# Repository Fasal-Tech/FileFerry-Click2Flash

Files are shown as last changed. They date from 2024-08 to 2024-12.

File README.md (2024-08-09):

# 🚀 FileFerry-Click2Flash

A compact and portable tool designed for easy factory programming of your IoT product. 🌐 Transfer files, binary images, security credentials, or certificates from an SD card or from a Serial terminal over USB to a target SPI flash IC with just a click of a button. 🎯

This repository contains all the necessary files to manufacture your own samples from JLCPCB (or a vendor of your choice) and start using it right away

The included firmware source code and compiled binaries can be used right out of the box! 🛠️ You can also modify the design and code and build your own custom product. ✨

## Product Image

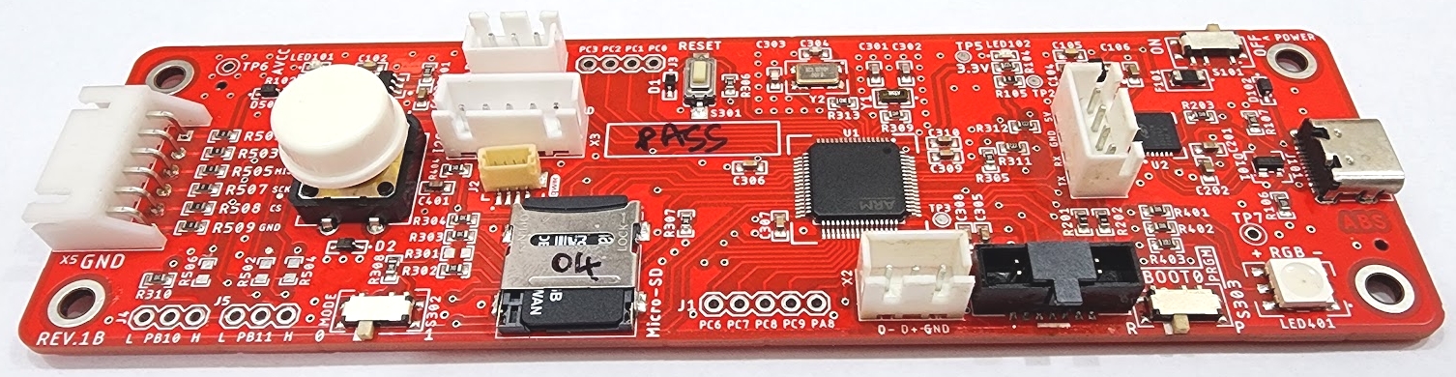
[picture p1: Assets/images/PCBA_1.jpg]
FileFerry-Click2Flash PCB

The "FileFerry-Click2Flash" PCB.

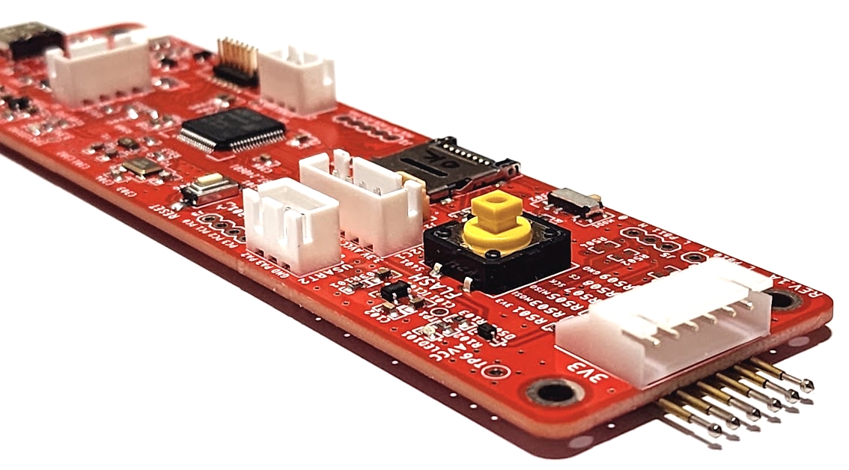
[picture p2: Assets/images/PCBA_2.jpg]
FileFerry-Click2Flash PCB with pogo pins

The "FileFerry-Click2Flash" PCB with the pogo pins.

## 📁 Repository Contents

* **/Hardware 🛠️**
  * All Eagle design files (.brd, .sch)
* **/Firmware 💻**
  * Pre-compiled binaries to flash the board
  * Firmware source code (STM32Cube IDE, HAL) that you can use to modify the functionality
* **/Manufacturing 🏭**
  * All manufacturing files, including Gerber, BOM, PnP_XY, and prototype manufacturing files (Order BOM and PnP) that can be used to order directly from JLCPCB for a complete PCBA job.
* **/Assets 📸**
  * GitHub assets like images and other resources
* **/Demo 📸**
  * Demonstration resources to compile the firmware, flash it to the "FileFerry-Click2Flash" board and use it.

## 🔍 What is FileFerry-Click2Flash?

In its simplest form, FileFerry-Click2Flash is a low-cost, portable hardware jig that allows you to flash any external SPI flash IC (like the W25Q64JVSSIQ). 🛠️

You can transfer data in one of two ways:

1. Store your file/data in the onboard micro SD card. 💾
    1. Example: Production firmware images, common security tokens, certificates, etc.
2. Transfer the files from an external computer over UART using the X-modem protocol. 🔄
    1. Example: Device-specific unique keys, device-specific CA certificates, UUID tokens, etc.

You can do all of this with just a click of the onboard button! 🎯

## 🚀 Why is "FileFerry-Click2Flash" Needed? 🛠️

In today's fast-paced manufacturing environment, the need for efficient, reliable, and cost-effective tools is paramount. Traditional methods of programming SPI flash ICs, such as using J-link SPI programmers or bed-of-nails jigs, often involve expensive, bulky, and complex setups that are not easily adaptable to different production scenarios. 😓

This is where FileFerry-Click2Flash comes in! 🎉 It addresses the gap between high-cost, inflexible tools and the need for a versatile, portable, and user-friendly solution. Whether you are flashing firmware or transferring security credentials, or unique device identifiers, FileFerry-Click2Flash offers an ultra-low-cost alternative that is not only easy to use but also highly customizable. The ability to transfer files via an onboard SD card or over UART using the X-modem protocol provides flexibility in various production environments, making it a robust and indispensable tool for manufacturers, developers, and technicians alike. ⚙️💻

With its customizable connector interface and portable design, this tool simplifies the flashing process, reducing both the time and costs associated with traditional methods. FileFerry-Click2Flash is the modern solution to the challenges faced in programming SPI flash ICs, ensuring that the process is as seamless and efficient as possible. 🖊️💡

## 💰 Manufacturing Cost Breakdown

We got 5 quantity PCBA samples from JLCPCB. (We are in no way affiliated with JLCPCB—it's just convenient to manufacture quick prototypes with them!) 🚀

* Total cost with Shipping (PCB + PCBA): $132.49 📦
* Landing cost with import duties, customs, etc.: INR 14,000.00 (for 5 pieces) 💸
* Cost per board: INR 2,800.00 (includes 6 extra pogo pins, hand soldered later) 🛠️
* At a cost of INR 2,800.00 (~ USD 33.00), we have a SPI flasher with additional functionalities like UART transfer.
  
🔄 Compare this with a J-Flash SPI programmer at ~ USD 330.00 or a Bed of nails test jig at ~ USD 500.00.
🤔 Which would you choose?

## High Level Working

Let's look at how this works.

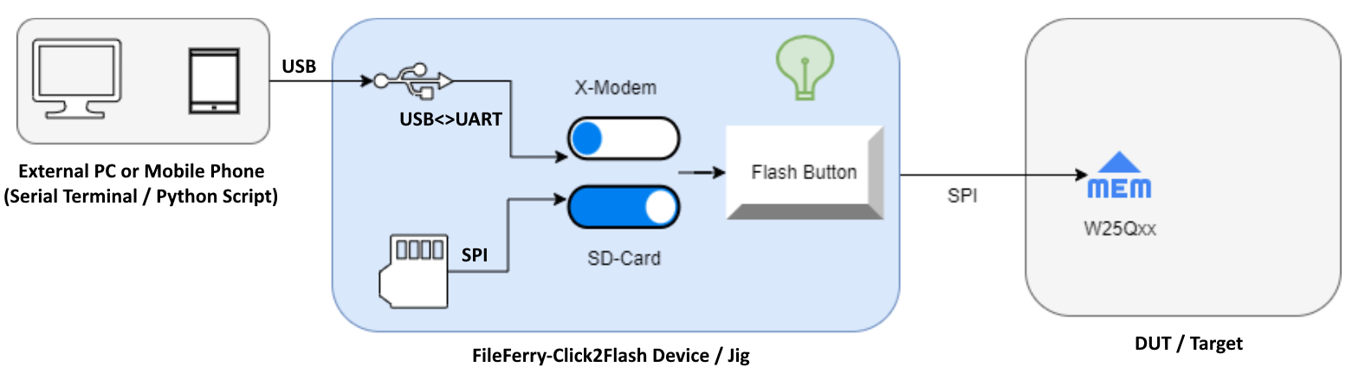
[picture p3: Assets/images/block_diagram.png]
High level block diagram

The "FileFerry-Click2Flash" system block diagram.

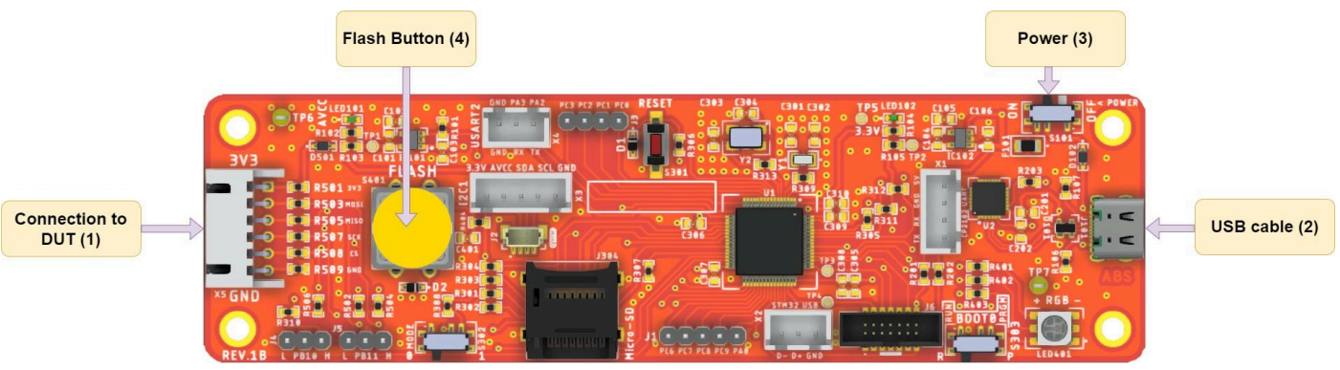
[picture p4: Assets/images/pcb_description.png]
PCB Description

The "FileFerry-Click2Flash" PCB points

### There are two ways (currently supported) to transfer files to the target SPI Flash

### 1. Using the onboard micro SD card (Files need to be on the SD card)

  1. Simple copy the file you want to transfer to the external SPI Flash into the SD card (Example a production binary)
  2. Modify the given source code to use the file name and build the code
  3. Flash the code to the "FileFerry-Click2Flash" board
  4. Insert the SD Card, power up the board and click the "Flash" button for the flashing to take place
  5. you can monitor the progress on the RGB LED as well as debug logs on the USB-UART

### 2. Using a PC client over USB (you will need a Software client to initiate transfer)

  1. No re-programming needed.
  2. Slide the "Mode Switch" S302 to "Mode 1". This will activate UART X-Modem transfer. (Current firmware supports X-modem. Can be modified to any thing else).
  3. Open a terminal program of your choice. The terminal program has to support "File Transfer" functionality.
  4. We use TeraTerm. So open TeraTerm.
  5. Connect to the proper COM port. Use BAud as 115200,8N1.
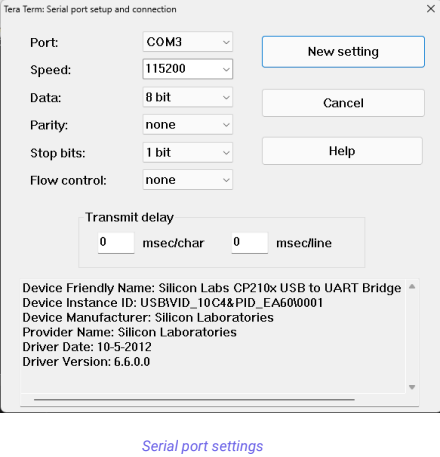
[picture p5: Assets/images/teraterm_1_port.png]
Teraterm Window
  
  Teraterm Open

  6. Go to File-> Transfer -> XMODEM -> Send -> [Check Option 1K] + Select file.
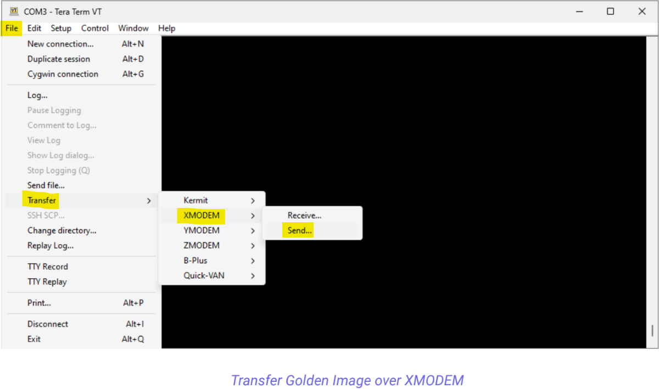
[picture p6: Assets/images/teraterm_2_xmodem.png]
Teraterm file selection
  
  Transfer setting

  7. Select your file and click "Open".
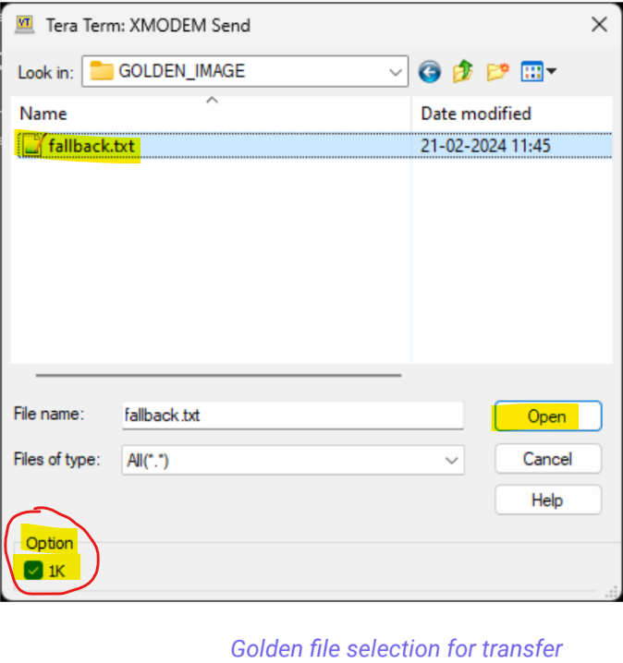
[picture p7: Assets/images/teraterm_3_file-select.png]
Teraterm file selection
  
  File Selection

  8. The file transfer will start.
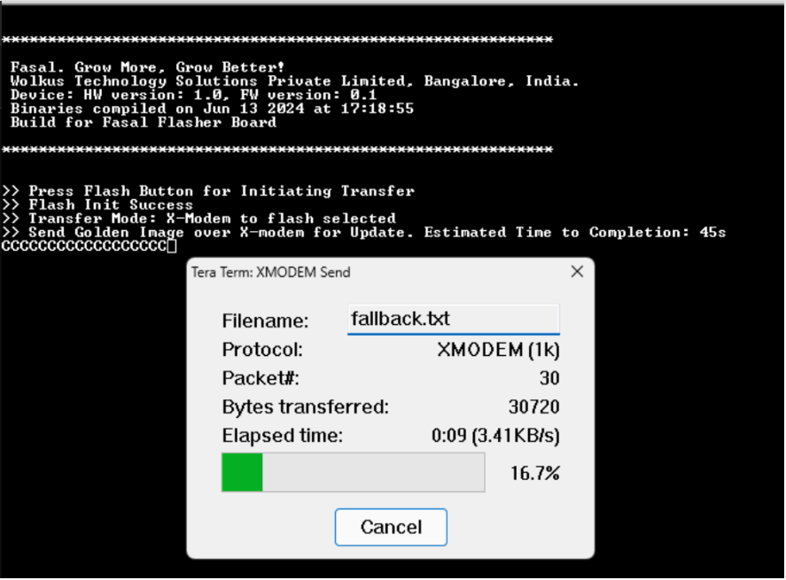
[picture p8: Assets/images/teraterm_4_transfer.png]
Teraterm file selection
  
  File Transfer

## What type of Files can I transfer?
The sky is the limit really. Some common examples are:

1. Transferring the production "Golden Image" of the product where the end product's bootloader performs a DFU from the binaries available in the Flash IC. (You can extend this for implementing OTA).
2. Transferring unique device CA certificates from a PC based on the device serial number. (Scan barcode, generate unique CA certificate in the PC application, transfer it to the device over USB UART).
3. Transferring audio files, JSON configuration files, etc.

## Can I modify the hardware?

You have the design files with you. You can do anything! If you are a student or a DIY'er, here are some ideas to use the hardware:

1. Use as a STM32F103 development kit
2. Use it as a data-logger. Examples:
   * Connect an I2C sensor (there is a QWIIC port for easy connection. There is also a JST port with controlled power) and modify the STM32 code to read from the sensor and store it in the onboard SD card.
   * You can connect a SPI sensor as well.
3. Use the additional UART2 port to connect a GPS receiver and modify the STM32 code to receive the GPS NMEA strings, parse it and store it in the onboard SD card.
4. RFID access control anyone? Interface a RFID reader over UART/I2C/SPI (RC522 or PN532 or similar), have a master list of RFID numbers stored in the SD card. Connect a relay to a free GPIO and give access control to the room.

Limitless possibilities!

## 📜 License Information
The hardware and firmware are released under the MIT License. 📝 The code is beerware; if you see me (or any other Fasal employee) at the local, and you've found our code helpful, please buy us a round! 🍻

Distributed as-is; no warranty is given. ⚠️ Read the License file for complete licensing information.

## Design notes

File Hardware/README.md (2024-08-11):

FileFerry-Click2Flash - Hardware
========================================
This directory will contain the hardware design files for the 'FileFerry-Click2Flash project.

# ECAD Tool #
Autodesk Eagle 9.6.2

# Repository Contents #
* **/Fasal-P506-Rev1B-SPI_Flash_Writer_Jig** - All Eagle design files and manufacturing files for the main product "FileFerry-Click2Flash" (.brd, .sch)
* **/Fasal-RD510 - SPI Flash Writer pogo pcb** - Eagle design files and manufacturing files for optional pogo pin PCB to create a test jig

# Hardware Bloack Diagram

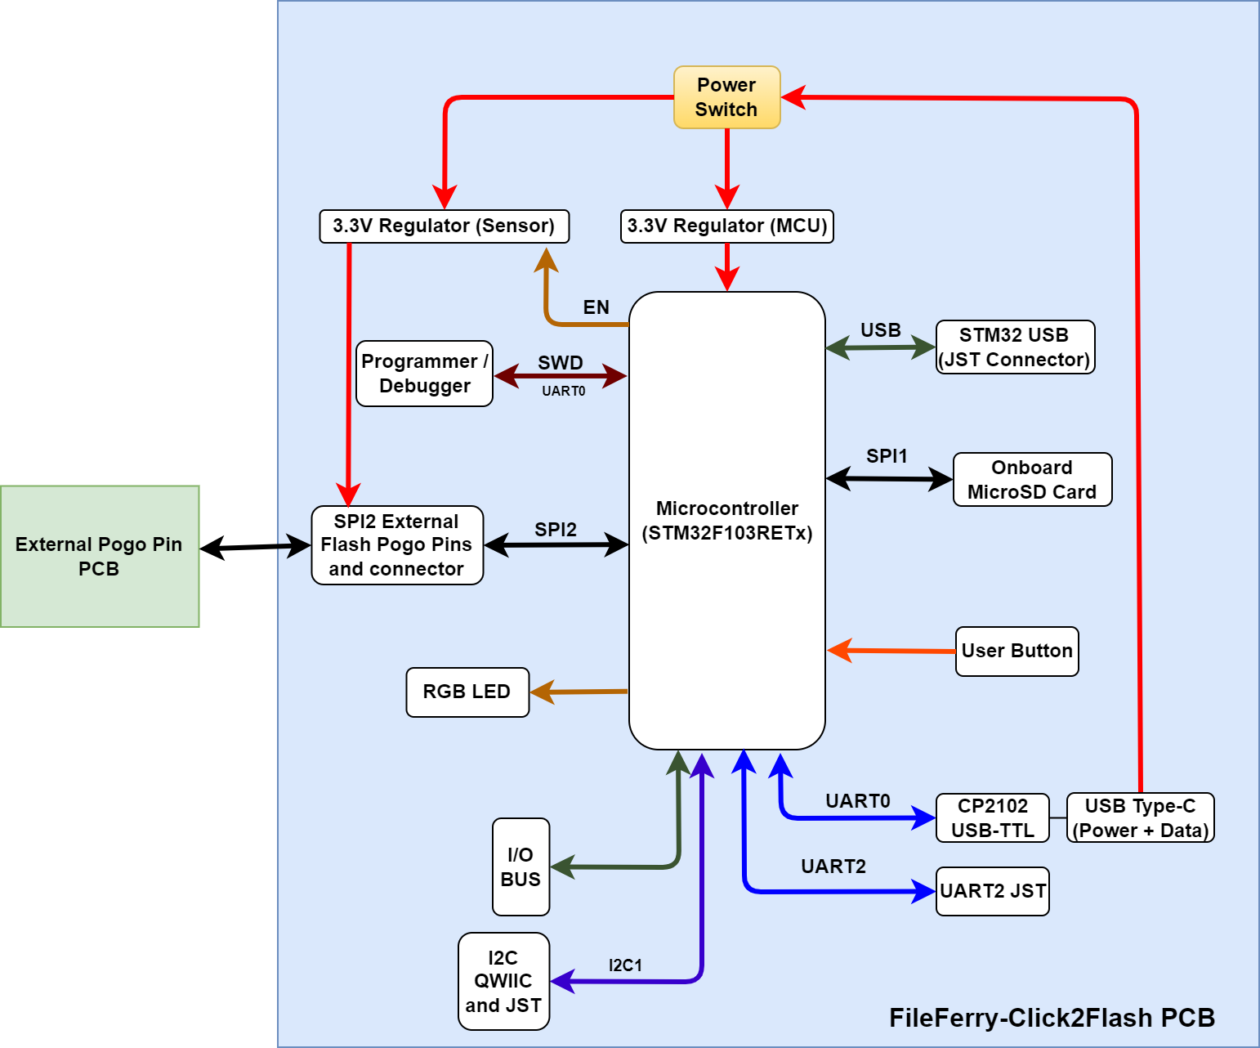
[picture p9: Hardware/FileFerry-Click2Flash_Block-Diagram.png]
Hardware Bloack Diagram


## Contact-Me

- <abhaysbharadwaj@gmail.com> over E-Mail
- [Abhay S Bharadwaj](https://www.linkedin.com/in/abhaysbharadwaj/) over LinkedIn

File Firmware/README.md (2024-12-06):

# Fasal Flasher {#mainpage}

This repository contains Fasal Flasher Source Code. Dive right into the codebase through @ref AppFasal_Run invoked in @ref main.c !

## Table of contents

- [Context](#context)
- [Project-structure](#project-structure)
- [Code-flow](#code-flow)
- [Build-Instruction](#build-instruction)
- [Documentation](#docs)
- [Contact-Me](#contact-me)

## Context

Fasal Flasher is an Internal tool meant as a production floor Aid. Its primary purpose is to update the contents flash IC
W25Qxx either with the contents of the Fasal Flasher onboard SD-Card or over a serial terminal over XModem protocol.
The device has the following salient features

1. Powered by USB either through PC, Mobile phone or any USB source
2. File Input from either Serial console through USB connector or SD-Card
3. Slide switch to select between file source of SD-Card and Serial console (X-modem)
4. The W25Qxx flash IC in external board is powered through the Fasal Flasher and programmed over SPI
5. PushButton to trigger the transfer in the configured Mode
6. Tri-Color LED for visual indication about the process result
7. Logs over the same USB cable with information about the running application
8. File Integrity check via CRC in case of SD-Card transfer mode
9. File Integrity check inbuilt via XModem protocol in case of XModem transfer mode

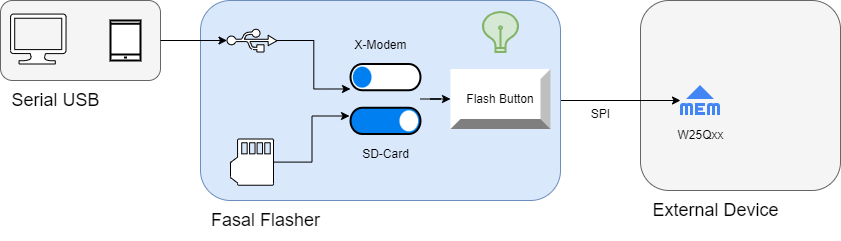
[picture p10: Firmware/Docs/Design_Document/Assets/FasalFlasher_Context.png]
Fasal Flasher Usage


## Project-structure

1. The project is divided into the following folders
2. @ref SourceCode/FasalFlasher/Core : Contains CubeMX Generated Files utilizing the STM HAL. These files are mostly unmodified and used as is
3. @ref SourceCode/FasalFlasher/Drivers : STM HAL files
4. @ref SourceCode/FasalFlasher/FATFS : FatFS library
5. @ref SourceCode/FasalFlasher/Middlewares : Contains STM crypto library and FatFS library, used as is without any modifications
6. @ref SourceCode/FasalFlasher/User_Files : All custom code for the Fasal Application is present in this folder
    1. @ref SourceCode/FasalFlasher/User_Files/AppCommon : Contains modules used across the whole application, these include
        1. @ref SourceCode/FasalFlasher/User_Files/AppCommon/AppIndication : Controls visual indication presented by the board
        2. @ref SourceCode/FasalFlasher/User_Files/AppCommon/AppUtility : Provides SoftTimer, Circular Buffer and other Misc utility functions
        3. @ref SourceCode/FasalFlasher/User_Files/AppCommon/CommonDefinitions : Non project specific data structures and Macros
        4. SourceCode/FasalFlasher/User_Files/AppCommon/ConfigSetting : Module to check Board HW configuration
        5. SourceCode/FasalFlasher/User_Files/AppCommon/PushButton : PushButton module
    2. @ref SourceCode/FasalFlasher/User_Files/AppConfiguration : Application configuration options are controlled here
    3. @ref SourceCode/FasalFlasher/User_Files/AppFasal : Application code module
        1. @ref SourceCode/FasalFlasher/User_Files/AppFasal/AppHelper : Helper functions for main application
        2. @ref SourceCode/FasalFlasher/User_Files/AppFasal/AppResetAndError : Error handling and reset management
    4. @ref SourceCode/FasalFlasher/User_Files/AppInterface : Modules that help Interface Sensor Adapter with external peripherals
        1. @ref SourceCode/FasalFlasher/User_Files/AppInterface/Console : Debug console for getting controlling as well as reading logs
        2. @ref SourceCode/FasalFlasher/User_Files/AppInterface/xModem : xModem module built on top of UART based console module
    5. @ref SourceCode/FasalFlasher/User_Files/AppInterrupts : Callbacks and other application specific callbacks coupled closely with board specific peripherals
    6. @ref SourceCode/FasalFlasher/User_Files/AppStorage : OnBoard storage module API
        1. @ref SourceCode/FasalFlasher/User_Files/AppStorage/AppFlashFS : Filesystem based on LittleFS file system built atop W25Qxx flash IC
        2. @ref SourceCode/FasalFlasher/User_Files/AppStorage/AppSDFS : Filesystem based on FatFS file system built atop SPI based SD-Card

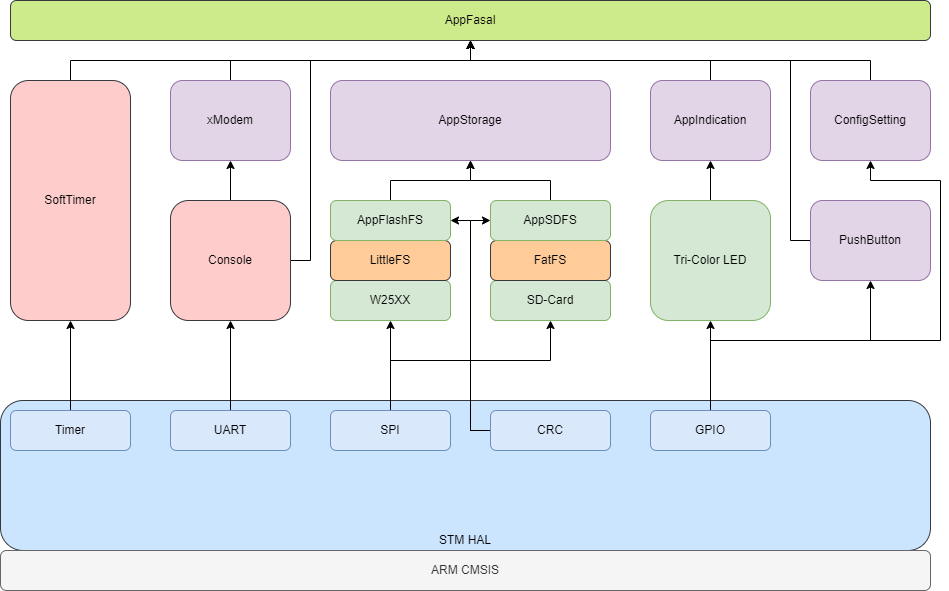
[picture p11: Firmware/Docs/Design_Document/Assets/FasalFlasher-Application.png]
Application


```text
+---BUILD_DEBUG
+---BUILD_PROD
+---Core
¦   +---Inc
¦   +---Src
¦   +---Startup
+---Drivers
¦   +---CMSIS
¦   ¦   +---Device
¦   ¦   ¦   +---ST
¦   ¦   ¦       +---STM32F1xx
¦   ¦   ¦           +---Include
¦   ¦   ¦           +---Source
¦   ¦   ¦               +---Templates
¦   ¦   +---Include
¦   +---STM32F1xx_HAL_Driver
¦       +---Inc
¦       ¦   +---Legacy
¦       +---Src
+---FATFS
¦   +---App
¦   +---Target
+---Middlewares
¦   +---Third_Party
¦       +---FatFs
¦           +---src
¦               +---option
+---User_Files
    +---AppCommon
    ¦   +---AppIndication
    ¦   ¦   +---TriColorLED
    ¦   +---AppUtility
    ¦   ¦   +---AppProfiler
    ¦   ¦   +---SoftTimer
    ¦   +---CommonDefinitions
    ¦   +---ConfigSetting
    ¦   +---PushButton
    +---AppConfiguration
    +---AppFasal
    ¦   +---AppResetAndError
    +---AppInterface
    ¦   +---Console
    ¦   +---xModem
    +---AppInterrupts
    +---AppStorage
        +---AppFlashFS
        ¦   +---LittleFS
        ¦   +---W25Qxx
        +---AppSDFS

```

## Code-flow

1. The code flow and the corresponding modules are documented in this section
2. The code starting point is @ref main. All HAL modules are initialized here along with Application level code housed in @ref AppFasal.h
3. @ref AppFasal_Init Initializes the application, sends startup message and sets up the TriColorLED, console and startup timer
4. The function @ref AppFasal_Run is the application state-machine that drives the application
    1. Module level initialization is carried out in the first step
    2. The application then waits for the user to press the flash user button
    3. External flash is then initialized before progressing to the file transfer phase
    4. Depending on the hardware slide switch setting, the device can then proceed in one of the following modes
        1. SD-Card Transfer Mode:
            1. SD-Card is initialized and it is ensured that the Golden image is present
            2. Golden image is transferred from the SD card to the external flash
            3. CRC of the same file in SD-Card and in the now transferred flash are computed and checked against each other
        2. XModem Transfer Mode:
            1. File Must be transferred over XModem 1K option though a serial terminal [Baud: 115200, Data: 8b, Stop Bit: 1b]
    5. In either mode, On successful reception of Golden Image, the Firmware then enters the termination stage, indicates success and waits on the flash user button stage
    6. In either mode failure of any of the steps prior to successful transfer results in the application state-machine indicating the failure reason and jumping back flash user button stage

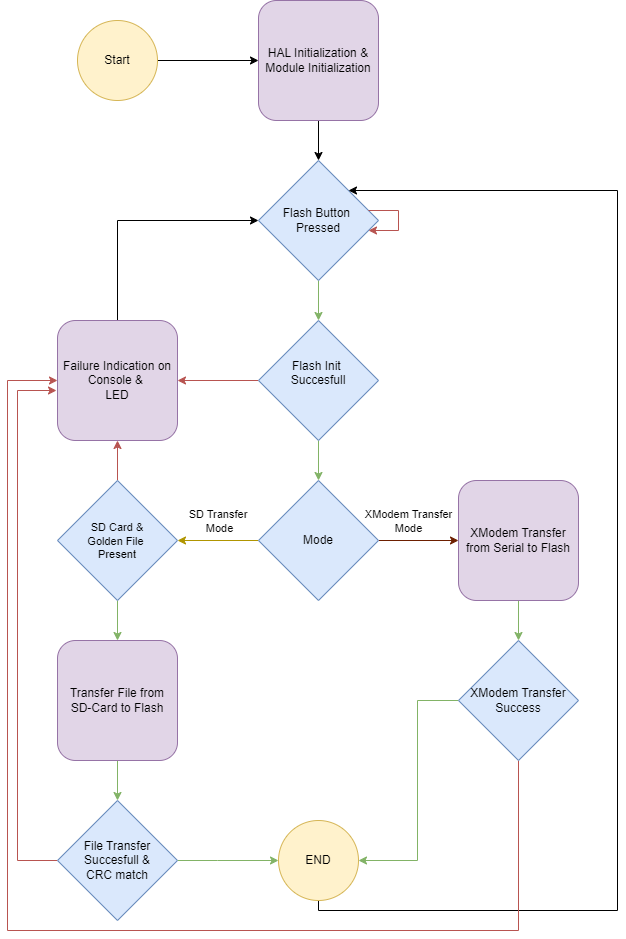
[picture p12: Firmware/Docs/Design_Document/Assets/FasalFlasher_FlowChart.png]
APP


## Build-Instruction

1. Built using CubeIDE Version: 1.15.1 Build: 21094_20240412_1041 (UTC)
2. Both BUILD_DEBUG and BUILD_PROD Uses Linker script STM32f103RETX_FLASH.ld with flash offset of 0x0800 0000, application size set to 512KB
3. The following build configurations are built into the codebase
    1. *BUILD_DEBUG* : Debug build used during development with all debug symbols enabled
        - Optimization level : None
        - Symbols defined : DEBUG | STM32F103xE | USE_HAL_DRIVER

    2. *BUILD_PROD* : Production build for filed use
        - Optimization level : Ofast
        - Symbols defined : NDEBUG | STM32F103xE | USE_HAL_DRIVER
4. @ref SourceCode/FasalFlasher/User_Files/AppCommon/AppConfiguration for changing compile time build features

## Docs

1. Open Index.html in any browser. Files located here @ref Docs/html
2. Latex Generated PDF file is preset at @ref Docs/Design_Document/FasalNode_FirmwareDesignDocument.pdf
3. The documentation can be generated by running batch script @ref make_designdocument.bat at the project root

## Contact-Me

- <vishalbhatta@gmail.com> over E-Mail
- [LinkedIn](https://in.linkedin.com/in/vishal-keshava-murthy-8a2ba1a7)

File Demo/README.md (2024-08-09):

# 🚀 FileFerry-Click2Flash Demonstration

This document demonstrates how FileFerry-click2Flash can be used for your project!

## Table of contents

- [Release_Contents_overview](#release-contents-overview)
- [Setup](#setup)
- [Usage_Instructions](#usage-instructions)
- [DiagnosticsInformation](#diagnostics-information)
- [Build-Instruction](#build-instruction)
- [Documentation](#docs)
- [Contact-Me](#contact-me)

## Context

## Release Contents overview

The prebuilt binaries released are available under the release folder @ref /Firmware/Releases is comprised of

1. APP: Application Binaries
    1. BUILD_DEBUG: Debug Build with all debug symbols and messages enabled for debugging purposes
    2. BUILD_PROD:  Production build optimized for performance. Meant for use on the production floor
2. FasalFlasher_ReleaseNote.pdf: Release Note with details about the build and usage
3. ReadMe.txt: Instructional text document that captures essential Release information

## Setup

The following steps are to be followed with a new FileFerry-Click2Flash device

### Software and tools used

1. [ST Cube Programmer](https://www.st.com/en/development-tools/stm32cubeprog.html) : To upload binaries to device
2. [TeraTerm](https://teratermproject.github.io/index-en.html) : Or equivalent serial monitor tool with XModem protocol

### External device (Target) setup

1. The external device (Target) needs to be empty prior to usage with Fasal Flasher. If a program is running on it, it will interfere with the flashing operation.
2. You can put the device in "suspend" mode. (Example: Use BOOT0 if the target has a STM32 MCU to halt program execution).
3. Alternately, erase the MCU's (or MPU's) internal Flash program.

### FileFerry-Click2Flash device SD-Card SetUp

1. The precompiled binary of the FileFerry-Click2Flash expects a file name "Fallback.txt" in the SD Card to be present. This "Fallback.txt" gets transferred to the Target SPI Flash.
2. Note: ".txt" is just a file format notation and not an actual text file. The file in the demo is a ".srec" compiled binary that can be used to perform DFU of a target STM32 MCU. The .srec compiled binary is renamed as "Fallback.txt".
3. Copy the file "Fallback.txt" into an SD-card and insert the same into the FileFerry-Click2Flash device. Please note that that any file that needs to be transferred must be named Fallback.txt for the file to be recognized by the FileFerry-Click2Flash.
4. You may change the file name expected by the FileFerry-Click2Flash, recompile the code and upload the new code to the FileFerry-Click2Flash device. You can then rename the SD card file accordingly.

### Burning the Application code to a fresh FileFerry-Click2Flash PCB

1. Insert the above SD card (with the "fallback.txt" file in it).
2. Connect a Type-C USB and slide the power switch to power on the device.
3. Connect a STLink V3 minie on the programming header.
4. Open the STM32cube Programmer.
5. First, erase the complete device using Full chip erase option under Erasing and programming section in the side-Menu
6. Select & load application file *App/PROD/FasalFlasher_Vx_y_PROD.srec* to device

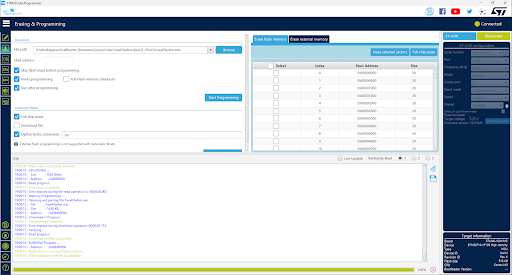
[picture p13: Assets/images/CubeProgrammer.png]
Full chip erase & Flash program


## Using the FileFerry-Click2Flash device

1. Ensure that the device is powered over USB and the power switch is ON, and that the set up is complete as instructed in the application setup 
2. The operation mode can be selected as either SD-Card mode or XModem mode though the slide switch. The two modes are described below 
3. Ensure that the device whose Flash needs to be programmed is not running any application. Disconnect the power source for the external board and connect to the flash SPI interface using the Pogo interface
4. The application state will be indicated in accordance with []

### SD-Card Mode

1. A correctly set up device will wait for the User Flash button button  
2. Once the Button is pressed the device will initialize both the onboard SD-Card interface and the external flash.
3. The files will be copied, integrity will be checked and the status will be indicated
4. The file transfer status will be indicated over LED and the console

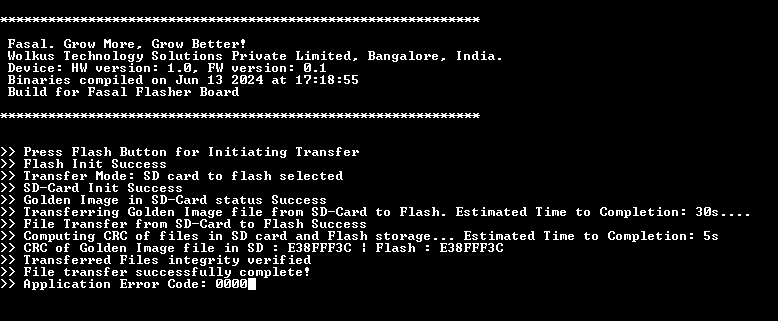
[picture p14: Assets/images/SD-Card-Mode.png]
SD-Card Mode


### XModem Mode

1. A correctly set up device will wait for the User Flash button button  
2. Once the Button is pressed the device will wait for the golden image file over the serial interface
3. Launch Serial USB terminal, select the appropriate com-port and use the following Serial settings 
    1. Baud Rate : 115200
    2. Data : 8 bit
    3. Speed : 115200
    4. Stop bits : 1 bit
    5. Flow control : none
4. The file transfer status will be indicated over LED and the console
5. XModem mode can be used either over PC though serial terminal programs like TeraTerm or cell phone over USB serial terminal.

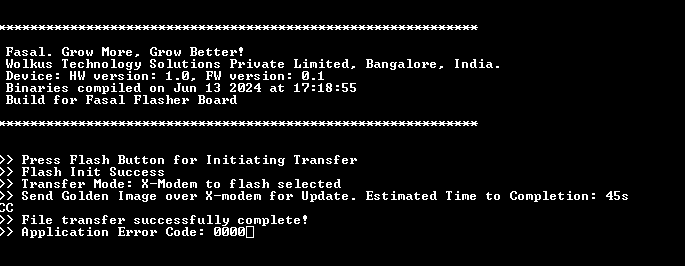
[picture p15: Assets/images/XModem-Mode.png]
X-Modem Mode


## Diagnostics Information

### App State Indication

The application status is indicated by the On board TriColor LED during program execution. The application states, their meaning and corresponding indication state is documented below

| App State | Indication |
| --- | --- |
|eFASAL_APP_INIT | eIND_BLUE_250MS |
|eFASAL_APP_BUTTON_WAIT | eIND_BLUE_500MS |
|eFASAL_APP_SD_INIT | eIND_BLUE_1000MS |
|eFASAL_APP_SD_CHECK | eIND_BLUE_1000MS |
|eFASAL_APP_FLASH_INIT | eIND_BLUE_1000MS |
|eFASAL_APP_MODE_SELECTION | eIND_BLUE_1000MS |
|eFASAL_APP_SD_FLASH_TRANSFER | eIND_YELLOW_1000MS  |
|eFASAL_APP_XMODEM_TRANSFER | eIND_YELLOW_1000MS  |
|eFASAL_APP_CRC_COMPARE | eIND_YELLOW_1000MS  |
|eFASAL_APP_TRANSFER_SUCCESS | eIND_GREEN_0 |
|eFASAL_APP_SD_FAIL | eIND_RED_250MS |
|eFASAL_APP_SD_FILE_FAIL | eIND_RED_250MS |
|eFASAL_APP_TRANSFER_FAIL | eIND_RED_250MS |
|eFASAL_APP_CRC_FAIL | eIND_RED_250MS |
|eERR_ARM_FAULT | eIND_RED_250MS |
|eFASAL_APP_END | eIND_RED_250MS |
|eFASAL_MAX_STATE | eIND_RED_250MS |

### Error Codes

The application also supporters error codes to indicate specific error conditions. These are captured below along with the indication if present

| Error Code | Error |
| --- | --- |
|0x0000 | eERR_NO_ERRORS |
|0x0001 | eERR_SDCARD_NOT_FOUND |
|0x0002 | eERR_SDCARD_FILE_NOT_FOUND |
|0x0004 | eERR_FLASH_NOT_FOUND |
|0x0008 | eERR_FLASH_TRANSFER_FAILURE  |
|0x0010 | eERR_CRC_FAILURE |
|0x1000 | eERR_STM_HAL_FAILURE |
|0x2000 | eERR_ARM_FAULT |
|0x4000 | eERR_ASSERTION_FAILURE |
|0x8000 | eERR_SLEEP_FAILURE |

## Build-Instruction
If you want to modify the firmware functionality, you can re-build the code for the FileFerry-Click2Flash device using these steps:
1. Built using CubeIDE Version: 1.15.1 Build: 21094_20240412_1041 (UTC)
2. Both BUILD_DEBUG and BUILD_PROD Uses Linker script STM32f103RETX_FLASH.ld with flash offset of 0x0800 0000, application size set to 512KB
3. The following build configurations are built into the codebase
    1. *BUILD_DEBUG* : Debug build used during development with all debug symbols enabled
        - Optimization level : None
        - Symbols defined : DEBUG | STM32F103xE | USE_HAL_DRIVER

    2. *BUILD_PROD* : Production build for filed use
        - Optimization level : Ofast
        - Symbols defined : NDEBUG | STM32F103xE | USE_HAL_DRIVER
4. @ref SourceCode/FasalFlasher/User_Files/AppCommon/AppConfiguration for changing compile time build features

## Docs

1. Doxygen files are generated under @ref Docs/html by running the following command in the current folder ```doxygen Doxyfile```
2. The files can be viewed by opening Index.html in any browser. Files located here @ref Docs/html
3. Latex Generated PDF file is preset at @ref Docs/Design_Document/FasalFlasher_FirmwareDesignDocument.pdf

## Contact-Me

- <vishalbhatta@gmail.com> over E-Mail
- [Vishal Keshava Murthy](https://www.linkedin.com/in/vishal-keshava-murthy-8a2ba1a7/) over LinkedIn

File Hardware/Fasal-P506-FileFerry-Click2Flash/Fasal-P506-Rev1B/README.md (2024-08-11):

# FileFerry-Click2Flash - Hardware Files #

This directory contains all the Hardware related files for the main "FileFerry-Click2Flash" Board.

# Repository Contents #
* **/Design_Files**
	* CubeMX Files
	* Change log
	* Design Report
	* Schematic pdf
	* Schematic Source (.sch)
	* Board Source (.brd)
* **/Manufacturing_Files**
	* PCBA BOM (Production Bill of Materials)
	* PCB Assembly Instructions
	* PCB Fabrication Instructions with stackup
	* Gerber Files (.zip)
	* PCB Images and 3D STEP file
	* Pick and Place (PnP_XY) files
* **/Proto_Manufacturing**
	* Use this to get a complete PCBA build from JLCPCB.
	* Gerber Files (same as production gerber)
	* JLCPCB SMT BOM (BOM for LCSC / JLCPCB PCBA)
	* JLCPCT CPL (compoennt placement file. SMD and THT both.)
* **/Testing_Files**
	* Board bring-up Arduino Test Code
	* Board Bring-up test case and report

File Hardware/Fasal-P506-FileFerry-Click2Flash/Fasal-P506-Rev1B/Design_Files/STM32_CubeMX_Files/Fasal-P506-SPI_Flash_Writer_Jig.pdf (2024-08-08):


24/05/2024

Fasal-P506-SPI_Flash_Writer_Jig Project Configuration Report

## 1. Description

### 1.1. Project

Project Name | Fasal-P506-SPI_Flash_Writer_Jig
Board Name | custom
Generated with: | STM32CubeMX 6.11.1
Date | 05/24/2024

### 1.2. MCU

MCU Series | STM32F1
MCU Line | STM32F103
MCU name | STM32F103RETx
MCU Package | LQFP64
MCU Pin number | 64

### 1.3. Core(s) information

Core(s) | Arm Cortex-M3

## 2. Pinout Configuration

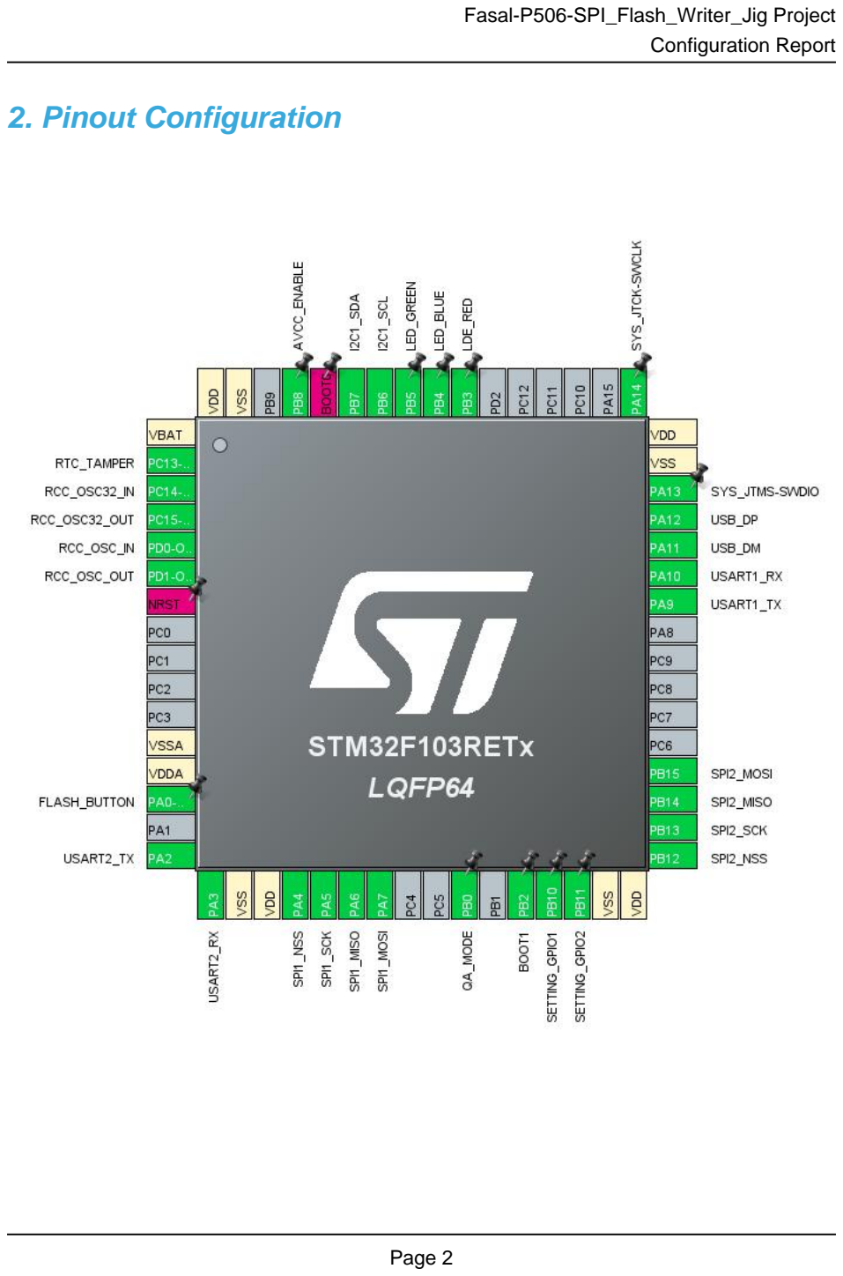
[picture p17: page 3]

## 3. Pins Configuration

Pin Number LQFP64 | Pin Name (function after reset) | Pin Type | Alternate Function(s) | Label
1 | VBAT | Power
2 | PC13-TAMPER-RTC | I/O | RTC_TAMPER
3 | PC14-OSC32_IN | I/O | RCC_OSC32_IN
4 | PC15-OSC32_OUT | I/O | RCC_OSC32_OUT
5 | PD0-OSC_IN | I/O | RCC_OSC_IN
6 | PD1-OSC_OUT | I/O | RCC_OSC_OUT
7 | NRST | Reset
12 | VSSA | Power
13 | VDDA | Power
14 | PA0-WKUP | I/O | GPIO_EXTI0 | FLASH_BUTTON
16 | PA2 | I/O | USART2_TX
17 | PA3 | I/O | USART2_RX
18 | VSS | Power
19 | VDD | Power
20 | PA4 | I/O | SPI1_NSS
21 | PA5 | I/O | SPI1_SCK
22 | PA6 | I/O | SPI1_MISO
23 | PA7 | I/O | SPI1_MOSI
26 | PB0 * | I/O | GPIO_Input | QA_MODE
28 | PB2 * | I/O | GPIO_Input | BOOT1
29 | PB10 * | I/O | GPIO_Input | SETTING_GPIO1
30 | PB11 * | I/O | GPIO_Input | SETTING_GPIO2
31 | VSS | Power
32 | VDD | Power
33 | PB12 | I/O | SPI2_NSS
34 | PB13 | I/O | SPI2_SCK
35 | PB14 | I/O | SPI2_MISO
36 | PB15 | I/O | SPI2_MOSI
42 | PA9 | I/O | USART1_TX
43 | PA10 | I/O | USART1_RX
44 | PA11 | I/O | USB_DM
45 | PA12 | I/O | USB_DP
46 | PA13 | I/O | SYS_JTMS-SWDIO
47 | VSS | Power
48 | VDD | Power
49 | PA14 | I/O | SYS_JTCK-SWCLK

Pin Number LQFP64 | Pin Name (function after reset) | Pin Type | Alternate Function(s) | Label
55 | PB3 * | I/O | GPIO_Output | LDE_RED
56 | PB4 * | I/O | GPIO_Output | LED_BLUE
57 | PB5 * | I/O | GPIO_Output | LED_GREEN
58 | PB6 | I/O | I2C1_SCL
59 | PB7 | I/O | I2C1_SDA
60 | BOOT0 | Boot
61 | PB8 * | I/O | GPIO_Output | AVCC_ENABLE
63 | VSS | Power
64 | VDD | Power

* The pin is affected with an I/O function

## 4. Clock Tree Configuration

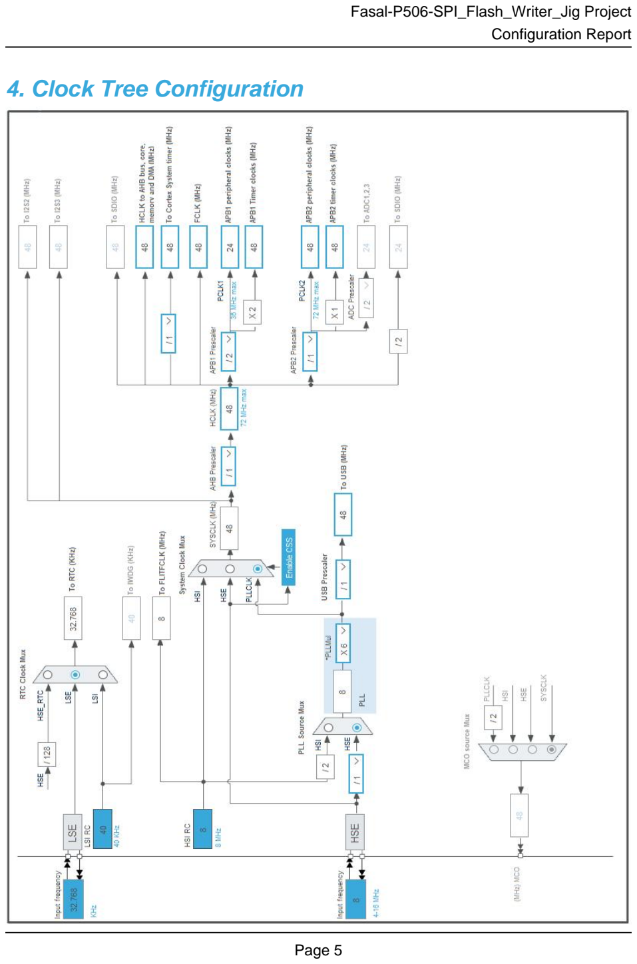
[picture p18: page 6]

## 5. Software Project

### 5.1. Project Settings

Name | Value
Project Name | Fasal-P506-SPI_Flash_Writer_Jig
Project Folder | F:\Fasal_Electronics_Design\Fasal_HW_5p0_Nova_Electronics\Fasal-P506 - SPI
Toolchain / IDE | STM32CubeIDE
Firmware Package Name and Version | STM32Cube FW_F1 V1.8.5
Application Structure | Advanced
Generate Under Root | Yes
Do not generate the main() | No
Minimum Heap Size | 0x200
Minimum Stack Size | 0x400

### 5.2. Code Generation Settings

Name | Value
STM32Cube MCU packages and embedded software | Copy only the necessary library files
Generate peripheral initialization as a pair of '.c/.h' files | No
Backup previously generated files when re-generating | No
Keep User Code when re-generating | Yes
Delete previously generated files when not re-generated | Yes
Set all free pins as analog (to optimize the power consumption) | Yes
Enable Full Assert | No

### 5.3. Advanced Settings - Generated Function Calls

Rank | Function Name | Peripheral Instance Name
1 | SystemClock_Config | RCC
2 | MX_GPIO_Init | GPIO
3 | MX_CRC_Init | CRC
4 | MX_I2C1_Init | I2C1
5 | MX_RTC_Init | RTC
6 | MX_SPI1_Init | SPI1
7 | MX_SPI2_Init | SPI2
8 | MX_USART1_UART_Init | USART1
9 | MX_USART2_UART_Init | USART2
10 | MX_FATFS_Init | FATFS
11 | MX_USB_DEVICE_Init | USB_DEVICE

## 1. Power Consumption Calculator report

### 1.1. Microcontroller Selection

Series | STM32F1
Line | STM32F103
MCU | STM32F103RETx
Datasheet | DS5792_Rev12

### 1.2. Parameter Selection

Temperature | 25
Vdd | 3.3

### 1.3. Battery Selection

Battery | Li-SOCL2(A3400)
Capacity | 3400.0 mAh
Self Discharge | 0.08 %/month
Nominal Voltage | 3.6 V
Max Cont Current | 100.0 mA
Max Pulse Current | 200.0 mA
Cells in series | 1
Cells in parallel | 1

### 1.4. Sequence

Step | Step1 | Step2
Mode | RUN | STOP
Vdd | 3.3 | 3.3
Voltage Source | Battery | Battery
Range | No Scale | No Scale
Fetch Type | FLASH | n/a
CPU Frequency | 72 MHz | 0 Hz
Clock Configuration | HSE PLL | Regulator_LP
Clock Source Frequency | 8 MHz | 0 Hz
Peripherals
Additional Cons. | 0 mA | 0 mA
Average Current | 30.5 mA | 25 µA
Duration | 0.1 ms | 0.9 ms
DMIPS | 90.0 | 0.0
Ta Max | 100.47 | 105
Category | In DS Table | In DS Table

### 1.5. Results

Sequence Time | 1 ms | Average Current | 3.07 mA
Battery Life | 1 month, 15 days, 15 hours | Average DMIPS | 61.0 DMIPS

### 1.6. Chart

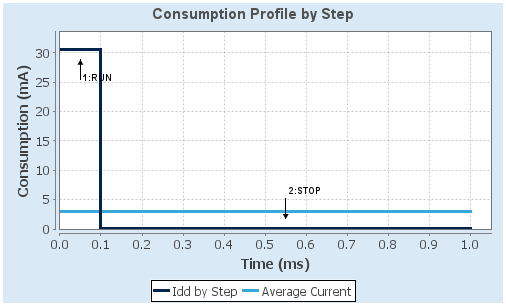
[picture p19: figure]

## 2. Peripherals and Middlewares Configuration

### 2.1. CRC

mode: Activated

### 2.2. I2C1

I2C: I2C
2.2.1. Parameter Settings:

Master Features:

I2C Speed Mode | Standard Mode
I2C Clock Speed (Hz) | 100000
Slave Features:
Clock No Stretch Mode | Disabled
Primary Address Length selection | 7-bit
Dual Address Acknowledged | Disabled
Primary slave address | 0
General Call address detection | Disabled

### 2.3. RCC

High Speed Clock (HSE): Crystal/Ceramic Resonator Low Speed Clock (LSE) : Crystal/Ceramic Resonator
2.3.1. Parameter Settings:

System Parameters:

VDD voltage (V) | 3.3
Prefetch Buffer | Enabled
Flash Latency(WS) | 1 WS (2 CPU cycle)
RCC Parameters:
HSI Calibration Value | 16
HSE Startup Timout Value (ms) | 100
LSE Startup Timout Value (ms) | 5000

### 2.4. RTC

mode: Activate Clock Source

mode: Tamper
2.4.1. Parameter Settings:

Calendar Time:

Data Format | BCD data format
General:
Auto Predivider Calculation | Enabled
Asynchronous Predivider value | Automatic Predivider Calculation Enabled
Output | No output on the TAMPER pin
Tamper:
Tamper Trigger | Rising Edge

### 2.5. SPI1

Mode: Full-Duplex Master
Hardware NSS Signal: Hardware NSS Output Signal
2.5.1. Parameter Settings:

Basic Parameters:

Frame Format | Motorola
Data Size | 8 Bits
First Bit | MSB First
Clock Parameters:
Prescaler (for Baud Rate) | 4 *
Baud Rate | 12.0 MBits/s *
Clock Polarity (CPOL) | Low
Clock Phase (CPHA) | 1 Edge
Advanced Parameters:
CRC Calculation | Disabled
NSS Signal Type | Output Hardware

### 2.6. SPI2

Mode: Full-Duplex Master
Hardware NSS Signal: Hardware NSS Output Signal
2.6.1. Parameter Settings:

Basic Parameters:

Frame Format | Motorola
Data Size | 8 Bits
First Bit | MSB First
Clock Parameters:
Prescaler (for Baud Rate) | 2
Baud Rate | 12.0 MBits/s *
Clock Polarity (CPOL) | Low
Clock Phase (CPHA) | 1 Edge
Advanced Parameters:
CRC Calculation | Disabled
NSS Signal Type | Output Hardware

### 2.7. SYS

Debug: Serial Wire
Timebase Source: SysTick

### 2.8. USART1

Mode: Asynchronous
2.8.1. Parameter Settings:

Basic Parameters:

Baud Rate | 115200
Word Length | 8 Bits (including Parity)
Parity | None
Stop Bits | 1
Advanced Parameters:
Data Direction | Receive and Transmit
Over Sampling | 16 Samples

### 2.9. USART2

Mode: Asynchronous
2.9.1. Parameter Settings:

Basic Parameters:

Baud Rate | 115200
Word Length | 8 Bits (including Parity)
Parity | None

Stop Bits | 1
Advanced Parameters:
Data Direction | Receive and Transmit
Over Sampling | 16 Samples

### 2.10. USB

mode: Device (FS)
2.10.1. Parameter Settings:

Basic Parameters:

Speed | Full Speed 12MBit/s
Power Parameters:
Low Power | Disabled
Link Power Management | Disabled
Battery Charging | Disabled

### 2.11. FATFS

mode: User-defined
2.11.1. Set Defines:

Version:

FATFS version | R0.11
Function Parameters:
FS_READONLY (Read-only mode) | Disabled
FS_MINIMIZE (Minimization level) | Disabled
USE_STRFUNC (String functions) | Enabled with LF -> CRLF conversion
USE_FIND (Find functions) | Disabled
USE_MKFS (Make filesystem function) | Enabled
USE_FASTSEEK (Fast seek function) | Enabled
USE_LABEL (Volume label functions) | Disabled
USE_FORWARD (Forward function) | Disabled
Locale and Namespace Parameters:
CODE_PAGE (Code page on target) | Multilingual Latin 1 (OEM)
USE_LFN (Use Long Filename) | Disabled
MAX_LFN (Max Long Filename) | 255
LFN_UNICODE (Enable Unicode) | ANSI/OEM
STRF_ENCODE (Character encoding) | UTF-8

FS_RPATH (Relative Path) | Disabled
Physical Drive Parameters:
VOLUMES (Logical drives) | 1
MAX_SS (Maximum Sector Size) | 512
MIN_SS (Minimum Sector Size) | 512
MULTI_PARTITION (Volume partitions feature) | Disabled
USE_TRIM (Erase feature) | Disabled
FS_NOFSINFO (Force full FAT scan) | 0
System Parameters:
FS_TINY (Tiny mode) | Disabled
FS_NORTC (Timestamp feature) | Dynamic timestamp
WORD_ACCESS (Platform dependent access option) | Byte access
FS_REENTRANT (Re-Entrancy) | Disabled
FS_TIMEOUT (Timeout ticks) | 1000
FS_LOCK (Number of files opened simultaneously) | 2

### 2.12. USB_DEVICE

Class For FS IP: Mass Storage Class
2.12.1. Parameter Settings:

Basic Parameters:

USBD_MAX_NUM_INTERFACES (Maximum number of supported interfaces) | 1
USBD_MAX_NUM_CONFIGURATION (Maximum number of supported configuration) | 1
USBD_MAX_STR_DESC_SIZ (Maximum size for the string descriptors) | 512
USBD_SELF_POWERED (Enabled self power) | Enabled
USBD_DEBUG_LEVEL (USBD Debug Level) | 0: No debug message
Class Parameters:
MSC_MEDIA_PACKET (Media I/O buffer Size) | 512
2.12.2. Device Descriptor:

Device Descriptor:

VID (Vendor IDentifier) | 1150 *
LANGID_STRING (Language Identifier) | English(United States)
MANUFACTURER_STRING (Manufacturer Identifier) | Fasal *
Device Descriptor FS:
PID (Product IDentifier) | 22314
PRODUCT_STRING (Product Identifier) | Fasal Mass Storage *

CONFIGURATION_STRING (Configuration Identifier) | MSC Config
INTERFACE_STRING (Interface Identifier) | MSC Interface

* User modified value

## 3. System Configuration

### 3.1. GPIO configuration

IP | Pin | Signal | GPIO mode | GPIO pull/up pull down

Max
Speed

User Label

I2C1 | PB6 | I2C1_SCL | Alternate Function Open
Drain
n/a | High *
PB7 | I2C1_SDA | Alternate Function Open
Drain
n/a | High *
RCC | PC14-
OSC32_IN
RCC_OSC32_IN | n/a | n/a | n/a

PC15-
OSC32_OU
T

RCC_OSC32_O
UT
n/a | n/a | n/a

PD0-
OSC_IN
RCC_OSC_IN | n/a | n/a | n/a

PD1-
OSC_OUT
RCC_OSC_OUT | n/a | n/a | n/a
RTC | PC13-
TAMPER-RTC
RTC_TAMPER | n/a | n/a | n/a
SPI1 | PA4 | SPI1_NSS | Alternate Function Push Pull | n/a | High *
| PA5 | SPI1_SCK | Alternate Function Push Pull | n/a | High *
| PA6 | SPI1_MISO | Input mode | No pull-up and no pull-down | n/a
| PA7 | SPI1_MOSI | Alternate Function Push Pull | n/a | High *
SPI2 | PB12 | SPI2_NSS | Alternate Function Push Pull | n/a | High *
| PB13 | SPI2_SCK | Alternate Function Push Pull | n/a | High *
| PB14 | SPI2_MISO | Input mode | No pull-up and no pull-down | n/a
| PB15 | SPI2_MOSI | Alternate Function Push Pull | n/a | High *
SYS | PA13 | SYS_JTMS- SWDIO | n/a | n/a | n/a
| PA14 | SYS_JTCK- SWCLK | n/a | n/a | n/a
USART1 | PA9 | USART1_TX | Alternate Function Push Pull | n/a | High *
| PA10 | USART1_RX | Input mode | No pull-up and no pull-down | n/a
USART2 | PA2 | USART2_TX | Alternate Function Push Pull | n/a | High *
| PA3 | USART2_RX | Input mode | No pull-up and no pull-down | n/a
USB | PA11 | USB_DM | n/a | n/a | n/a
| PA12 | USB_DP | n/a | n/a | n/a
GPIO | PA0-WKUP | GPIO_EXTI0 | External Interrupt Mode with Rising edge trigger detection
No pull-up and no pull-down | n/a | FLASH_BUTTON

IP | Pin | Signal | GPIO mode | GPIO pull/up pull down | Max Speed | User Label
| PB0 | GPIO_Input | Input mode | No pull-up and no pull-down | n/a | QA_MODE
| PB2 | GPIO_Input | Input mode | No pull-up and no pull-down | n/a | BOOT1
| PB10 | GPIO_Input | Input mode | No pull-up and no pull-down | n/a | SETTING_GPIO1
| PB11 | GPIO_Input | Input mode | No pull-up and no pull-down | n/a | SETTING_GPIO2
| PB3 | GPIO_Output | Output Push Pull | No pull-up and no pull-down | Low | LDE_RED
| PB4 | GPIO_Output | Output Push Pull | No pull-up and no pull-down | Low | LED_BLUE
| PB5 | GPIO_Output | Output Push Pull | No pull-up and no pull-down | Low | LED_GREEN
| PB8 | GPIO_Output | Output Push Pull | No pull-up and no pull-down | Low | AVCC_ENABLE

### 3.2. DMA configuration

nothing configured in DMA service

### 3.3. NVIC configuration

3.3.1. NVIC
Interrupt Table | Enable | Preenmption Priority | SubPriority
Non maskable interrupt | true | 0 | 0
Hard fault interrupt | true | 0 | 0
Memory management fault | true | 0 | 0
Prefetch fault, memory access fault | true | 0 | 0
Undefined instruction or illegal state | true | 0 | 0
System service call via SWI instruction | true | 0 | 0
Debug monitor | true | 0 | 0
Pendable request for system service | true | 0 | 0
System tick timer | true | 15 | 0
RCC global interrupt | true | 0 | 0
USB low priority or CAN RX0 interrupts | true | 0 | 0
PVD interrupt through EXTI line 16 | | unused
Tamper interrupt | | unused
RTC global interrupt | | unused
Flash global interrupt | | unused
EXTI line0 interrupt | | unused
USB high priority or CAN TX interrupts | | unused
I2C1 event interrupt | | unused
I2C1 error interrupt | | unused
SPI1 global interrupt | | unused
SPI2 global interrupt | | unused
USART1 global interrupt | | unused
USART2 global interrupt | | unused
3.3.2. NVIC Code generation

Enabled interrupt Table Select for init
sequence ordering
| | Generate IRQ
| | handler | Call HAL handler
Non maskable interrupt | false | true | false
Hard fault interrupt | false | true | false
Memory management fault | false | true | false
Prefetch fault, memory access fault | false | true | false
Undefined instruction or illegal state | false | true | false
System service call via SWI instruction | false | true | false
Debug monitor | false | true | false
Pendable request for system service | false | true | false
System tick timer | false | true | true
RCC global interrupt | false | true | false

Enabled interrupt Table | Select for init sequence ordering | Generate IRQ handler | Call HAL handler
USB low priority or CAN RX0 interrupts | false | true | true

* User modified value

## 4. System Views

4.1. Category view
4.1.1. Current

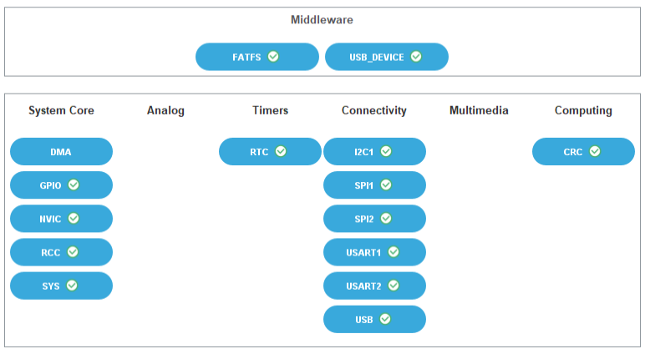
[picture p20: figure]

## 5. Docs & Resources

Type | Link
BSDL files | https://www.st.com/resource/en/bsdl_model/stm32f1_bsdl.zip
IBIS models | https://www.st.com/resource/en/ibis_model/stm32ibis.zip
System View Description | https://www.st.com/resource/en/svd/stm32f1_svd.zip
Presentations | https://www.st.com/resource/en/product_presentation/stm32-stm8_embedded_software_solutions.pdf
Presentations | https://www.st.com/resource/en/product_presentation/stm32_eval-tools_portfolio.pdf
Presentations | https://www.st.com/resource/en/product_presentation/stm32_stm8_functi onal-safety-packages.pdf
Presentations | https://www.st.com/resource/en/product_presentation/stm32-stm8_software_development_tools.pdf
Presentations | https://www.st.com/resource/en/product_presentation/microcontrollers-stm32-family-overview.pdf
Brochures | https://www.st.com/resource/en/brochure/products-and-solutions-for-plcs-and-smart-i-os.pdf
Flyers | https://www.st.com/resource/en/flyer/flstm32nucleo.pdf
Flyers | https://www.st.com/resource/en/flyer/flstmcsuite.pdf
Flyers | https://www.st.com/resource/en/flyer/fldpstpfc11120.pdf
Product Certifications | https://www.st.com/resource/en/certification_document/1239988349.pdf
Product Certifications | https://www.st.com/resource/en/certification_document/stm32_authentication_can.pdf
Application Notes | https://www.st.com/resource/en/application_note/an1181-electrostatic-discharge-sensitivity-measurement-stmicroelectronics.pdf
Application Notes | https://www.st.com/resource/en/application_note/an1709-emc-design-guide-for-stm8-stm32-and-legacy-mcus-stmicroelectronics.pdf
Application Notes | https://www.st.com/resource/en/application_note/an2586-getting-started-with-stm32f10xxx-hardware-development-stmicroelectronics.pdf

Application Notes | https://www.st.com/resource/en/application_note/an2606-stm32-microcontroller-system-memory-boot-mode-stmicroelectronics.pdf
Application Notes | https://www.st.com/resource/en/application_note/an2639-soldering-recommendations-and-package-information-for-leadfree-ecopack-mcus-and-mpus-stmicroelectronics.pdf
Application Notes | https://www.st.com/resource/en/application_note/an2784-using-the-highdensity-stm32f10xxx-fsmc-peripheral-to-drive-external-memories-stmicroelectronics.pdf
Application Notes | https://www.st.com/resource/en/application_note/an2945-stm8s-and-stm32-mcus-a-consistent-832bit-product-line-for-painless-migration-stmicroelectronics.pdf
Application Notes | https://www.st.com/resource/en/application_note/an3070-managing-the-driver-enable-signal-for-rs485-and-iolink-communications-with-the-stm32s-usart-stmicroelectronics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
Application Notes | https://www.st.com/resource/en/application_note/an3095-stevalisv002v1-stevalisv002v2-3-kw-gridconnected-pv-system-based-on-the-stm32f103xx-stmicroelectronics.pdf
Application Notes | https://www.st.com/resource/en/application_note/an3108-stlm75-firmware-library-for-the-stm32f10x-stmicroelectronics.pdf
Application Notes | https://www.st.com/resource/en/application_note/an3126-audio-and-waveform-generation-using-the-dac-in-stm32-products-stmicroelectronics.pdf
Application Notes | https://www.st.com/resource/en/application_note/an3128-stm32-embedded-graphic-objectstouchscreen-library-stmicroelectronics.pdf
Application Notes | https://www.st.com/resource/en/application_note/an3154-can-protocol-used-in-the-stm32-bootloader-stmicroelectronics.pdf
Application Notes | https://www.st.com/resource/en/application_note/an3155-usart-protocol-used-in-the-stm32-bootloader-stmicroelectronics.pdf
Application Notes | https://www.st.com/resource/en/application_note/an3156-usb-dfu-protocol-used-in-the-stm32-bootloader-stmicroelectronics.pdf
Application Notes | https://www.st.com/resource/en/application_note/an3364-migration-and-compatibility-guidelines-for-stm32-microcontroller-applications-stmicroelectronics.pdf

Application Notes | https://www.st.com/resource/en/application_note/an3422-migration-of-microcontroller-applications-from-stm32f1-to-stm32l1-series-stmicroelectronics.pdf
Application Notes | https://www.st.com/resource/en/application_note/an3427-migrating-a-microcontroller-application-from-stm32f1-to-stm32f2-series-stmicroelectronics.pdf
Application Notes | https://www.st.com/resource/en/application_note/an3429-stm32-proprietary-code-protection-overview-stmicroelectronics.pdf
Application Notes | https://www.st.com/resource/en/application_note/an4013-stm32-crossseries-timer-overview-stmicroelectronics.pdf
Application Notes | https://www.st.com/resource/en/application_note/an4070-250-w-grid-connected-microinverter-stmicroelectronics.pdf
Application Notes | https://www.st.com/resource/en/application_note/an4076-two-or-three-shunt-resistor-based-current-sensing-circuit-design-in-3phase-inverters-stmicroelectronics.pdf
Application Notes | https://www.st.com/resource/en/application_note/an4088-migrating-between-stm32f1-and-stm32f0-series-microcontrollers-stmicroelectronics.pdf
Application Notes | https://www.st.com/resource/en/application_note/an4228-migrating-from-stm32f1-series-to-stm32f3-series-microcontrollers-stmicroelectronics.pdf
Application Notes | https://www.st.com/resource/en/application_note/an4229-how-to-implement-a-vocoder-solution-using-stm32-microcontrollers-stmicroelectronics.pdf
Application Notes | https://www.st.com/resource/en/application_note/an4277-using-stm32-device-pwm-shutdown-features-for-motor-control-and-digital-power-conversion-stmicroelectronics.pdf
Application Notes | https://www.st.com/resource/en/application_note/an4566-extending-the-dac-performance-of-stm32-microcontrollers-stmicroelectronics.pdf
Application Notes | https://www.st.com/resource/en/application_note/an4649-migrating-from-stm32f1-series-to-stm32l4-series--stm32l4-series-microntrollers-stmicroelectronics.pdf
Application Notes | https://www.st.com/resource/en/application_note/an4655-virtually-increasing-the-number-of-serial-communication-peripherals-in-stm32-applications-stmicroelectronics.p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

Application Notes | https://www.st.com/resource/en/application_note/an4724-stm32cube-firmware-examples-for-stm32f1-series-stmicroelectronics.pdf
Application Notes | https://www.st.com/resource/en/application_note/an4750-handling-of-soft-errors-in-stm32-applications-stmicroelectronics.pdf
Application Notes | https://www.st.com/resource/en/application_note/an4776-generalpurpose-timer-cookbook-for-stm32-microcontrollers-stmicroelectronics.pdf
Application Notes | https://www.st.com/resource/en/application_note/an4803-highspeed-si-simulations-using-ibis-and-boardlevel-simulations-using-hyperlynx-si-on-stm32-mcus-and-mpus-stmic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
Application Notes | https://www.st.com/resource/en/application_note/an4904-migration-of-microcontroller-applications-from-stm32f1-series-to-stm32f4-access-lines-stmicroelectronics.pdf
Application Notes | https://www.st.com/resource/en/application_note/an4908-stm32-usart-automatic-baud-rate-detection-stmicroelectronics.pdf
Application Notes | https://www.st.com/resource/en/application_note/an4989-stm32-microcontroller-debug-toolbox-stmicroelectronics.pdf
Application Notes | https://www.st.com/resource/en/application_note/an5027-interfacing-pdm-digital-microphones-using-stm32-mcus-and-mpus-stmicroelectronics.pdf
Application Notes | https://www.st.com/resource/en/application_note/an5543-enhanced-methods-to-handle-spi-communication-on-stm32-devices-stmicroelectronics.pdf
Application Notes | https://www.st.com/resource/en/application_note/an4899-stm32-microcontroller-gpio-hardware-settings-and-lowpower-consumption-stmicroelectronics.pdf
Application Notes | https://www.st.com/resource/en/application_note/an5612-esd-protection-of-stm32-mcus-and-mpus-stmicroelectronics.pdf
Application Notes | https://www.st.com/resource/en/application_note/an5156-introduction-to-stm32-microcontrollers-security-stmicroelectronics.pdf
Application Notes | https://www.st.com/resource/en/application_note/an2548-using-the-stm32f0f1f3cxgxlx-series-dma-controller-stmicroelectronics.pdf
Application Notes | https://www.st.com/resource/en/application_note/an4838-introduction-to-memory-protection-unit-management-on-stm32-mcus-stmicroelectronics.pdf

Application Notes | https://www.st.com/resource/en/application_note/an4879-introduction-to-usb-hardware-and-pcb-guidelines-using-stm32-mcus-stmicroelectronics.pdf
Application Notes | https://www.st.com/resource/en/application_note/an5225-introduction-to-usb-typec-power-delivery-for-stm32-mcus-and-mpus-stmicroelectronics.pdf
Application Notes | https://www.st.com/resource/en/application_note/an2834-how-to-optimize-the-adc-accuracy-in-the-stm32-mcus-stmicroelectronics.pdf
Application Notes | https://www.st.com/resource/en/application_note/an5816-how-to-build-stm32-lpbam-application-using-stm32cubemx-stmicroelectronics.pdf
Application Notes | https://www.st.com/resource/en/application_note/an5537-how-to-use-adc-oversampling-techniques-to-improve-signaltonoise-ratio-on-stm32-mcus-stmicroelectronics.pdf
Application Notes | https://www.st.com/resource/en/application_note/an5036-guidelines-for-thermal-management-on-stm32-applications-stmicroelectronics.pdf
Application Notes for related Tools & Software | https://www.st.com/resource/en/application_note/an1202_freertos_guide-freertos-guide-stmicroelectronics.pdf
Application Notes for related Tools & Software | https://www.st.com/resource/en/application_note/an1602_semihosting_in_truestudio-how-to-do-semihosting-in-truestudio-stmicroelectronics.pdf
Application Notes for related Tools & Software | https://www.st.com/resource/en/application_note/an1801_stm32cubeprogrammer_in_truestudio-installing-stm32cubeprogrammer-in-truestudio-stmicroelectronics.pdf
Application Notes for related Tools & Software | https://www.st.com/resource/en/application_note/atollic_editing_keyboard_shortcuts-atollic-editing-keyboard-shortcuts-stmicroelectronics.pdf
Application Notes for related Tools & Software | https://www.st.com/resource/en/application_note/iar_to_atollic_truestudio_migration_guide-truestudio-for-arm-migration-guide-iar-embedded-workbench-to-truestudio-stm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
Application Notes for related Tools & Software | https://www.st.com/resource/en/application_note/stm32cubemx_installation_in_truestudio-stm32cubemx-installation-in-truestudio-stmicroelectronics.pdf
Application Notes | https://www.st.com/resource/en/application_note/an2557-stm32f10x-

for related Tools & Software | inapplication-programming-using-the-usart-stmicroelectronics.pdf
Application Notes for related Tools & Software | https://www.st.com/resource/en/application_note/an2592-achieving-32bit-timer-resolution-with-software-expansion-for-stm32cube-and-standard-peripheral-library-stmicro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
Application Notes for related Tools & Software | https://www.st.com/resource/en/application_note/an2594-eeprom-emulation-in-stm32f10x-microcontrollers-stmicroelectronics.pdf
Application Notes for related Tools & Software | https://www.st.com/resource/en/application_note/an2598-smartcard-interface-with-stm32f10x-and-stm32l1xx-microcontrollers-stmicroelectronics.pdf
Application Notes for related Tools & Software | https://www.st.com/resource/en/application_note/an2629-stm32f101xx-stm32f102xx-and-stm32f103xx-lowpower-modes-stmicroelectronics.pdf
Application Notes for related Tools & Software | https://www.st.com/resource/en/application_note/an2656-stm32f10xxx-lcd-glass-driver-firmware-stmicroelectronics.pdf
Application Notes for related Tools & Software | https://www.st.com/resource/en/application_note/an2668-improving-stm32f1-series-stm32f3-series-and-stm32lx-series-adc-resolution-by-oversampling-stmicroelectronics.p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
Application Notes for related Tools & Software | https://www.st.com/resource/en/application_note/an2739-how-to-use-the-highdensity-stm32f103xx-microcontroller-to-play-audio-files-with-an-external-is-audio-codec-stm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
Application Notes for related Tools & Software | https://www.st.com/resource/en/application_note/an2784-using-the-highdensity-stm32f10xxx-fsmc-peripheral-to-drive-external-memories-stmicroelectronics.pdf
Application Notes for related Tools & Software | https://www.st.com/resource/en/application_note/an2790-tft-lcd-interfacing-with-the-highdensity-stm32f10xxx-fsmc-stmicroelectronics.pdf
Application Notes for related Tools & Software | https://www.st.com/resource/en/application_note/an2820-driving-bipolar-stepper-motors-using-a-mediumdensity-stm32f103xx-microcontroller-stmicroelectronics.pdf

Application Notes
for related Tools

https://www.st.com/resource/en/application_note/an2821-clockcalendarimplementation-on-the-stm32f10xxx-microcontroller-rtc-

& Software | stmicroelectronics.pdf
Application Notes for related Tools & Software | https://www.st.com/resource/en/application_note/an2824-stm32f10xxx-ic-optimized-examples-stmicroelectronics.pdf
Application Notes for related Tools & Software | https://www.st.com/resource/en/application_note/an2841-led-dimming-implemented-on-stm32-microcontroller-stmicroelectronics.pdf
Application Notes for related Tools & Software | https://www.st.com/resource/en/application_note/an2868-stm32f10xxx-internal-rc-oscillator-hsi-calibration-stmicroelectronics.pdf
Application Notes for related Tools & Software | https://www.st.com/resource/en/application_note/an2931-implementing-the-adpcm-algorithm-in-highdensity-stm32f103xx-microcontrollers-stmicroelectronics.pdf
Application Notes for related Tools & Software | https://www.st.com/resource/en/application_note/an2953-how-to-migrate-from-the-stm32f10xxx-firmware-library-v203-to-the-stm32f10xxx-standard-peripheral-library-v300-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
Application Notes for related Tools & Software | https://www.st.com/resource/en/application_note/an3012-getting-started-with-uclinux-for-stm32f10x-highdensity-devices-stmicroelectronics.pdf
Application Notes for related Tools & Software | https://www.st.com/resource/en/application_note/an3078-stm32-inapplication-programming-over-the-ic-bus-stmicroelectronics.pdf
Application Notes for related Tools & Software | https://www.st.com/resource/en/application_note/an3109-communication-peripheral-fifo-emulation-with-dma-and-dma-timeout-in-stm32f10x-microcontrollers-stmicroelectron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
Application Notes for related Tools & Software | https://www.st.com/resource/en/application_note/an3116-stm32s-adc-modes-and-their-applications-stmicroelectronics.pdf
Application Notes for related Tools & Software | https://www.st.com/resource/en/application_note/an3174-implementing-receivers-for-infrared-remote-control-protocols-using-stm32f10xxx-microcontrollers-stmicroelectro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
Application Notes for related Tools & Software | https://www.st.com/resource/en/application_note/an3240-ultrasound-hv-pulser-demonstration-board-stmicroelectronics.pdf

Application Notes for related Tools & Software | https://www.st.com/resource/en/application_note/an3241-qvga-tftlcd-direct-drive-using-the-stm32f10xx-fsmc-peripheral-stmicroelectronics.pdf
Application Notes for related Tools & Software | https://www.st.com/resource/en/application_note/an3307-guidelines-for-obtaining-iec-60335-class-b-certification-for-any-stm32-application-stmicroelectronics.pdf
Application Notes for related Tools & Software | https://www.st.com/resource/en/application_note/an3970-plm-smartplug-v2-getting-started-stmicroelectronics.pdf
Application Notes for related Tools & Software | https://www.st.com/resource/en/application_note/an3991-how-to-drive-multiple-stepper-motors-with-the-l6470-motor-driver-stmicroelectronics.pdf
Application Notes for related Tools & Software | https://www.st.com/resource/en/application_note/an4075-stevalifp016v2-iolink-communication-master-transceiver-demonstration-board-stmicroelectronics.pdf
Application Notes for related Tools & Software | https://www.st.com/resource/en/application_note/an4323-getting-started-with-stemwin-library-stmicroelectronics.pdf
Application Notes for related Tools & Software | https://www.st.com/resource/en/application_note/an4435-guidelines-for-obtaining-ulcsaiec-607301603351-class-b-certification-in-any-stm32-application-stmicroelectroni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
Application Notes for related Tools & Software | https://www.st.com/resource/en/application_note/an4453-implementing-the-adpcm-algorithm-in-stm32l1xx-microcontrollers-stmicroelectronics.pdf
Application Notes for related Tools & Software | https://www.st.com/resource/en/application_note/an4499-stm32--nrf51822-bluetooth-low-energy-system-solution-stmicroelectronics.pdf
Application Notes for related Tools & Software | https://www.st.com/resource/en/application_note/an4578-16channels-led-driver-with-independent-pwm-dimming-control-based-on-led7708-stmicroelectronics.pdf
Application Notes for related Tools & Software | https://www.st.com/resource/en/application_note/an4657-stm32-inapplication-programming-iap-using-the-usart-stmicroelectronics.pdf
Application Notes | https://www.st.com/resource/en/application_note/an4724-stm32cube-

for related Tools & Software | firmware-examples-for-stm32f1-series-stmicroelectronics.pdf
Application Notes for related Tools & Software | https://www.st.com/resource/en/application_note/an4841-digital-signal-processing-for-stm32-microcontrollers-using-cmsis-stmicroelectronics.pdf
Application Notes for related Tools & Software | https://www.st.com/resource/en/application_note/an5054-secure-programming-using-stm32cubeprogrammer-stmicroelectronics.pdf
Application Notes for related Tools & Software | https://www.st.com/resource/en/application_note/an5360-getting-started-with-projects-based-on-the-stm32mp1-series-in-stm32cubeide-stmicroelectronics.pdf
Application Notes for related Tools & Software | https://www.st.com/resource/en/application_note/an5361-getting-started-with-projects-based-on-dualcore-stm32h7-microcontrollers-in-stm32cubeide-stmicroelectronics.pd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
Application Notes for related Tools & Software | https://www.st.com/resource/en/application_note/an5394-getting-started-with-projects-based-on-the-stm32l5-series-in-stm32cubeide-stmicroelectronics.pdf
Application Notes for related Tools & Software | https://www.st.com/resource/en/application_note/an5418-how-to-build-a-simple-usbpd-sink-application-with-stm32cubemx-stmicroelectronics.pdf
Application Notes for related Tools & Software | https://www.st.com/resource/en/application_note/an5426-migrating-graphics-middleware-projects-from-stm32cubemx-540-to-stm32cubemx-550-stmicroelectronics.pdf
Application Notes for related Tools & Software | https://www.st.com/resource/en/application_note/an5564-getting-started-with-projects-based-on-dualcore-stm32wl-microcontrollers-in-stm32cubeide-stmicroelectronics.pd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
Application Notes for related Tools & Software | https://www.st.com/resource/en/application_note/an5698-adapting-the-xcubestl-functional-safety-package-for-stm32-iec-61508-compliant-to-other-safety-standards-stmicr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
Application Notes for related Tools & Software | https://www.st.com/resource/en/application_note/an5731-stm32cubemx-and-stm32cubeide-threadsafe-solution-stmicroelectronics.pdf

Application Notes
for related Tools

https://www.st.com/resource/en/application_note/an4502-stm32-smbuspmbus-expansion-package-for-stm32cube-stmicroelectronics.pdf

& Software
Application Notes for related Tools & Software | https://www.st.com/resource/en/application_note/an5952-how-to-use-cmake-in-stm32cubeide-stmicroelectronics.pdf
Device Option Lists | https://www.st.com/resource/en/device_option_list/opl_stm32f103_512k.zi p
Errata Sheets | https://www.st.com/resource/en/errata_sheet/es0340-stm32f101xcde-stm32f103xcde-device-errata-stmicroelectronics.pdf
Datasheet | https://www.st.com/resource/en/datasheet/cd00191185.pdf
Programming Manuals | https://www.st.com/resource/en/programming_manual/pm0056-stm32f10xxx20xxx21xxxl1xxxx-cortexm3-programming-manual-stmicroelectronics.pdf
Programming Manuals | https://www.st.com/resource/en/programming_manual/pm0075-stm32f10xxx-flash-memory-microcontrollers-stmicroelectronics.pdf
Reference Manuals | https://www.st.com/resource/en/reference_manual/rm0008-stm32f101xx-stm32f102xx-stm32f103xx-stm32f105xx-and-stm32f107xx-advanced-armbased-32bit-mcus-stmicroelectronic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
Technical Notes & Articles | https://www.st.com/resource/en/technical_note/tn0516-overview-of-the-stm32f0xf100xxf103xx-and-stm32f2xxf30xf4xx-mcus-pmsm-singledual-foc-sdk-v40-stmicroelectronics.p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
Technical Notes & Articles | https://www.st.com/resource/en/technical_note/tn1163-description-of-wlcsp-for-microcontrollers-and-recommendations-for-its-use-stmicroelectronics.pdf
Technical Notes & Articles | https://www.st.com/resource/en/technical_note/tn1204-tape-and-reel-shipping-media-for-stm32-microcontrollers-in-bga-packages-stmicroelectronics.pdf
Technical Notes & Articles | https://www.st.com/resource/en/technical_note/tn1205-tape-and-reel-shipping-media-for-stm8-and-stm32-microcontrollers-in-fpn-packages-stmicroelectronics.pdf
Technical Notes & Articles | https://www.st.com/resource/en/technical_note/tn1206-tape-and-reel-shipping-media-for-stm8-and-stm32-microcontrollers-in-qfp-packages-stmicroelectronics.pdf
Technical Notes | https://www.st.com/resource/en/technical_note/tn1207-tape-and-reel-

& Articles | shipping-media-for-stm8-and-stm32-microcontrollers-in-so-packages-stmicroelectronics.pdf
Technical Notes & Articles | https://www.st.com/resource/en/technical_note/tn1208-tape-and-reel-shipping-media-for-stm8-and-stm32-microcontrollers-in-tssop-and-ssop-packages-stmicroelectronics.p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
Technical Notes & Articles | https://www.st.com/resource/en/technical_note/tn1433-reference-device-marking-schematics-for-stm32-microcontrollers-and-microprocessors-stmicroelectronics.pdf
Technical Notes & Articles | https://www.st.com/resource/en/technical_note/tn1489-security-bulletin-tn1489stpsirt-physical-attacks-on-stm32-and-stm32cube-firmware-stmicroelectronics.pdf
User Manuals | https://www.st.com/resource/en/user_manual/um1561-stevalisv003v1-firmware-user-manual-stmicroelectronics.pdf
User Manuals | https://www.st.com/resource/en/user_manual/um1573-st7540-power-line-modem-firmware-stack-stmicroelectronics.pdf

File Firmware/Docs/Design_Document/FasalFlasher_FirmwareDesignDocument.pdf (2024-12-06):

## Fasal Flasher

1.0

Generated by Doxygen 1.9.7

i

1 Fasal Flasher | 1
2 Data Structure Index | 7
3 File Index | 9
4 Data Structure Documentation | 13

Generated by Doxygen

ii

5 File Documentation | 31

iii

iv

v

vi

vii

5.33.2.4 SoftTimer_timeToTicks() | | 95
5.33.2.5 SoftTimer_Init() | | 96
5.33.2.6 __attribute__() | | 97
5.33.2.7 SoftTimer_DeInit() | | 97
5.33.2.8 SoftTimer_Register() | | 97
5.33.2.9 SoftTimer_Start() | | 98
5.33.2.10 SoftTimer_Pause() | | 98
5.33.2.11 SoftTimer_StartAll() | | 99
5.33.2.12 SofTimer_IsExpired() | | 99
5.33.2.13 SoftTimer_AperiodicTimerSet() | 100
5.33.2.14 SoftTimer_HasAperiodicTimerExpired() | 100
5.33.2.15 SoftTimer_DelayMS() | 101
5.33.2.16 SoftTimer_GetCurrentMSTick() | 101
5.33.3 Variable Documentation | 102
5.33.3.1 gvSoftTimers | 102
5.34 SoftTimer.h File Reference | 102
5.34.1 Detailed Description | 103
5.34.2 Enumeration Type Documentation | 103
5.34.2.1 eSoftTimerID_t | 103
5.34.3 Function Documentation | 103
5.34.3.1 SoftTimer_Register() | 103
5.34.3.2 SoftTimer_Init() | 104
5.34.3.3 SoftTimer_DeInit() | 105
5.34.3.4 SoftTimer_Start() | 105
5.34.3.5 SoftTimer_Pause() | 105
5.34.3.6 SoftTimer_AperiodicTimerSet() | 105
5.34.3.7 SoftTimer_DelayMS() | 106
5.34.3.8 SoftTimer_cbPeriodicCheck() | 106
5.34.3.9 SofTimer_IsExpired() | 107
5.34.3.10 SoftTimer_HasAperiodicTimerExpired() | 107
5.34.3.11 SoftTimer_GetCurrentMSTick() | 108
5.35 SoftTimer.h | 108
5.36 Utility.h File Reference | 109
5.36.1 Detailed Description | 109
5.37 Utility.h | 110
5.38 CommonDefinitions.h File Reference | 110
5.38.1 Detailed Description | 110
5.39 CommonDefinitions.h | 111
5.40 CommonInterrupts.c File Reference | 111
5.40.1 Detailed Description | 112
5.40.2 Function Documentation | 112
5.40.2.1 HAL_UART_RxCpltCallback() | 112

viii

5.40.2.2 HAL_TIM_PeriodElapsedCallback() | 112
5.41 CommonInterrupts.h | 113
5.42 ConfigSetting.c File Reference | 113
5.42.1 Detailed Description | 114
5.42.2 Function Documentation | 114
5.42.2.1 ConfigSetting_GetCurrentSetting() | 114
5.42.3 Variable Documentation | 114
5.42.3.1 gcConfigSettingHelper | 114
5.43 ConfigSetting.h File Reference | 114
5.43.1 Detailed Description | 115
5.43.2 Function Documentation | 115
5.43.2.1 ConfigSetting_GetCurrentSetting() | 115
5.44 ConfigSetting.h | 115
5.45 Console.c File Reference | 116
5.45.1 Detailed Description | 116
5.45.2 Function Documentation | 117
5.45.2.1 Console_cbCommandReceived() | 117
5.45.2.2 Console_Init() | 117
5.45.2.3 Console_DeInit() | 118
5.45.2.4 Console_TransmitChar() | 118
5.45.2.5 Console_Print() | 118
5.45.2.6 Console_receive() | 119
5.45.2.7 Console_PrintProgressBar() | 120
5.45.2.8 Console_IsCommandRaised() | 120
5.45.2.9 Console_RaiseConsoleCmdRequest() | 120
5.45.2.10 Console_Sync() | 121
5.45.3 Variable Documentation | 121
5.45.3.1 gDataBuffer | 121
5.45.3.2 gConsoleCommandHelperTable | 121
5.45.3.3 gvElevatedPromptData | 121
5.46 Console.c File Reference | 121
5.46.1 Detailed Description | 122
5.46.2 Function Documentation | 122
5.46.2.1 Console_cbCommandReceived() | 122
5.46.2.2 Console_Init() | 123
5.46.2.3 Console_DeInit() | 123
5.46.2.4 Console_TransmitChar() | 123
5.46.2.5 Console_Print() | 123
5.46.2.6 Console_receive() | 124
5.46.2.7 Console_PrintProgressBar() | 124
5.46.2.8 Console_PrintLineBreak() | 125
5.46.2.9 Console_PrintDelimiter() | 125

ix

5.46.2.10 Console_IsCommandRaised() | 126
5.46.2.11 Console_RaiseConsoleCmdRequest() | 126
5.46.2.12 Console_Sync() | 126
5.46.3 Variable Documentation | 126
5.46.3.1 gConsoleCommandHelperTable | 126
5.47 Console.h File Reference | 127
5.47.1 Detailed Description | 128
5.47.2 Macro Definition Documentation | 128
5.47.2.1 CONSOLE_BUFFER_SIZE | 128
5.47.3 Typedef Documentation | 128
5.47.3.1 pfConsoleCommandActor_t | 128
5.47.4 Enumeration Type Documentation | 128
5.47.4.1 eConsolePrintStatus_t | 128
5.47.4.2 eConsoleCommandsEnum_t | 128
5.47.4.3 eConsolePrintLevel_t | 129
5.47.5 Function Documentation | 129
5.47.5.1 Console_Init() | 129
5.47.5.2 Console_DeInit() | 129
5.47.5.3 Console_TransmitChar() | 129
5.47.5.4 Console_Print() | 129
5.47.5.5 Console_receive() | 130
5.47.5.6 Console_cbCommandReceived() | 131
5.47.5.7 Console_IsCommandRaised() | 131
5.47.5.8 Console_RaiseConsoleCmdRequest() | 131
5.47.5.9 Console_Sync() | 132
5.47.5.10 Console_PrintProgressBar() | 132
5.48 AppCommon/Console/Console.h | 132
5.49 Console.h File Reference | 133
5.49.1 Detailed Description | 134
5.49.2 Typedef Documentation | 134
5.49.2.1 pfConsoleCommandActor_t | 134
5.49.3 Enumeration Type Documentation | 134
5.49.3.1 eConsolePrintStatus_t | 134
5.49.3.2 eConsoleCommandsEnum_t | 135
5.49.3.3 eConsolePrintLevel_t | 135
5.49.4 Function Documentation | 135
5.49.4.1 Console_TransmitChar() | 135
5.49.4.2 Console_Print() | 135
5.49.4.3 Console_receive() | 137
5.49.4.4 Console_Init() | 137
5.49.4.5 Console_DeInit() | 137
5.49.4.6 Console_cbCommandReceived() | 138

x

xi

5.58.2.2 eDeviceErrorCode_t | 153
5.58.3 Function Documentation | 153
5.58.3.1 AppCommon_AccumlateErrorCode() | 153
5.58.3.2 AppCommon_ResetErrorCode() | 153
5.58.3.3 AppCommon_GetStatusString() | 154
5.58.3.4 AppCommon_GetErrorCode() | 154
5.59 AppResetAndError.h | 155
5.60 xmodem.c File Reference | 155
5.60.1 Detailed Description | 156
5.60.2 Function Documentation | 156
5.60.2.1 xmodem_computeCRC() | 156
5.60.2.2 xmodem_handlePacket() | 157
5.60.2.3 xmodem_errorHandler() | 158
5.60.2.4 xmodem_API_receive() | 158
5.61 xmodem.c File Reference | 159
5.61.1 Detailed Description | 160
5.61.2 Function Documentation | 160
5.61.2.1 xmodem_computeCRC() | 160
5.61.2.2 xmodem_handlePacket() | 161
5.61.2.3 xmodem_errorHandler() | 162
5.61.2.4 xmodem_API_receive() | 163
5.61.3 Variable Documentation | 163
5.61.3.1 gxModemPacketNumber | 163
5.61.3.2 gxModemIsFirstPacket | 163
5.62 xmodem.h File Reference | 164
5.62.1 Detailed Description | 164
5.62.2 Macro Definition Documentation | 165
5.62.2.1 X_SOH | 165
5.62.2.2 X_STX | 165
5.62.2.3 X_EOT | 165
5.62.2.4 X_ACK | 165
5.62.2.5 X_NAK | 165
5.62.2.6 X_CAN | 165
5.62.2.7 X_C | 165
5.62.3 Enumeration Type Documentation | 165
5.62.3.1 xmodem_status | 165
5.62.4 Function Documentation | 166
5.62.4.1 xmodem_API_receive() | 166
5.63 AppInterface/xModem/xmodem.h | 166
5.64 xmodem.h File Reference | 167
5.64.1 Detailed Description | 168
5.64.2 Macro Definition Documentation | 168

xii

5.64.2.1 X_SOH | 168
5.64.2.2 X_STX | 168
5.64.2.3 X_EOT | 168
5.64.2.4 X_ACK | 169
5.64.2.5 X_NAK | 169
5.64.2.6 X_CAN | 169
5.64.2.7 X_C | 169
5.64.3 Enumeration Type Documentation | 169
5.64.3.1 xmodem_status | 169
5.64.4 Function Documentation | 170
5.64.4.1 xmodem_API_receive() | 170
5.65 xModem/xmodem.h | 171
5.66 AppInterrupts.c File Reference | 171
5.66.1 Detailed Description | 172
5.66.2 Function Documentation | 172
5.66.2.1 AppISR_PreResetRoutine() | 172
5.66.2.2 AppISR_HALErrorHandler() | 173
5.66.2.3 AppISR_ARMHandler() | 173
5.66.2.4 __assert_func() | 174
5.66.2.5 HAL_UART_RxCpltCallback() | 174
5.66.2.6 HAL_TIM_PeriodElapsedCallback() | 174
5.67 AppInterrupts.h File Reference | 176
5.67.1 Detailed Description | 176
5.67.2 Macro Definition Documentation | 177
5.67.2.1 LOOP_FOREVER | 177
5.67.3 Function Documentation | 177
5.67.3.1 AppISR_HALErrorHandler() | 177
5.67.3.2 AppISR_ARMHandler() | 177
5.67.3.3 __assert_func() | 178
5.68 AppInterrupts.h | 178
5.69 AppFlash_API.c File Reference | 178
5.69.1 Detailed Description | 179
5.69.2 Function Documentation | 180
5.69.2.1 FlashFS_GetInstance() | 180
5.69.2.2 FlashFS_Init() | 180
5.69.2.3 __attribute__() | 181
5.69.2.4 FlashFs_OpenFileRaw() | 181
5.69.2.5 FlashFs_CloseFileRaw() | 182
5.69.2.6 FlashFs_ReadFileRaw() | 183
5.69.2.7 FlashFs_WriteFileRaw() | 183
5.69.2.8 FlashFs_DeleteFile() | 184
5.69.2.9 FlashFs_ComputeFileCRC() | 184

xiii

5.69.2.10 FlashFs_API_Init() | 185
5.69.2.11 FlashFs_API_OpenGoldenImageFile() | 186
5.69.2.12 FlashFs_API_WriteToGoldenImageFile() | 187
5.69.2.13 FlashFs_API_CloseGoldenImageFile() | 188
5.69.2.14 FlashFs_API_DeleteGoldenImageFile() | 189
5.69.2.15 FlashFs_API_ComputeGoldenImageFileCRC() | 189
5.69.3 Variable Documentation | 190
5.69.3.1 gcOpModeToLittleFSModeConverterTable | 190
5.69.3.2 gcFilesNamesTable | 190
5.70 AppFlash_API.h File Reference | 191
5.70.1 Detailed Description | 191
5.70.2 Function Documentation | 192
5.70.2.1 FlashFs_API_Init() | 192
5.70.2.2 FlashFs_API_OpenGoldenImageFile() | 192
5.70.2.3 FlashFs_API_WriteToGoldenImageFile() | 193
5.70.2.4 FlashFs_API_CloseGoldenImageFile() | 194
5.70.2.5 FlashFs_API_DeleteGoldenImageFile() | 195
5.70.2.6 FlashFs_API_ComputeGoldenImageFileCRC() | 195
5.71 AppFlash_API.h | 196
5.72 lfs.h | 197
5.73 lfs_util.h | 205
5.74 LittleFS_Wrapper.c File Reference | 208
5.74.1 Detailed Description | 209
5.74.2 Function Documentation | 209
5.74.2.1 lfs_device_prog() | 209
5.74.2.2 lfs_device_erase() | 210
5.74.2.3 lfs_device_sync() | 210
5.74.2.4 lfsWrapper_Init() | 210
5.74.3 Variable Documentation | 211
5.74.3.1 cfg | 211
5.75 LittleFS_Wrapper.h File Reference | 211
5.75.1 Detailed Description | 212
5.75.2 Function Documentation | 212
5.75.2.1 lfsWrapper_Init() | 212
5.76 LittleFS_Wrapper.h | 213
5.77 W25Qxx.c File Reference | 213
5.77.1 Detailed Description | 214
5.78 W25Qxx.h File Reference | 214
5.78.1 Detailed Description | 216
5.79 W25Qxx.h | 216
5.80 AppSD_API.c File Reference | 218
5.80.1 Detailed Description | 219

xiv

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

xv

Index | 249

# Chapter 1

# Fasal Flasher

This repository contains Fasal Flasher Source Code. Dive right into the codebase through AppFasal_Run invoked in main.c !

## 1.1 Table of contents

- Context
- Project-structure
- Code-flow
- Build-Instruction
- Documentation
- Contact-Me

## 1.2 Context

Fasal Flasher is an Internal tool meant as a production floor Aid. Its primary purpose is to update the contents flash IC W25Qxx either with the contents of the Fasal Flasher onboard SD-Card or over a serial terminal over XModem protocol. The device has the following salient features

1. Powered by USB either through PC, Mobile phone or any USB source
2. File Input from either Serial console through USB connector or SD-Card
3. Slide switch to select between file source of SD-Card and Serial console (X-modem)
4. The W25Qxx flash IC in external board is powered through the Fasal Flasher and programmed over SPI
5. PushButton to trigger the transfer in the configured Mode
6. Tri-Color LED for visual indication about the process result
7. Logs over the same USB cable with information about the running application
8. File Integrity check via CRC in case of SD-Card transfer mode

### 2 Fasal Flasher

9. File Integrity check inbuilt via XModem protocol in case of XModem transfer mode

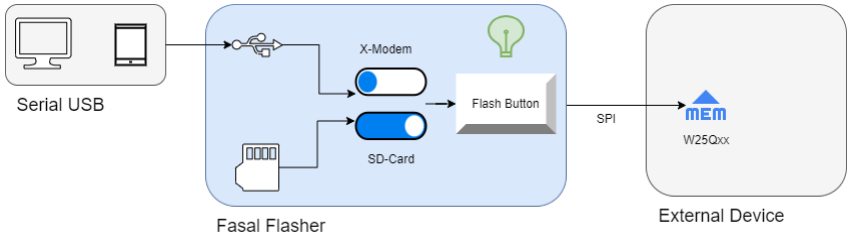
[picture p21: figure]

Figure 1.1 Fasal Flasher Usage

## 1.3 Project-structure

1. The project is divided into the following folders
2. SourceCode/FasalFlasher/Core : Contains CubeMX Generated Files utilizing the STM HAL. These files are mostly unmodified and used as is
3. SourceCode/FasalFlasher/Drivers : STM HAL files
4. SourceCode/FasalFlasher/FATFS : FatFS library
5. SourceCode/FasalFlasher/Middlewares : Contains STM crypto library and FatFS library, used as is without any modifications
6. SourceCode/FasalFlasher/User_Files : All custom code for the Fasal Application is present in this folder
(a) SourceCode/FasalFlasher/User_Files/AppCommon : Contains modules used across the whole application, these include
i. SourceCode/FasalFlasher/User_Files/AppCommon/AppIndication : Controls visual indication pre-sented by the board
ii. SourceCode/FasalFlasher/User_Files/AppCommon/AppUtility : Provides SoftTimer, Circular Buffer and other Misc utility functions
iii. SourceCode/FasalFlasher/User_Files/AppCommon/CommonDefinitions : Non project specific data structures and Macros
iv. SourceCode/FasalFlasher/User_Files/AppCommon/ConfigSetting : Module to check Board HW configuration
v. SourceCode/FasalFlasher/User_Files/AppCommon/PushButton : PushButton module
(b) SourceCode/FasalFlasher/User_Files/AppConfiguration : Application configuration options are con-trolled here
(c) SourceCode/FasalFlasher/User_Files/AppFasal : Application code module
i. SourceCode/FasalFlasher/User_Files/AppFasal/AppHelper : Helper functions for main application ii. SourceCode/FasalFlasher/User_Files/AppFasal/AppResetAndError : Error handling and reset management
(d) SourceCode/FasalFlasher/User_Files/AppInterface : Modules that help Interface Sensor Adapter with external peripherals
i. SourceCode/FasalFlasher/User_Files/AppInterface/Console : Debug console for getting controlling as well as reading logs
ii. SourceCode/FasalFlasher/User_Files/AppInterface/xModem : xModem module built on top of UART based console module

1.3 Project-structure | 3
(e) SourceCode/FasalFlasher/User_Files/AppInterrupts : Callbacks and other application specific callbacks coupled closely with board specific peripherals
(f) SourceCode/FasalFlasher/User_Files/AppStorage : OnBoard storage module API
i. SourceCode/FasalFlasher/User_Files/AppStorage/AppFlashFS : Filesystem based on LittleFS file system built atop W25Qxx flash IC
ii. SourceCode/FasalFlasher/User_Files/AppStorage/AppSDFS : Filesystem based on FatFS file system built atop SPI based SD-Card

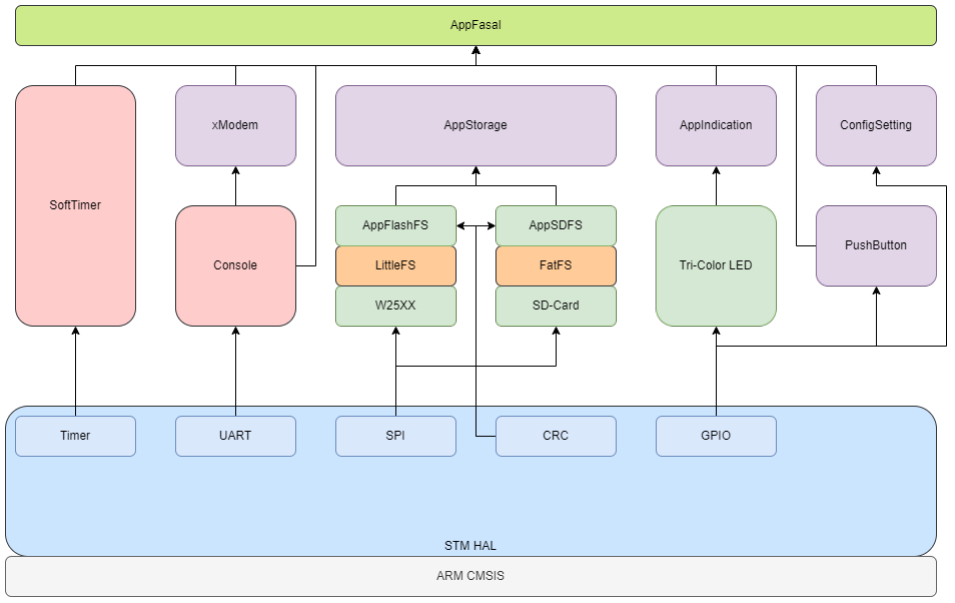
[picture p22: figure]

Figure 1.2 Application

+---BUILD_DEBUG
+---BUILD_PROD
+---Core
¦ | +---Inc
¦ | +---Src
¦ | +---Startup
+---Drivers
¦ | +---CMSIS
¦ | ¦ | +---Device
¦ | ¦ | ¦ | +---ST
¦ | ¦ | ¦ | +---STM32F1xx
¦ | ¦ | ¦ | +---Include
¦ | ¦ | ¦ | +---Source
¦ | ¦ | ¦ | +---Templates
¦ | ¦ | +---Include
¦ | +---STM32F1xx_HAL_Driver
¦ | +---Inc
¦ | | ¦ | +---Legacy
¦ | +---Src
+---FATFS
¦ | +---App
¦ | +---Target
+---Middlewares
¦ | +---Third_Party
¦ | +---FatFs
¦ | | | +---src
¦ | | | +---option
+---User_Files
+---AppCommon
¦ | +---AppIndication
| ¦ | ¦ | +---TriColorLED
¦ | +---AppUtility
| ¦ | ¦ | +---AppProfiler
| ¦ | ¦ | +---SoftTimer

### 4 Fasal Flasher

¦ | +---CommonDefinitions
¦ | +---ConfigSetting
¦ | +---PushButton
+---AppConfiguration
+---AppFasal
¦ +---AppResetAndError
+---AppInterface
¦ | +---Console
¦ | +---xModem
+---AppInterrupts
+---AppStorage
+---AppFlashFS
¦ | +---LittleFS
¦ | +---W25Qxx
+---AppSDFS

## 1.4 Code-flow

1. The code flow and the corresponding modules are documented in this section
2. The code starting point is main. All HAL modules are initialized here along with Application level code housed in AppFasal.h
3. AppFasal_Init Initializes the application, sends startup message and sets up the TriColorLED, console and startup timer
4. The function AppFasal_Run is the application state-machine that drives the application
(a) Module level initialization is carried out in the first step
(b) The application then waits for the user to press the flash user button
(c) External flash is then initialized before progressing to the file transfer phase
(d) Depending on the hardware slide switch setting, the device can then proceed in one of the following modes
i. SD-Card Transfer Mode:
A. SD-Card is initialized and it is ensured that the Golden image is present
B. Golden image is transferred from the SD card to the external flash
C. CRC of the same file in SD-Card and in the now transferred flash are computed and checked against each other
ii. XModem Transfer Mode:
A. File Must be transferred over XModem 1K option though a serial terminal [Baud: 115200, Data: 8b, Stop Bit: 1b]
(e) In either mode, On successful reception of Golden Image, the Firmware then enters the termination stage, indicates success and waits on the flash user button stage
(f) In either mode failure of any of the steps prior to successful transfer results in the application state-machine indicating the failure reason and jumping back flash user button stage

1.5 Build-Instruction | 5

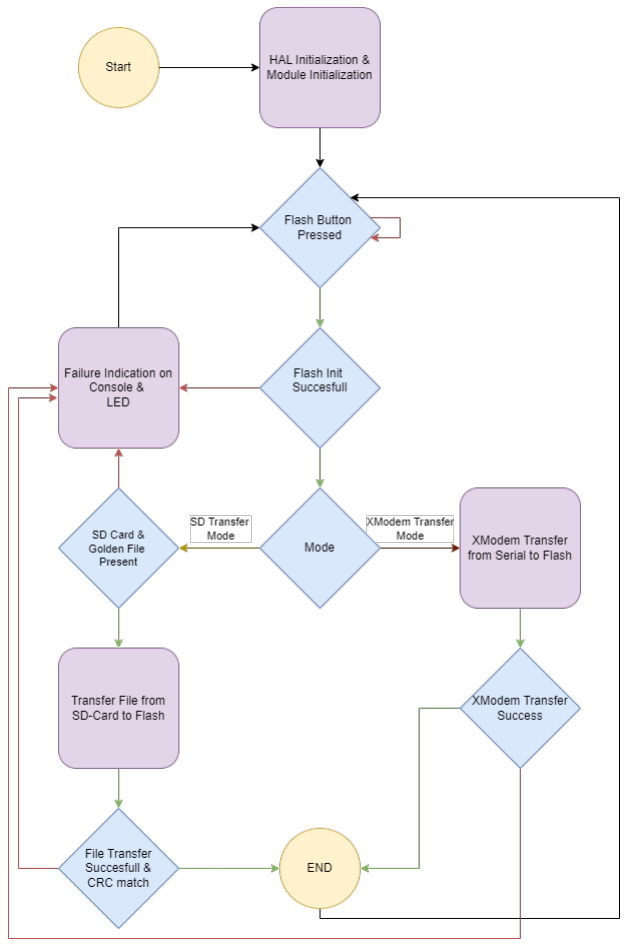
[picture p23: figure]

Figure 1.3 APP

## 1.5 Build-Instruction

1. Built using CubeIDE Version: 1.15.1 Build: 21094_20240412_1041 (UTC)
2. Both BUILD_DEBUG and BUILD_PROD Uses Linker script STM32f103RETX_FLASH.ld with flash offset of 0x0800 0000, application size set to 512KB
3. The following build configurations are built into the codebase
(a) BUILD_DEBUG : Debug build used during development with all debug symbols enabled
- Optimization level : None
- Symbols defined : DEBUG | STM32F103xE | USE_HAL_DRIVER
(b) BUILD_PROD : Production build for filed use
- Optimization level : Ofast
- Symbols defined : NDEBUG | STM32F103xE | USE_HAL_DRIVER
4. SourceCode/FasalFlasher/User_Files/AppCommon/AppConfiguration for changing compile time build features

## 1.6 Docs

1. Open Index.html in any browser. Files located here Docs/html
2. Latex Generated PDF file is preset at Docs/Design_Document/FasalNode_FirmwareDesignDocument.pdf
3. The documentation can be generated by running batch script make_designdocument.bat at the project root

### 6 Fasal Flasher

## 1.7 Contact-Me

- vishalbhatta@gmail.com over E-Mail
- LinkedIn (https://in.linkedin.com/in/vishal-keshava-murthy-8a2ba1a7)

# Chapter 2

# Data Structure Index

## 2.1 Data Structures

Here are the data structures with brief descriptions:

lfs_cache

sConsoleCommand_t

sElevatedPromptData_t

sFlashFS_t

sLed_t

sLEDPins_t

### 8 Data Structure Index

sSDFS_t
Wrapper around FatFS file System | 27
sSoftTimer_t
Soft-timer structure | 27
sSTMGpioPinWrapper_t
Wrapper around STM GPIO pin structure | | | 27
sTriColorIndication_t
Wrapper utility structure that combines eTriColorLEDStates_t and eTriColorLEDBlinkPeriod_t . 28 sTricolorLED_t
TriColor LED structure | | | 28
sTriColorLEDState_t
Helper structure encompassing LED states | | | 29
w25qxx_t | | 30

# Chapter 3

# File Index

## 3.1 File List

Here is a list of all documented files with brief descriptions:

AppCommon.c
Definition of Common functions used in the application. Fault handlers are also defined here | . | 31
AppCommon.h
Interface of Common functions used in the application | 38
AppCommon/AppConfiguration/AppConfiguration.c
Configuration structures used throughout the program defined here | 45
AppConfiguration/AppConfiguration.c
Configuration structures used throughout the program defined here | 45
AppCommon/AppConfiguration/AppConfiguration.h
All Code configuration though conditional compilation is managed here | 46
AppConfiguration/AppConfiguration.h
All Code configuration though conditional compilation is managed here | 46
AppCommon/AppConfiguration/Version.h
All version information about the device is maintained here | 47
AppConfiguration/Version.h
All version information about the device is maintained here | 48
AppIndication.c
This module abstracts Indication medium on board and map to application state | 49
AppIndication/AppIndication.c
This module abstracts Indication medium on board and map to application state | 52
AppIndication.h
Interface for Indicating various application states over LEDs | 55
AppIndication/AppIndication.h
Interface for Indicating various application states over LEDs | 58
AppIndication/TriColorLED/TriColorLED.c
Tri-Color LED Implementation | | | 61
TriColorLED/TriColorLED.c
Tri-Color LED Implementation | | | 70
AppIndication/TriColorLED/TriColorLED.h
TriColor LED Interface | | | 79
TriColorLED/TriColorLED.h
TriColor LED Interface | | | 83
AppProfiler.c
Utility implementation to measure function execution time based on DWT module | | | 90
AppProfiler.h
Utility Interface to measure function execution time | | | 90

### 10 File Index

AppCommon/AppUtility/DebugPrint.h
Debug print definition is redirected to Console_Print function if enabled | 92
AppInterface/Console/DebugPrint.h
Debug print definition is redirected to Console_Print function if enabled | 92
SoftTimer.c
Soft-timer implementation | | | 93
SoftTimer.h
Soft-timer Interface | 102
Utility.h | 109
CommonDefinitions.h
Utility definitions and DS used in the code | 110
CommonInterrupts.c
All Interrupt routines shared across modules are implemented here | 111
CommonInterrupts.h | 113
ConfigSetting.c
Config Setting implementation | 113
ConfigSetting.h
Config Setting interface | 114
AppCommon/Console/Console.c
Console module implementation | 116
AppInterface/Console/Console.c
Console module implementation | 121
AppCommon/Console/Console.h
Console module interface | 127
AppInterface/Console/Console.h
Console module interface | 133
PushButton.c
Push Button Implementation | 142
PushButton.h
Push Button Interface | 143
AppFasal.c
Fasal Application Implementation | 144
AppFasal.h
Fasal Application Interface | 148
AppResetAndError.c
Reset and error handling Implementation | 150
AppResetAndError.h
Reset and error handling Interface | 152
AppInterface/xModem/xmodem.c
Modified Xmodem module which transfers file received over serial to Storage medium | 155
xModem/xmodem.c
Modified Xmodem module which transfers file received over serial to Storage medium | 159
AppInterface/xModem/xmodem.h
Xmodem Interface | 164
xModem/xmodem.h
Xmodem Interface | 167
AppInterrupts.c
Application Interrupt callbacks defines | 171
AppInterrupts.h
Application Interrupt callbacks interface | 176
AppFlash_API.c
API implementation of LittleFS Filesystem on external Flash | 178
AppFlash_API.h
API interface LittleFS Filesystem on external Flash | 191
lfs.h | 197
lfs_util.h | 205
LittleFS_Wrapper.c
Wrapper around LittleFS filesystem | 208

3.1 File List | 11

LittleFS_Wrapper.h
Interface for LittleFS_Wrapper | 211
W25Qxx.c
W25Qxx Driver Implementation | 213
W25Qxx.h
W25Qxx Driver Interface | 214
AppSD_API.c
API implementation of FATFS Filesystem on SD-Card | 218
AppSD_API.h
API Interface of FATFS Filesystem on SD-Card | 231
AppStorage.c
Storage module implementation that consumes AppFlashFS and AppSDFS | 238
AppStorage.h
App storage interface | 241
AppStorageDataStructures.h
Common data structures used by Storage modules are defined here | 245

### 12 File Index

# Chapter 4

# Data Structure Documentation

## 4.1 df_dataparam Struct Reference

Data Fields

- uint8_t txbuff [DF_PAGE_SIZE]
- uint8_t rxbuff [DF_PAGE_SIZE]
- uint8_t txbuff_len
- uint8_t rxbuff_len
- uint8_t rxbuff_readpos
- uint8_t df_mode

The documentation for this struct was generated from the following file:

- W25Qxx.h

## 4.2 lfs Struct Reference

Collaboration diagram for lfs:

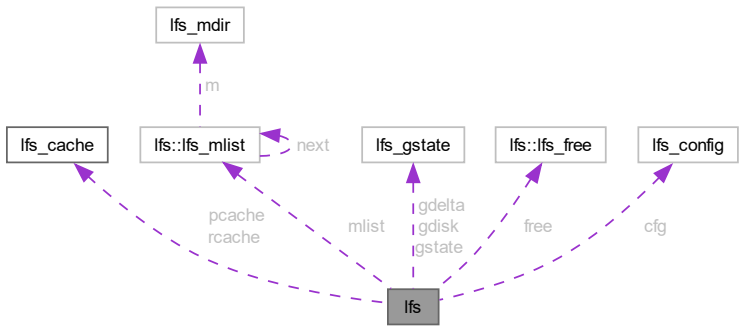
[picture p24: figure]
lfs; lfs_cache; pcache rcache; lfs::lfs_mlist; mlist; next; lfs_mdir; lfs_gstate; gdelta gdisk gstate; lfs::lfs_free; free; lfs_config; cfg

### 14 Data Structure Documentation

Data Structures

- struct lfs_free
- struct lfs_mlist

Data Fields

- lfs_cache_t rcache
- lfs_cache_t pcache
- lfs_block_t root [2]
- struct lfs::lfs_mlist ∗ mlist
- uint32_t seed
- lfs_gstate_t gstate
- lfs_gstate_t gdisk
- lfs_gstate_t gdelta
- struct lfs::lfs_free free
- const struct lfs_config ∗ cfg
- lfs_size_t name_max
- lfs_size_t file_max
- lfs_size_t attr_max

The documentation for this struct was generated from the following file:

- lfs.h

## 4.3 lfs_attr Struct Reference

Data Fields

- uint8_t type
- void ∗ buffer
- lfs_size_t size

The documentation for this struct was generated from the following file:

- lfs.h

## 4.4 lfs_cache Struct Reference

#include <lfs.h>

Data Fields

- lfs_block_t block
- lfs_off_t off
- lfs_size_t size
- uint8_t ∗ buffer

The documentation for this struct was generated from the following file:

- lfs.h

4.5 lfs_commit Struct Reference | 15

## 4.5 lfs_commit Struct Reference

Data Fields

- lfs_block_t block
- lfs_off_t off
- lfs_tag_t ptag
- uint32_t crc
- lfs_off_t begin
- lfs_off_t end

The documentation for this struct was generated from the following file:

- lfs.c

## 4.6 lfs_config Struct Reference

Data Fields

- void ∗ context
- int(∗ read )(const struct lfs_config ∗c, lfs_block_t block, lfs_off_t off, void ∗buffer, lfs_size_t size)
- int(∗ prog )(const struct lfs_config ∗c, lfs_block_t block, lfs_off_t off, const void ∗buffer, lfs_size_t size)
- int(∗ erase )(const struct lfs_config ∗c, lfs_block_t block)
- int(∗ sync )(const struct lfs_config ∗c)
- lfs_size_t read_size
- lfs_size_t prog_size
- lfs_size_t block_size
- lfs_size_t block_count
- int32_t block_cycles
- lfs_size_t cache_size
- lfs_size_t lookahead_size
- void ∗ read_buffer
- void ∗ prog_buffer
- void ∗ lookahead_buffer
- lfs_size_t name_max
- lfs_size_t file_max
- lfs_size_t attr_max
- lfs_size_t metadata_max

The documentation for this struct was generated from the following file:

- lfs.h

## 4.7 lfs_file::lfs_ctz Struct Reference

Data Fields

- lfs_block_t head
- lfs_size_t size

The documentation for this struct was generated from the following file:

- lfs.h

### 16 Data Structure Documentation

## 4.8 lfs_dir Struct Reference

Collaboration diagram for lfs_dir:

### lfs_dir next

### lfs_mdir

m

Data Fields

- struct lfs_dir ∗ next
- uint16_t id
- uint8_t type
- lfs_mdir_t m
- lfs_off_t pos
- lfs_block_t head [2]

The documentation for this struct was generated from the following file:

- lfs.h

## 4.9 lfs_dir_commit_commit Struct Reference

Collaboration diagram for lfs_dir_commit_commit:

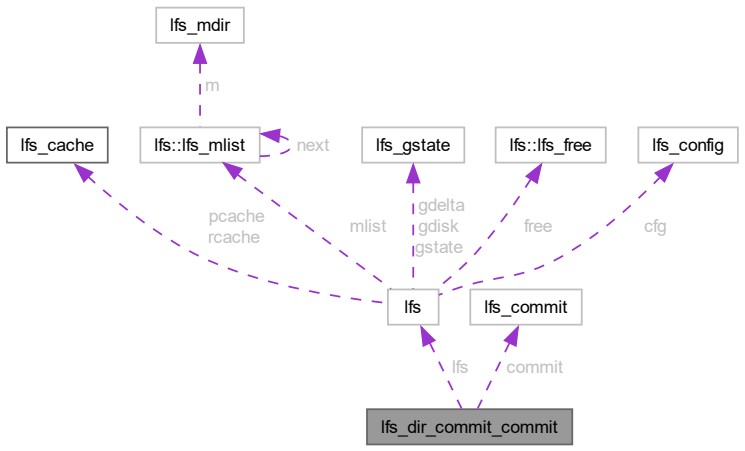
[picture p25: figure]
lfs_dir_commit_commit; lfs; lfs_cache; pcache rcache; lfs::lfs_mlist; mlist; next; lfs_mdir; lfs_gstate; gdelta gdisk gstate; lfs::lfs_free; free; lfs_config; cfg; lfs_commit; commit

4.10 lfs_dir_find_match Struct Reference | 17

Data Fields

- lfs_t ∗ lfs
- struct lfs_commit ∗ commit

The documentation for this struct was generated from the following file:

- lfs.c

## 4.10 lfs_dir_find_match Struct Reference

Collaboration diagram for lfs_dir_find_match:

Data Fields

- lfs_t ∗ lfs

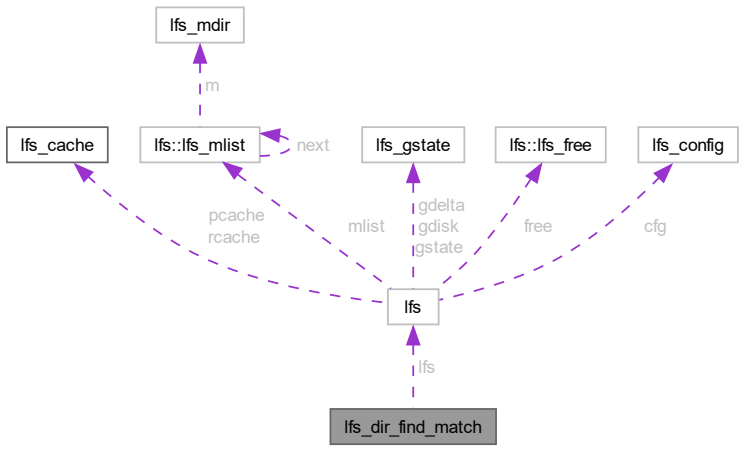
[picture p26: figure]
lfs_dir_find_match; lfs; lfs_cache; pcache rcache; lfs::lfs_mlist; mlist; next; lfs_mdir; lfs_gstate; gdelta gdisk gstate; lfs::lfs_free; free; lfs_config; cfg

- const void ∗ name
- lfs_size_t size

The documentation for this struct was generated from the following file:

- lfs.c

### 18 Data Structure Documentation

## 4.11 lfs_dir_traverse Struct Reference

Collaboration diagram for lfs_dir_traverse:

### lfs_dir_traverse

### lfs_mdir

### dir

### lfs_mattr

### attrs

### lfs_diskoff

### disk

Data Fields

- const lfs_mdir_t ∗ dir
- lfs_off_t off
- lfs_tag_t ptag
- const struct lfs_mattr ∗ attrs
- int attrcount
- lfs_tag_t tmask
- lfs_tag_t ttag
- uint16_t begin
- uint16_t end
- int16_t diff
- int(∗ cb )(void ∗data, lfs_tag_t tag, const void ∗buffer)
- void ∗ data
- lfs_tag_t tag
- const void ∗ buffer
- struct lfs_diskoff disk

The documentation for this struct was generated from the following file:

- lfs.c

## 4.12 lfs_diskoff Struct Reference

Data Fields

- lfs_block_t block
- lfs_off_t off

The documentation for this struct was generated from the following file:

- lfs.c

4.13 lfs_fcrc Struct Reference | 19

## 4.13 lfs_fcrc Struct Reference

Data Fields

- lfs_size_t size
- uint32_t crc

The documentation for this struct was generated from the following file:

- lfs.c

## 4.14 lfs_file Struct Reference

Collaboration diagram for lfs_file:

Data Structures

- struct lfs_ctz

Data Fields

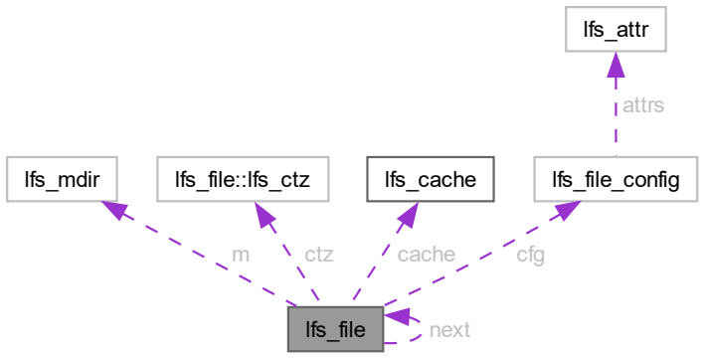
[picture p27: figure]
lfs_file; next; lfs_mdir; lfs_file::lfs_ctz; ctz; lfs_cache; cache; lfs_file_config; cfg; lfs_attr; attrs

- struct lfs_file ∗ next
- uint16_t id
- uint8_t type
- lfs_mdir_t m
- struct lfs_file::lfs_ctz ctz
- uint32_t flags
- lfs_off_t pos
- lfs_block_t block
- lfs_off_t off
- lfs_cache_t cache
- const struct lfs_file_config ∗ cfg

The documentation for this struct was generated from the following file:

- lfs.h

### 20 Data Structure Documentation

## 4.15 lfs_file_config Struct Reference

Collaboration diagram for lfs_file_config:

### lfs_file_config

### lfs_attr

### attrs

Data Fields

- void ∗ buffer
- struct lfs_attr ∗ attrs
- lfs_size_t attr_count

The documentation for this struct was generated from the following file:

- lfs.h

## 4.16 lfs::lfs_free Struct Reference

Data Fields

- lfs_block_t off
- lfs_block_t size
- lfs_block_t i
- lfs_block_t ack
- uint32_t ∗ buffer

The documentation for this struct was generated from the following file:

- lfs.h

4.17 lfs_fs_parent_match Struct Reference | 21

## 4.17 lfs_fs_parent_match Struct Reference

Collaboration diagram for lfs_fs_parent_match:

Data Fields

- lfs_t ∗ lfs

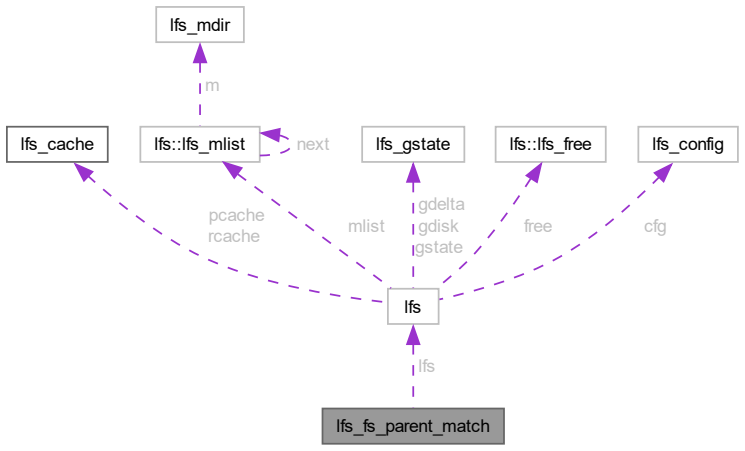
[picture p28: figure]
lfs_fs_parent_match; lfs; lfs_cache; pcache rcache; lfs::lfs_mlist; mlist; next; lfs_mdir; lfs_gstate; gdelta gdisk gstate; lfs::lfs_free; free; lfs_config; cfg

- const lfs_block_t pair [2]

The documentation for this struct was generated from the following file:

- lfs.c

## 4.18 lfs_fsinfo Struct Reference

Data Fields

- uint32_t disk_version
- lfs_size_t name_max
- lfs_size_t file_max
- lfs_size_t attr_max

The documentation for this struct was generated from the following file:

- lfs.h

### 22 Data Structure Documentation

## 4.19 lfs_gstate Struct Reference

Data Fields

- uint32_t tag
- lfs_block_t pair [2]

The documentation for this struct was generated from the following file:

- lfs.h

## 4.20 lfs_info Struct Reference

Data Fields

- uint8_t type
- lfs_size_t size
- char name [LFS_NAME_MAX+1]

The documentation for this struct was generated from the following file:

- lfs.h

## 4.21 lfs_mattr Struct Reference

Data Fields

- lfs_tag_t tag
- const void ∗ buffer

The documentation for this struct was generated from the following file:

- lfs.c

## 4.22 lfs_mdir Struct Reference

Data Fields

- lfs_block_t pair [2]
- uint32_t rev
- lfs_off_t off
- uint32_t etag
- uint16_t count
- bool erased
- bool split
- lfs_block_t tail [2]

The documentation for this struct was generated from the following file:

- lfs.h

4.23 lfs::lfs_mlist Struct Reference | 23

## 4.23 lfs::lfs_mlist Struct Reference

Collaboration diagram for lfs::lfs_mlist:

### lfs::lfs_mlist next

### lfs_mdir

m

Data Fields

- struct lfs_mlist ∗ next
- uint16_t id
- uint8_t type
- lfs_mdir_t m

The documentation for this struct was generated from the following file:

- lfs.h

## 4.24 lfs_superblock Struct Reference

Data Fields

- uint32_t version
- lfs_size_t block_size
- lfs_size_t block_count
- lfs_size_t name_max
- lfs_size_t file_max
- lfs_size_t attr_max

The documentation for this struct was generated from the following file:

- lfs.h

## 4.25 sConsoleCommand_t Struct Reference

#include <Console.h>

### 24 Data Structure Documentation

Data Fields

- const char ∗ CommandName
- char CommandStr [BUFFER_SIZE_8]
- volatile bool IsCommandRaised
- volatile bool IsCommandServiced
- pfConsoleCommandActor_t pfConsoleCommandActor

### 4.25.1 Detailed Description

The documentation for this struct was generated from the following files:

- AppCommon/Console/Console.h
- AppInterface/Console/Console.h

## 4.26 sElevatedPromptData_t Struct Reference

#include <Console.h>

Data Fields

- char buf [CONSOLE_PROMPT_BUFFER_SIZE]

### 4.26.1 Detailed Description

The documentation for this struct was generated from the following files:

- AppCommon/Console/Console.h
- AppInterface/Console/Console.h

## 4.27 sFlashFS_t Struct Reference

#include <AppFlash_API.h>

4.28 sLed_t Struct Reference | 25

Collaboration diagram for sFlashFS_t:

Data Fields

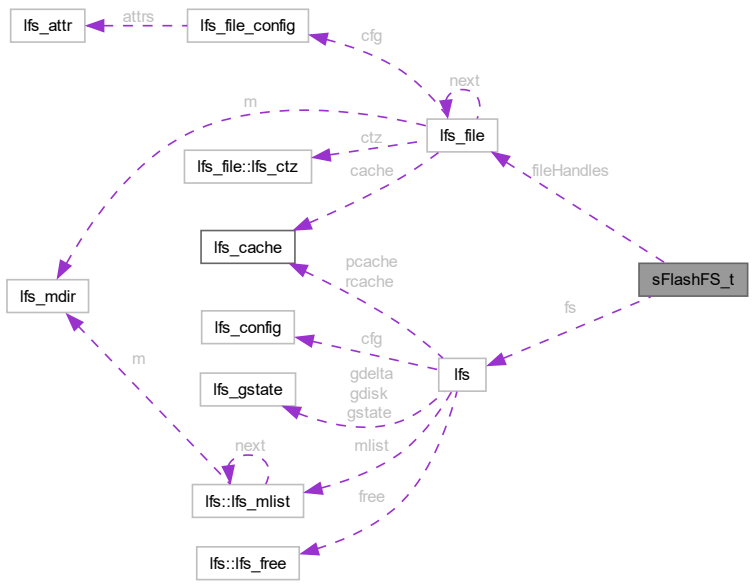
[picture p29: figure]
sFlashFS_t; lfs; lfs_cache; pcache; rcache; lfs_file; cache; lfs::lfs_mlist; next; mlist; lfs_mdir; lfs_gstate; gdelta gdisk gstate; lfs::lfs_free; free; lfs_config; cfg; fileHandles; lfs_file::lfs_ctz; ctz; lfs_file_config; cfg lfs_attr; attrs

- bool IsMounted
- lfs_t fs
- lfs_file_t fileHandles [eFS_MAX]

### 4.27.1 Detailed Description

The documentation for this struct was generated from the following file:

- AppFlash_API.h

## 4.28 sLed_t Struct Reference

#include <TriColorLED.h>

### 26 Data Structure Documentation

Collaboration diagram for sLed_t:

### sLed_t

### sSTMGpioPinWrapper_t

### pcLedPin

### sLEDPins_t

### pcLedPin

Data Fields

- const sSTMGpioPinWrapper_t ∗ pcLedPin
- eLEDState_t ledState
- const sLEDPins_t ∗ pcLedPin

### 4.28.1 Detailed Description

The documentation for this struct was generated from the following files:

- AppIndication/TriColorLED/TriColorLED.h
- TriColorLED/TriColorLED.h

## 4.29 sLEDPins_t Struct Reference

#include <TriColorLED.h>

Data Fields

- GPIO_TypeDef ∗ LEDPort
- uint16_t LEDPin

### 4.29.1 Detailed Description

The documentation for this struct was generated from the following file:

- TriColorLED/TriColorLED.h

4.30 sSDFS_t Struct Reference | 27

## 4.30 sSDFS_t Struct Reference

#include <AppSD_API.h>

Data Fields

- bool IsMounted
- FATFS fs
- FIL fileHandles [eFS_MAX]

### 4.30.1 Detailed Description

The documentation for this struct was generated from the following file:

- AppSD_API.h

## 4.31 sSoftTimer_t Struct Reference

#include <SoftTimer.h>

Data Fields

- bool IsArmed
- bool IsPeriodic
- uint32_t currentTicks
- uint32_t setTicks
- pfCallBack_t pfCallBack

### 4.31.1 Detailed Description

The documentation for this struct was generated from the following file:

- SoftTimer.h

## 4.32 sSTMGpioPinWrapper_t Struct Reference

#include <CommonDefinitions.h>

Data Fields

- GPIO_TypeDef ∗ GpioPort
- uint16_t GpioPin

### 28 Data Structure Documentation

### 4.32.1 Detailed Description

The documentation for this struct was generated from the following file:

- CommonDefinitions.h

## 4.33 sTriColorIndication_t Struct Reference

#include <TriColorLED.h>

Data Fields

- bool IsBlinkNeeded
- eTriColorLEDStates_t ledState
- eTriColorLEDBlinkPeriod_t ledBlinkPeriod

### 4.33.1 Detailed Description

The documentation for this struct was generated from the following files:

- AppIndication/TriColorLED/TriColorLED.h
- TriColorLED/TriColorLED.h

## 4.34 sTricolorLED_t Struct Reference

#include <TriColorLED.h>

Collaboration diagram for sTricolorLED_t:

### sTricolorLED_t

### sLed_t

### Leds Leds2

### sSTMGpioPinWrapper_t

### pcLedPin

### sLEDPins_t

### pcLedPin

4.35 sTriColorLEDState_t Struct Reference | 29

Data Fields

- bool IsInitialized
- bool IsBlinkEnabled
- size_t blinkTicksSet
- size_t blinkTicksCurrent
- eTriColorLEDStates_t triColorLEDState
- eTriColorLEDStates_t prevOnLEDState
- sLed_t Leds [eLED_MAX]
- sLed_t Leds2 [eLED_MAX]

### 4.34.1 Detailed Description

### 4.34.2 Field Documentation

### 4.34.2.1 Leds2

sLed_t sTricolorLED_t::Leds2

Duplicate set of LED pins that shows the same indication.

Duplicate set of LED pins that shows the same indication

The documentation for this struct was generated from the following files:

- AppIndication/TriColorLED/TriColorLED.h
- TriColorLED/TriColorLED.h

## 4.35 sTriColorLEDState_t Struct Reference

#include <TriColorLED.h>

Data Fields

- eLEDState_t LedState [eLED_MAX]

### 4.35.1 Detailed Description

The documentation for this struct was generated from the following files:

- AppIndication/TriColorLED/TriColorLED.h
- TriColorLED/TriColorLED.h

### 30 Data Structure Documentation

## 4.36 w25qxx_t Struct Reference

Data Fields

- W25QXX_ID_t ID
- uint8_t UniqID [8]
- uint16_t PageSize
- uint32_t PageCount
- uint32_t SectorSize
- uint32_t SectorCount
- uint32_t BlockSize
- uint32_t BlockCount
- uint32_t CapacityInKiloByte
- uint8_t StatusRegister1
- uint8_t StatusRegister2
- uint8_t StatusRegister3
- uint8_t Lock

The documentation for this struct was generated from the following file:

- W25Qxx.h

# Chapter 5

# File Documentation

## 5.1 AppCommon.c File Reference

#include <stdint.h>

#include ¨stm32f1xx_hal.h¨ #include ¨AppCommon.h¨

#include ¨Version.h¨

#include ¨AppIndication.h¨ #include ¨Console.h¨

#include ¨AppConfiguration.h¨

Functions

- __attribute__ ((unused))
- static void AppCommon_PreResetRoutine ()
- eDeviceErrorCode_t AppCommon_GetErrorCode ()
- void AppCommon_AccumlateErrorCode (eDeviceErrorCode_t err)
- void AppCommon_ResetErrorCode ()
- void AppCommon_DetermineResetCause ()
- eDeviceResetCause_t AppCommon_GetCachedResetCause ()
- void AppCommon_HALErrorHandler ()
- void AppCommon_STMFaultHandler ()
- void __assert_func (const char ∗file, int line, const char ∗func, const char ∗failedexpr)
- void AppCommon_PrintDelimiter ()
- void AppCommon_PrintLineBreak ()
- void AppCommon_StartUpMessagePrint ()
- const char ∗const AppCommon_GetStatusString (int status)

Variables

- static eDeviceResetCause_t gDeviceResetCause = eRESET_CAUSE_UNKNOWN
- static eDeviceErrorCode_t gErrorCode = eERR_NO_ERRORS
- static const char ∗ gcStatusStringHelper [eSTATUS_STRING_MAX]

### 32 File Documentation

### 5.1.1 Detailed Description

Author

Vishal Keshava Murthy

Version

0.1

Date

2023-06-03

Copyright

Copyright (c) 2023

### 5.1.2 Function Documentation

### 5.1.2.1 __attribute__()

__attribute__ (

(unused) )

convert eDeviceResetCause_t enum to strings for printing

Delete File.

Write to a file in FatFS.

Parameters

pMe | FatFS wrapper instance
fileEnum | File to be written into
IsAppend | Pass true to write to file in append mode, false to write at the beginning
pInWriteBuf | data to be written is passed here
bufSize | size of buffer passed for writing

Returns

eStorageFSStatus_t

Parameters

pMe | FatFS wrapper instance
fileEnum | File to be deleted

5.1 AppCommon.c File Reference | 33

Returns

eStorageFSStatus_t

### 5.1.2.2 AppCommon_PreResetRoutine()

static void AppCommon_PreResetRoutine ( ) [static]

Function to be invoked prior to resetting the system to recover from an hard fault/error.

< Device has been reset so set up-time back to ZeroHere is the caller graph for this function:

AppCommon_PreResetRoutine

__assert_func

AppCommon_HALErrorHandler

AppCommon_STMFaultHandler

### 5.1.2.3 AppCommon_GetErrorCode()

eDeviceErrorCode_t AppCommon_GetErrorCode ( )

Setter for gErrorCode, previous values are unaffected.

Returns

eDeviceErrorCode_t

Here is the caller graph for this function:

AppFasal_Run | AppCommon_GetErrorCode Generated by Doxygen

### 34 File Documentation

### 5.1.2.4 AppCommon_AccumlateErrorCode()

void AppCommon_AccumlateErrorCode (

eDeviceErrorCode_t err )

Setter for gErrorCode, previous values are unaffected.

Here is the caller graph for this function:

AppFasal_Run | AppCommon_AccumlateErrorCode

### 5.1.2.5 AppCommon_ResetErrorCode()

void AppCommon_ResetErrorCode ( )

Reset error Code.

Here is the caller graph for this function:

AppFasal_Run | AppCommon_ResetErrorCode

### 5.1.2.6 AppCommon_DetermineResetCause()

void AppCommon_DetermineResetCause ( )

Function to determine why the device was reset, also sets global gDeviceResetCause.

Note

should be called before peripheral initialization

5.1 AppCommon.c File Reference | 35

### 5.1.2.7 AppCommon_GetCachedResetCause()

eDeviceResetCause_t AppCommon_GetCachedResetCause ( )

Getter for gDeviceResetCause.

Note

Assumes AppCommon_DetermineResetCause is called at startup

Returns

eDeviceResetCause_t

### 5.1.2.8 AppCommon_HALErrorHandler()

void AppCommon_HALErrorHandler ( )

STM HAL error handler.

Warning

This function resets the device

Here is the call graph for this function:

AppCommon_HALErrorHandler

AppCommon_PreResetRoutine

AppIndicate_SetState

Console_Print

TriColorLed_API_Indicate

TriColorLed_GetInstance

TriColorLed_SetState

TriColorLed_StartBlink | SoftTimer_Start

### 5.1.2.9 AppCommon_STMFaultHandler()

void AppCommon_STMFaultHandler ( )

STM Fault error handler.

Warning

This function resets the device

Here is the call graph for this function:

AppCommon_STMFaultHandler

AppCommon_PreResetRoutine

AppIndicate_SetState

Console_Print

TriColorLed_API_Indicate

TriColorLed_GetInstance

TriColorLed_SetState

TriColorLed_StartBlink | SoftTimer_Start Generated by Doxygen

### 36 File Documentation

### 5.1.2.10 __assert_func()

void __assert_func (

const char ∗ file,

int line,

const char ∗ func,

const char ∗ failedexpr )

Assert failure error handler.

Warning

This function resets the device

Here is the call graph for this function:

__assert_func

AppCommon_PreResetRoutine

AppIndicate_SetState

Console_Print

TriColorLed_API_Indicate

TriColorLed_GetInstance

TriColorLed_SetState

TriColorLed_StartBlink | SoftTimer_Start

### 5.1.2.11 AppCommon_PrintDelimiter()

void AppCommon_PrintDelimiter ( )

Utility function to print delimiter used in the console.

Here is the call graph for this function:

AppCommon_PrintDelimiter | Console_Print

Here is the caller graph for this function:

AppCommon_PrintDelimiter AppCommon_StartUpMessage
Print | Generated by Doxygen

5.1 AppCommon.c File Reference | 37

### 5.1.2.12 AppCommon_PrintLineBreak()

void AppCommon_PrintLineBreak ( )

Utility function to print delimiter used in the console.

Here is the call graph for this function:

AppCommon_PrintLineBreak | Console_Print

### 5.1.2.13 AppCommon_StartUpMessagePrint()

void AppCommon_StartUpMessagePrint ( )

Start up message print.

Here is the call graph for this function:

AppCommon_StartUpMessage
Print

AppCommon_PrintDelimiter
Console_Print

### 5.1.2.14 AppCommon_GetStatusString()

const char ∗const AppCommon_GetStatusString (

int status )

Utility function returns ¨Success¨ or ¨failure¨ based on status code passed.

See also

gcStatusStringHelper

Parameters

status 0 is success across all modules in the code-base , non 0 is treated as failure

### 38 File Documentation

Returns

const char∗ const

Here is the caller graph for this function:

AppFasal_Run | AppCommon_GetStatusString

### 5.1.3 Variable Documentation

### 5.1.3.1 gDeviceResetCause

eDeviceResetCause_t gDeviceResetCause = eRESET_CAUSE_UNKNOWN [static]

Global that maintains reset cause

### 5.1.3.2 gErrorCode

eDeviceErrorCode_t gErrorCode = eERR_NO_ERRORS [static]

Global that maintains error cause

### 5.1.3.3 gcStatusStringHelper

const char∗ gcStatusStringHelper[eSTATUS_STRING_MAX] [static]

Initial value:

=
{
[eSUCCESS_STRING] = "Success", [eFAILURE_STRING] = "Failure" }

Map eStatusPrintHelperEnum_t to string. Used by AppCommon_GetStatusString.

## 5.2 AppCommon.h File Reference

Macros

- #define LOOP_FOREVER {while(1);}

5.2 AppCommon.h File Reference | 39

Enumerations

- enum eStatusPrintHelperEnum_t { eSUCCESS_STRING , eFAILURE_STRING , eSTATUS_STRING_MAX }
- enum eDeviceResetCause_t {
eRESET_CAUSE_UNKNOWN = 0 , eRESET_CAUSE_WAKEUP , eRESET_CAUSE_LOW_POWER_←-RESET , eRESET_CAUSE_WINDOW_WATCHDOG_RESET , eRESET_CAUSE_INDEPENDENT_WATCHDOG_RESET , eRESET_CAUSE_SOFTWARE_RESET , e←-RESET_CAUSE_POWER_ON_POWER_DOWN_RESET , eRESET_CAUSE_EXTERNAL_RESET_PIN_←-RESET ,
eRESET_CAUSE_BROWNOUT_RESET , eRESET_CAUSE_MAX }
- enum eDeviceErrorCode_t {
eERR_NO_ERRORS = 0x0000 , eERR_SDCARD_NOT_FOUND = 0x0001 , eERR_SDCARD_FILE_NOT←-_FOUND = 0x0002 , eERR_FLASH_NOT_FOUND = 0x0004 ,
eERR_FLASH_TRANSFER_FAILURE = 0x0008 , eERR_CRC_FAILURE = 0x0010 , eERR_UNUSED_1 = 0x0020 , eERR_UNUSED_2 = 0x0040 ,
eERR_UNUSED_3 = 0x0080 , eERR_UNUSED_4 = 0x0100 , eERR_UNUSED_5 = 0X0200 , eERR_←-UNUSED_6 = 0x0400 ,
eERR_UNUSED_7 = 0x0800 , eERR_STM_HAL_FAILURE = 0x1000 , eERR_ARM_FAULT = 0x2000 , e←-ERR_ASSERTION_FAILURE = 0x4000 ,
eERR_SLEEP_FAILURE = 0x8000 }

Functions

- void AppCommon_PrintDelimiter ()
- void AppCommon_PrintLineBreak ()
- void AppCommon_StartUpMessagePrint ()
- void AppCommon_HALErrorHandler ()
- void AppCommon_STMFaultHandler ()
- const char ∗const AppCommon_GetStatusString (int status)
- void __assert_func (const char ∗file, int line, const char ∗func, const char ∗failedexpr)
- void AppCommon_DetermineResetCause ()
- eDeviceResetCause_t AppCommon_GetCachedResetCause ()
- eDeviceErrorCode_t AppCommon_GetErrorCode ()
- void AppCommon_AccumlateErrorCode (eDeviceErrorCode_t err)
- void AppCommon_ResetErrorCode ()

### 5.2.1 Detailed Description

Author

Vishal Keshava Murthy

Version

0.1

Date

2023-06-03

Copyright

Copyright (c) 2023

### 40 File Documentation

### 5.2.2 Macro Definition Documentation

### 5.2.2.1 LOOP_FOREVER

#define LOOP_FOREVER {while(1);}

Utility MACRO to loop forever

### 5.2.3 Enumeration Type Documentation

### 5.2.3.1 eStatusPrintHelperEnum_t

enum eStatusPrintHelperEnum_t
Enum for status helper.

### 5.2.3.2 eDeviceResetCause_t

enum eDeviceResetCause_t
Possible STM32 system reset causes.

### 5.2.3.3 eDeviceErrorCode_t

enum eDeviceErrorCode_t
Possible Errors in application.

### 5.2.4 Function Documentation

### 5.2.4.1 AppCommon_PrintDelimiter()

void AppCommon_PrintDelimiter ( )
Utility function to print delimiter used in the console.

Here is the call graph for this function:

AppCommon_PrintDelimiter | Console_Print

Here is the caller graph for this function:

AppCommon_PrintDelimiter AppCommon_StartUpMessage
Print | Generated by Doxygen

5.2 AppCommon.h File Reference | 41

### 5.2.4.2 AppCommon_PrintLineBreak()

void AppCommon_PrintLineBreak ( )

Utility function to print delimiter used in the console.

Here is the call graph for this function:

AppCommon_PrintLineBreak | Console_Print

### 5.2.4.3 AppCommon_StartUpMessagePrint()

void AppCommon_StartUpMessagePrint ( )

Start up message print.

Here is the call graph for this function:

AppCommon_StartUpMessage
Print

AppCommon_PrintDelimiter
Console_Print

### 5.2.4.4 AppCommon_HALErrorHandler()

void AppCommon_HALErrorHandler ( )

STM HAL error handler.

Warning

This function resets the device

Here is the call graph for this function:

AppCommon_HALErrorHandler

AppCommon_PreResetRoutine

AppIndicate_SetState

Console_Print

TriColorLed_API_Indicate

TriColorLed_GetInstance

TriColorLed_SetState

TriColorLed_StartBlink | SoftTimer_Start Generated by Doxygen

### 42 File Documentation
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

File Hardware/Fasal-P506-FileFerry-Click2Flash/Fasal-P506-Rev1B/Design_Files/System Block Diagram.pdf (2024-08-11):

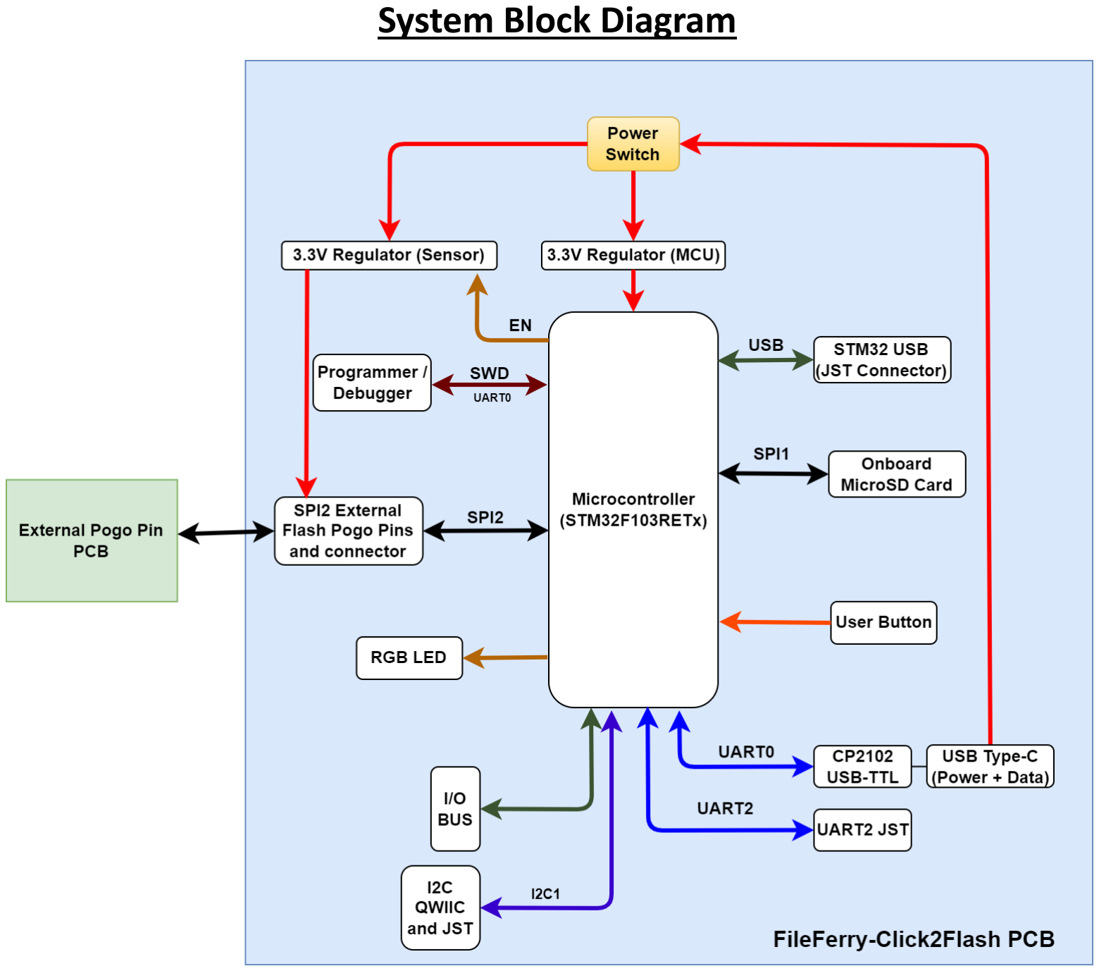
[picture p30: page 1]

System Block Diagram

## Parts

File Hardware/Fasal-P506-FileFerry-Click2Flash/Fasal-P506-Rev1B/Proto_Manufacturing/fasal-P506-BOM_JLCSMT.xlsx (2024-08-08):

Comment | Designator | Footprint | JLCPCB Part #（optional）
1uF | C101, C103, C104, C106 | C0603K | C15849
22nF | C102, C105 | C0603K | C21122
4.7uF | C201, C202 | C0603K | C19666
15pF | C301, C302 | C0603K | C1644
27pF | C303, C304 | C0603K | C107045
100nF | C305, C306, C307, C308, C309, C310, C401 | C0603K | C14663
ESD PESD5V0S1BA | D1, D2 | SOD323 | C19224
ESD PRTR5V0U2X,215 | D101 | PRTR5V0U2X | C2827688
SDM2U20SD3-7 | D102, D501 | SOD-323 | C460258
6V 3A PTC Fuse (Power) | F101 | R1206 | C960021
RT9193-33GB | IC101, IC102 | SOT94P279X130-5N | C15651
USB Type-C data+power | J101 | Surface Mount, Right Angle; Through Hole | C7527694
Sparkfun Qwicc connector Vertical SMD | J2 | 4 pin JST 1mm | C160390
Programming Header SMD 7x2 1.27mm | J6 | 7X2-SMD-1.27MM-SHROUDED | C2881912
Micro SD Card Holder SMD - Flap | J304 | 472192001 | C266609
RED | LED101, LED102 | L0603 | C2286
RGB 5050 | LED401 | 5050 | C3975087
100K | R101 | R0603 | C25803
4.7K | R102, R104 | R0603 | C23162
0E / 0603 | R103, R105, R201, R202, R501, R503, R505, R507, R508, R509 | R0603 | C21189
5.1K | R106, R107 | R0603 | C23186
1K | R203 | R0603 | C21190
10K | R302, R303, R304, R305, R306, R307, R308, R310, R404 | R0603 | C25804
10M | R309 | R0603 | C7250
2.2K | R311, R312 | R0603 | C4190
1M | R313 | R0603 | C105578
100E | R401, R402 | R0603 | C22775
390E | R403 | R0603 | C23151
SWITCH-SPDT-SMD-RIGHT-ANGLE | S101, S302, S303 | SWITCH_SPST_SMD_A | C2890358
TACT SWITCH (Push Button) | S301 | TACTILE_SWITCH_SMD_6.0X3.5MM | C318938
STM32F103RET6 | U1 | 64-LQFP | C8322
CP2102N-A02-GQFN28R | U2 | 28-QFN | C964632
LSE 32.768KHZ 12.5pF, SMD Rectangle 3.20mm x 1.50mm | Y1 | 2-SMD, No Lead | C32346
8MHz Crystal 18pF, Small 4 SMD | Y2 | 5.00mm x 3.20mm | C83312
TACT SWITCH BIG 12x12mm (Push Button) | S401 | TACTILE_SWITCH_THT_12.0x12.0MM | C84931
B4B-XH-A(LF)(SN) PCB connector | X1 | JST Connector B4B-XH-A | C37815
B3B-XH-A(LF)(SN) PCB connector | X2, X4 | JST Connector B3B-XH-A | C2316
B5B-XH-A(LF)(SN) PCB connector | X3 | JST Connector B5B-XH-A | C2318
S6B-XH-A(LF)(SN) R/A PCB connector | X5 | JST Connector S6B-XH-A | C157919

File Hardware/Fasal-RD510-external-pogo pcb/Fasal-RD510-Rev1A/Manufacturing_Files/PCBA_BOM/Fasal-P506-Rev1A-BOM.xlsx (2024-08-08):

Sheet: Sheet1
BOM |  |  |  |  |  |  |  |  | Supplier A (Local) |  | Supplier B (Global Supplier) |  |  |  |  | Alternate MPN - 1 |  |  |  |  | Alternate MPN - 2
Qty | Parts | Value | Wolkus PN | Tolerance | Package | Description | is SMD or THT? | is DNP? | Supplier Name | Manufacturer PN | Manufacturer Name | Manufacturer PN | Digikey PN | Mouser PN | LCSC PN (China) | Manufacturer Name | Manufacturer PN | Digikey PN | Mouser PN | LCSC PN | Manufacturer Name | Manufacturer PN | Digikey PN | Mouser PN | LCSC PN
4 | C101, C103, C104, C106 | 1uF | WO100CAP1000 | ±10% | C0603K | CAP CER 1UF 25V X5R 0603 ±10% | SMD |  |  |  | YAGEO | CC0603KRX5R8BB105 | 311-1445-1-ND |  |  | Taiyo Yuden | TMK107BJ105KA-T | 587-1248-1-ND |  |  | Samsung Electro-Mechanics | CL10A105KA8NFNC | 1276-1859-1-ND
2 | C102, C105 | 22nF | WO100CAP2200 | ±5% | C0603K | CAP CER 0.022UF 50V X7R 0603 ±5% | SMD |  |  |  | Walsin Technology Corporation | 0603B223J500CT | 1292-1414-1-ND |  |  | YAGEO | CC0603JRX7R9BB223 | 311-4010-1-ND |  |  | KYOCERA AVX | 06035C223JAT2A | 478-3722-1-ND
2 | C201, C202 | 4.7uF | WO100CAP4790 | ±10% | C0603K | CAP CER 4.7UF 10V X5R 0603 ±10% | SMD |  |  |  | TDK Corporation | C1608X5R1E475K080AC | 445-9050-1-ND |  |  | Samsung Electro-Mechanics | CL10A475KO8NNNC | 1276-1784-1-ND |  |  | Taiyo Yuden | TMK107BBJ475KA-T | 587-4321-1-ND
2 | C301, C302 | 15pF | WO100CAP1500 | ±1% | C0603K | CAP CER 15PF 50V C0G/NP0 0603 | SMD |  |  |  | Walsin Technology Corporation | 0603N150F500CT | 1292-1485-1-ND |  |  | YAGEO | CC0603FRNPO9BN150 | 311-3887-1-ND |  |  | KYOCERA AVX | 06035A150FAT2A | 478-10289-1-ND
2 | C303, C304 | 27pF | WO100CAP2700 | ±1% | C0603K | CAP CER 27PF 50V C0G/NP0 0603 | SMD |  |  |  | Walsin Technology Corporation | 0603N270F500CT | 1292-1510-1-ND |  |  | YAGEO | CC0603FRNPO9BN270 | 311-3892-1-ND |  |  | KEMET | C0603C270F3HACAUTO | 399-C0603C270F3HACAUTOCT-ND
7 | C305, C306, C307, C308, C309, C310, C401 | 100nF | WO100CAP1010 | ±5% | C0603K | 0.1 µF ±5% 50V Ceramic Capacitor X7R 0603 | SMD |  |  |  | Samsung Electro-Mechanics | CL10B104JB8NNNC | 1276-1033-1-ND |  |  | YAGEO | CC0603JRX7R9BB104 | 311-1779-1-ND |  |  | KYOCERA AVX | 06035C104JAT2A | 478-5778-1-ND
1 | D101 | ESD PRTR5V0U2X,215 | WO100ESD0500 | N/A | PRTR5V0U2X | ESD Protection Diodes 5.5V Dual SOT143B NXP PRTR5V0U2X,215 Dual Uni-Directional TVS Diode, 4-Pin SOT-143B | SMD |  |  |  | Nexperia USA Inc. | PRTR5V0U2X,215 | 1727-3884-1-ND |  |  | Diodes Incorporated | DRTR5V0U2SR-7 | DRTR5V0U2SR-7DICT-ND |  |  | Littelfuse Inc. | SP0503BAHTG | F2715CT-ND
2 | D102, D501 | SDM2U20SD3-7 | WO100DIO2020 | N/A | SOD-323 | DIODE SCHOTTKY 20V 2A | SMD |  |  |  | Diodes Incorporated | SDM2U20SD3-7 | SDM2U20SD3-7DICT-ND |  |  | Micro Commercial Co | B5817WSHE3-TP | 353-B5817WSHE3-TPDKR-ND |  |  | Nexperia USA Inc. | PMEG2010EA,135 | 1727-1228-1-ND
2 | D301, D401 | ESD ESDALC6V1-1U2 | WO100ESD6112 | N/A | D0201 | TVS DIODE 3VWM ST0201 | SMD |  |  |  | ST Microelectronics | ESDALC6V1-1U2 | 497-8752-1-ND
1 | F101 | 6V 3A PTC Fuse (Power) | WO100FUS1230 | N/A | R1206 | PTC RESET FUSE 6V 3A 1206 | SMD |  |  |  | Bourns Inc. | MF-NSML300/6-2 | 118-MF-NSML300/6-2CT-ND | 652-MF-NSML300/6-2 |  | Eaton - Electronics Division | PTSLR12066V300 | 283-PTSLR12066V300CT-ND |  |  | Littelfuse Inc. | 1206L300SLTHYR | F5784CT-ND
2 | IC101, IC102 | RT9193-33GB | WO100REG9193 | N/A | SOT94P279X130-5N | IC REG LINEAR 3.3V 300MA SOT23-5 | SMD |  | Sunrom | 5402 | Richtek USA Inc. | RT9193-33GB | 1028-1014-1-ND |  | C15651
1 | J101 | USB Type-C data+power | WO100USB0003 | N/A | Surface Mount, Right Angle; Through Hole | CONN RCP USB2.0 TYPE-C 24P SMD RA | SMD |  |  |  | GCT | USB4105-GF-A | 2073-USB4105-GF-ACT-ND |  |  | Amphenol ICC (Commercial Products) | 12402012E212A | 664-12402012E212ACT-ND |  |  | Amphenol ICC (FCI) | 10155435-00011LF | 609-10155435-00011LFCT-ND
1 | J2 | Sparkfun Qwicc connector Vertical SMD | WO100CON0410 | N/A | 4 pin JST 1mm | CONN HEADER SMD 4POS 1MM VERTICAL | SMD |  |  |  | Adam Tech | 1SH-A-04-TS-SMT | 2057-1SH-A-04-TS-SMT-ND |  |  | JST Sales America Inc. | BM04B-SRSS-TB | 455-BM04B-SRSS-TBCT-ND |  |  | Harwin Inc. | M40-3010446R | 952-M40-3010446RCT-ND
1 | J304 | Micro SD Card Holder SMD - Flap | WO100HLD0002 | N/A | 472192001 | CONN MICRO SD CARD HINGED TYPE. 8 Position Card Connector, Surface Mount, Right Angle Gold | SMD |  | Sunrom | 6173 | Molex | 47219-2001 | WM6698CT-ND | 538-47219-2001 |  | GCT | MEM2067-02-180-00-A | 2073-MEM2067-02-180-00-ACT-ND
1 | J6 | Programming Header SMD 7x2 1.27mm | WO100CON1141 | N/A | 7X2-SMD-1.27MM-SHROUDED | CONN HEADER SMD VERT 14POS 1.27MM SHROUDED | SMD |  |  |  | CNC Tech | 3220-14-0300-00-TR | 1175-2644-1-ND |  |  | CNC Tech | 3220-14-0300-00 | 1175-1632-ND |  |  | Würth Elektronik | 62731420621 | 732-62731420621CT-ND
3 | LED101, LED102, LED202 | RED | WO100LED0100 |  | L0603 | LED RED CLEAR 0603 SMD | SMD |  | Sunrom | 5215 | Würth Elektronik | 150060RS75000 | 732-4978-1-ND | 710-150060RS75000 |  | Lite-On Inc. | LTST-C190KRKT | 160-1436-1-ND
1 | LED201 | BLUE | WO100LED0200 |  | L0603 | LED BLUE CLEAR 0603 SMD | SMD |  | Sunrom | 5216 | Würth Elektronik | 150060BS75000 | 732-4966-1-ND | 710-150060BS75000
1 | LED401 | RGB 5050 | WO100LED5050 |  | 5050 | LED RGB CLEAR 6PLCC SMD | SMD |  |  |  | Würth Elektronik | 150505M173300 | 732-12000-1-ND |  |  | American Bright Optoelectronics Corporation | BL-HBXJXGX32L | BL-HBXJXGX32LTR-ND
6 | P501, P502, P503, P504, P505, P506 | RA 1 pin |  | POGOPIN_HORIZONTAL_01SMD_MALE | 1X01_SMD_PAD | pogopin horizontal soldering pad | SMD | DNP
3 | Q401, Q402, Q403 | PDTC143ZT,235 | WO100DIO1430 | N/A | TO-236AB | Pre-Biased BJT NPN - 50 V 100 mA R1 = 4.7 kOhm, R2 = 47 kOhm | SMD |  |  |  | Nexperia USA Inc. | PDTC143ZT,235 | 1727-3045-1-ND |  |  | Diodes Incorporated | DDTC143ZCA-7-F | DDTC143ZCA-FDICT-ND
1 | R101 | 100K | WO100RES1040 | 1% | R0603 | RES SMD 100K OHM 1% 1/10W 0603 | SMD |  |  |  | Yageo | RC0603FR-07100KL | 311-100KHRCT-ND |  |  | Bourns Inc. | CR0603-FX-1003ELF | CR0603-FX-1003ELFCT-ND
2 | R102, R104 | 4.7K | WO100RES4720 | 1% | R0603 | RES SMD 4.7K OHM 1% 1/10W 0603 | SMD |  |  |  | Yageo | RC0603FR-074K7L | 311-4.70KHRCT-ND |  |  | Bourns Inc. | CR0603-FX-4701ELF | CR0603-FX-4701ELFCT-ND
10 | R103, R105, R201, R202, R501, R503, R505, R507, R508, R509 | 0E / 0603 | WO100RES0000 | 1% | R0603 | RES SMD 0 OHM JUMPER 1/10W 0603 | SMD |  |  |  | Yageo | RC0603FR-070RL | 311-0.0HRCT-ND |  |  | Bourns Inc. | CR0603-J/-000ELF | CR0603-J/-000ELFCT-ND
2 | R106, R107 | 5.1K | WO100RES5120 | 1% | R0603 | RES SMD 5.1K OHM 1% 1/10W 0604 | SMD |  |  |  | Yageo | RC0603FR-075K1L | 311-5.10KHRCT-ND |  |  | Bourns Inc. | CR0603-FX-5101ELF | CR0603-FX-5101ELFCT-ND
3 | R203, R204, R205 | 1K | WO100RES1030 | 1% | R0603 | RES SMD 1K OHM 1% 1/10W 0603 | SMD |  |  |  | Yageo | RC0603FR-071KL | 311-1.00KHRCT-ND |  |  | Bourns Inc. | CR0603-FX-1001ELF | CR0603-FX-1001ELFCT-ND
9 | R302, R303, R304, R305, R306, R307, R308, R310, R404 | 10K | WO100RES1030 | 1% | R0603 | RES SMD 10K OHM 1% 1/10W 0603 | SMD |  |  |  | Yageo | RC0603FR-0710KL | 311-10.0KHRCT-ND |  |  | Bourns Inc. | CR0603-FX-1002ELF | CR0603-FX-1002ELFCT-ND
1 | R309 | 10M | WO100RES1060 | 1% | R0603 | RES 10M OHM 1% 1/10W 0603 | SMD |  |  |  | Yageo | RC0603FR-0710ML | 311-10.0MHRCT-ND |  |  | Bourns Inc. | CR0603-FW-1005ELF | CR0603-FW-1005ELFCT-ND
2 | R311, R312 | 2.2K | WO100RES2220 | 1% | R0603 | RES SMD 2.2K OHM 1% 1/10W 0603 | SMD |  |  |  | Yageo | RC0603FR-072K2L | 311-2.20KHRCT-ND |  |  | Bourns Inc. | CR0603-FX-2201ELF | CR0603-FX-2201ELFCT-ND
1 | R313 | 1M | WO100RES1050 | 5% | R0603 | RES 1M OHM 5% 1/10W 0603 | SMD |  |  |  | Yageo | RC0603JR-071ML | 311-1.0MGRCT-ND |  |  | Bourns Inc. | CR0603-JW-105ELF | CR0603-JW-105ELFCT-ND
2 | R401, R402 | 100E | WO100RES1010 | 1% | R0603 | RES SMD 100 OHM 1% 1/10W 0603 | SMD |  |  |  | Yageo | RC0603FR-07100RL | 311-100HRCT-ND |  |  | Bourns Inc. | CR0603-FX-1000ELF | CR0603-FX-1000ELFCT-ND
1 | R403 | 390E | WO100RES3910 | 1% | R0603 | RES SMD 390 OHM 1% 1/10W 0603 | SMD |  |  |  | Yageo | RC0603FR-07390RL | 311-390HRCT-ND |  |  | Bourns Inc. | CR0603-FX-3900ELF | CR0603-FX-3900ELFCT-ND
4 | R301, R502, R504, R506 | 10K/DNP |  | RES_USR0603 | R0603 | RESISTOR, American symbol | SMD | DNP
2 | S101, S302 | SWITCH-SPDT-SMD-RIGHT-ANGLE | W0100SWC0002 | N/A | SWITCH_SPST_SMD_A | Single Pole, Double Throw (SPDT) Switch | SMD |  | Sunrom | 4273 | Nidec Copal Electronics | CUS-12TB | 563-1102-1-ND | 229-CUS-12TB |  | C&K | PCM12SMTR | 401-2016-1-ND | 611-PCM12SMTR |  | E-Switch | EG1257 | EG2586CT-ND
1 | S301 | TACT SWITCH (Push Button) | WO100SWC0001 | N/A | TACTILE_SWITCH_SMD_6.0X3.5MM | Momentary Switch (Pushbutton) - SPST | SMD |  | Sunrom | 4388 | C&K | PTS636 SM25F SMTR LFS | CKN12329-1-ND |  |  | Würth Elektronik | 434121043816 | 732-7046-1-ND |  |  | C&K | RS-032G05A3-SM RT | CKN10388CT-ND
5 | TP1, TP2, TP3, TP4, TP5 | TPB1,27 |  | TPB1,27 | B1,27 | Test pad | SMD | DNP
1 | U1 | STM32F103RET6 | WO100MCU1037 | N/A | 64-LQFP | IC MCU 32BIT 512KB FLASH 64LQFP | SMD |  |  |  | ST Microelectronics | STM32F103RET6TR | 497-17387-1-ND |  |  | ST Microelectronics | STM32F103RET6 | 497-6444-ND
1 | U2 | CP2102N-A02-GQFN28R | WO100ICS2103 | N/A | 28-QFN | IC USB TO UART BRIDGE QFN28 | SMD |  |  |  | Silicon Labs | CP2102N-A02-GQFN28R | 336-5890-1-ND |  |  | Silicon Labs | CP2102N-A02-GQFN28 | 336-5889-ND |  |  | Silicon Labs | CP2102-GMR | 336-1160-1-ND
1 | Y1 | 32.768KHz Crystal 12.5pF, SMD Rectangle | WO100OSC1321 | N/A | XTAL_ABS09_ABR-M | CRYSTAL 32.7680KHZ 12.5PF ±20ppm SMD (4.10mm x 1.50mm) | SMD |  | No | N/A | Abracon LLC | ABS09-32.768KHZ-T | 535-9539-1-ND | 815-ABS09-32.768KHZT | C179638 | Citizen Finedevice Co Ltd | CM41532768DZFT | 300-8193-1-ND |  |  | Micro Crystal | CC5V-T1A-32.768kHz-12.5pF-20PPM-TA-QC or CC5V-T1A-32.768kHz-12.5pF-20PPM-TB-QC or ABS07-32.768KHZ-T | 428-200371-MG01 or 428-201665-MG01
1 | Y2 | 8MHz Crystal 18pF, Small 4 SMD | WO100OSC2080 | N/A | 5.00mm x 3.20mm | 8 MHz ±20ppm Crystal 18pF 200 Ohms 4-SMD | SMD |  |  |  | ABRACON | ABM3B-8.000MHZ-B2-T |  |  |  | ECS Inc. | 830055663 | ECS-80-18-30B-JEM-TR |  |  | Würth Elektronik | 830055663
1 | J1 | 1X05_MALE/DNP |  | CONN_05 | 1X05 | Multi connection point. Often used as Generic Header-pin footprint for 0.1 inch spaced/style header connections | THT | DNP
1 | J3 | 1X04_MALE/DNP |  | CONN_04PTH | 1X04 | Multi connection point. Often used as Generic Header-pin footprint for 0.1 inch spaced/style header connections | THT | DNP
2 | J4, J5 | 1X03_MALE/DNP |  | CONN_03 | 1X03 | Multi connection point. Often used as Generic Header-pin footprint for 0.1 inch spaced/style header connections | THT | DNP
1 | S401 | TACT SWITCH BIG 12x12mm (Push Button) | WO100SWT0012 | N/A | TACTILE_SWITCH_THT_12.0x12.0MM | Tactile Switch SPST-NO Top Actuated Though Hole 12x12mm | THT |  | Sunrom | 4338 | Omron Electronics Inc-EMC Div | B3F-4055 | SW414-ND |  | C84931 | C&K | PTS125SJK73P21M LFS | 108-PTS125SJK73P21MLFS-ND
2 | TP6, TP7 | 5004 |  | 5004 | 5004 | KEYSTONE - 5004 - TEST POINT, PCB, THROUGH HOLE | THT | DNP
1 | X1 | B4B-XH-A(LF)(SN) PCB connector | WO200CON0040 | N/A | JST Connector B4B-XH-A | CONN JST HEADER VERT 4POS 2.5MM | THT |  | Sunrom | 5225 | Adam Tech | 25SH-B-04-TS | 2057-25SH-B-04-TS-ND |  |  | JST Sales America Inc. | B4B-XH-AM(LF)(SN) |  |  |  | CNC Tech | 51025-04-0100-01 | 1175-51025-04-0100-01-ND
2 | X2, X4 | B3B-XH-A(LF)(SN) PCB connector | WO200C0N0030 | N/A | JST Connector B3B-XH-A | CONN JST HEADER VERT 3POS 2.5MM | THT |  | Sunrom | 5223 | Adam Tech | 25SH-B-03-TS | 2057-25SH-B-03-TS-ND |  |  | JST Sales America Inc. | B3B-XH-AM(LF)(SN) |  |  |  | CNC Tech | 51025-02-0100-01 | 1175-51025-02-0100-01-ND
1 | X3 | B5B-XH-A(LF)(SN) PCB connector | WO200CON0050 | N/A | JST Connector B5B-XH-A | CONN JST HEADER VERT 5POS 2.5MM | THT |  | Sunrom | 5226 | Adam Tech | 25SH-B-05-TS | 2057-25SH-B-05-TS-ND |  |  | JST Sales America Inc. | B5B-XH-AM(LF)(SN) |  |  |  | CNC Tech | 51025-04-0100-01 | 1175-51025-04-0100-01-ND
1 | X5 | S6B-XH-A(LF)(SN) R/A PCB connector | WO200CON0061 | N/A | JST Connector S6B-XH-A | CONN JST HEADER R/A 6POS 2.5MM | THT |  | Sunrom | 5654 | Adam Tech | 25SH-B-06-TR | 2057-25SH-B-06-TR-ND |  |  | JST Sales America Inc. | S6B-XH-A(LF)(SN) |  |  |  | CNC Tech | 51125-06-0200-01

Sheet: Sheet2
Qty | Parts | Value | PN | Tol | Package | Description | is SMD or THT? | is DNP?
4 | C101, C103, C104, C106 | 1uF |  | CAP_USC0603 | C0603 | Generic SMD MLCC Capacitor | SMD
2 | C102, C105 | 22nF |  | CAP_USC0603 | C0603 | Generic SMD MLCC Capacitor | SMD
2 | C201, C202 | 4.7uF |  | CAP_USC0603 | C0603 | Generic SMD MLCC Capacitor | SMD
2 | C301, C302 | 15pF |  | CAP_USC0603 | C0603 | Generic SMD MLCC Capacitor | SMD
2 | C303, C304 | 27pF |  | CAP_USC0603 | C0603 | Generic SMD MLCC Capacitor | SMD
7 | C305, C306, C307, C308, C309, C310, C401 | 100nF |  | CAP_USC0603 | C0603 | Generic SMD MLCC Capacitor | SMD
1 | D101 | DRTR5V0U2SR-7 |  | PRTR5V0U2X,215 | PRTR5V0U2X | ESD Protection Diodes 5.5V Dual SOT143B NXP PRTR5V0U2X,215 Dual Uni-Directional TVS Diode, 4-Pin SOT-143B | SMD
2 | D102, D501 | SDM2U20SD3-7 |  | SDM2U20SD3-7 | SOD2513X120N | Schottky Diodes & Rectifiers 2A Schottky 20Vrrm 2A 0.525Vf 200uA | SMD
2 | D301, D401 | ESDALC6V1-1U2 |  | ESDALC6V1-1U2 | ESDALC6V11U2 | STMicroelectronics ESDALC6V1-1U2, Uni-Directional TVS Diode, 20W, 2-Pin ST-0201 | SMD
1 | F101 | MF-NSML300/6-2 |  | 1206L300SLTHYR | 1206L075SLYR | Low Rho Surface Mount Resettable PTC Fuse | SMD
2 | IC101, IC102 | RT9193-33GB |  | RT9193-33GB | SOT94P279X130-5N | 300mA, Ultra-Low Noise, Ultra-Fast CMOS LDO Regulator | SMD
1 | J101 | 12402012E212A |  | 12402012E212A | AMPHENOL_12402012E212A | Type C USB - SMD - Data + Power 13 pin | SMD
1 | J2 | Vertical Qwiic Connector |  | QWIIC_CONNECTOR | JST04_1MM_VERT | SparkFun I2C Standard Qwiic Connector | SMD
1 | J304 | 47219-2001 |  | 47219-2001 | 472192001 | Molex 47219 Series 8 Way Horizontal Hinged Micro SD Memory Card Connector with Solder Termination | SMD
1 | J6 | 3220-14-0300-00 |  | 3220-14-0300-00 | 322014030000 | IDC BOX HEADER 0.050 14 POS | SMD
3 | LED101, LED102, LED202 | RED |  | LED_CHIP_0603 | LED_CHIP_0603 | LED - GENERIC. 0603, 0808, 1206 package | SMD
1 | LED201 | BLUE |  | LED_CHIP_0603 | LED_CHIP_0603 | LED - GENERIC. 0603, 0808, 1206 package | SMD
1 | LED401 | 150505M173300 |  | 150505M173300 | 150505M173300 | 2.4 V RGB LED 5050 SMD, Wurth Elektronik WL-SFTW 150505M173300 | SMD
6 | P501, P502, P503, P504, P505, P506 | RA 1 pin |  | POGOPIN_HORIZONTAL_01SMD_MALE | 1X01_SMD_PAD | pogopin horizontal soldering pad | SMD | DNP
3 | Q401, Q402, Q403 | DDTC143ZCA-7-F |  | DDTC143ZCA-7-F | SOT96P240X110-3N | Diodes Inc, DDTC143ZCA-7-F NPN Digital Transistor, 100 mA 50 V Ratio Of 4.7 k, 3-Pin SOT-23 | SMD
1 | R101 | 100K |  | RES_USR0603 | R0603 | RESISTOR, American symbol | SMD
2 | R102, R104 | 4.7K |  | RES_USR0603 | R0603 | RESISTOR, American symbol | SMD
10 | R103, R105, R201, R202, R501, R503, R505, R507, R508, R509 | 0E |  | RES_USR0603 | R0603 | RESISTOR, American symbol | SMD
2 | R106, R107 | 5.1K |  | RES_USR0603 | R0603 | RESISTOR, American symbol | SMD
3 | R203, R204, R205 | 1K |  | RES_USR0603 | R0603 | RESISTOR, American symbol | SMD
1 | R301 | 10K/DNP |  | RES_USR0603 | R0603 | RESISTOR, American symbol | SMD | DNP
9 | R302, R303, R304, R305, R306, R307, R308, R310, R404 | 10K |  | RES_USR0603 | R0603 | RESISTOR, American symbol | SMD
1 | R309 | 10M |  | RES_USR0603 | R0603 | RESISTOR, American symbol | SMD
2 | R311, R312 | 2K2 |  | RES_USR0603 | R0603 | RESISTOR, American symbol | SMD
1 | R313 | 1M |  | RES_USR0603 | R0603 | RESISTOR, American symbol | SMD
2 | R401, R402 | 100E |  | RES_USR0603 | R0603 | RESISTOR, American symbol | SMD
1 | R403 | 390E |  | RES_USR0603 | R0603 | RESISTOR, American symbol | SMD
3 | R502, R504, R506 | 10K/DNP |  | RES_USR0603 | R0603 | RESISTOR, American symbol | SMD | DNP
2 | S101, S302 | PCM12SMTR |  | PCM12SMTR | PCM12SMTR | Slide Switches 0.3A SPDT ON-ON | SMD
1 | S301 | PTS636 SK25F SMTR LFS |  | PTS636SK25FSMTRLFS-SMD-6.0X3.5MM | TACTILE_SWITCH_SMD_6.0X3.5MM | Momentary Switch (Pushbutton) - SPST | SMD
5 | TP1, TP2, TP3, TP4, TP5 | TPB1,27 |  | TPB1,27 | B1,27 | Test pad | SMD | DNP
1 | U1 | STM32F103RET6TR |  | STM32F103RET6TR | QFP50P1200X1200X160-64N | MCU 32-bit ARM Cortex M3 RISC 512KB Flash 2.5V/3.3V 64-Pin LQFP T/R | SMD
1 | U2 | CP2102N-A02-GQFN28R |  | CP2102N-A02-GQFN28R | QFN50P500X500X80-29N | USB Interface IC USB to UART bridge - QFN28 | SMD
1 | Y1 | ABS09-32.768KHZ-T |  | ABS09-32.768KHZ-TXTAL_ABS09_ABR-M | XTAL_ABS09_ABR-M |  | SMD
1 | Y2 | ABM3B-8.000MHZ-B-2-T |  | ABM3B-8.000MHZ-B-2-T | ABM3B8000MHZB2T | Abracon Crystal +/-10ppm SMD 5 x 3 x 1.1mm | SMD
1 | J1 | 1X05_MALE/DNP |  | CONN_05 | 1X05 | Multi connection point. Often used as Generic Header-pin footprint for 0.1 inch spaced/style header connections | THT | DNP
1 | J3 | 1X04_MALE/DNP |  | CONN_04PTH | 1X04 | Multi connection point. Often used as Generic Header-pin footprint for 0.1 inch spaced/style header connections | THT | DNP
2 | J4, J5 | 1X03_MALE/DNP |  | CONN_03 | 1X03 | Multi connection point. Often used as Generic Header-pin footprint for 0.1 inch spaced/style header connections | THT | DNP
1 | S401 | B3F-4055 |  | B3F-4055 | B3F-4055 | Yellow Plunger Tactile Switch, SPST-NO 0.05 A@ 24 V dc 3mm | THT
2 | TP6, TP7 | 5004 |  | 5004 | 5004 | KEYSTONE - 5004 - TEST POINT, PCB, THROUGH HOLE | THT | DNP
1 | X1 | B4B-XH-A |  | B4B-XH-A | B4B-XH-A | JST XH series header 2.50mm pitch disconnectable crimp style connectors, vertical (side entry type), 4 pins | THT
2 | X2, X4 | B3B-XH-A |  | B3B-XH-A | B3B-XH-A | JST XH series header 2.50mm pitch disconnectable crimp style connectors, vertical (side entry type), 3 pins | THT
1 | X3 | B5B-XH-A |  | B5B-XH-A | B5B-XH-A | JST XH series header 2.50mm pitch disconnectable crimp style connectors, vertical (side entry type), 5 pins | THT
1 | X5 | S6B-XH-A |  | S6B-XH-A | S6B-XH-A | JST XH series header 2.50mm pitch disconnectable crimp style connectors, horizontal (side entry type), 6 pins | THT

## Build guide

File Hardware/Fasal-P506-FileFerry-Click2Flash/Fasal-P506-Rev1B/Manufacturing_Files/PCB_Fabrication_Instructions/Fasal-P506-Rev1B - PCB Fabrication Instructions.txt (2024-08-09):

===========================================================
PCB Name: Fasal-P506-Rev1B
Customer: Wolkus Technology Solutions Private Limited
===========================================================
===========================================================
(A) PCB Fabrication Details
===========================================================
Fabrication Class:	IPC Class 2
PCB Base Material:	FR4
Board TG:		Middle Tg (150 to 160 C)
PCB Thickness:		1.6 mm (+/- 0.2mm) post finish
Copper weight:		1oz / 35um
Solder Mask:		Red
Silkscreen Color:	White
Surface Finish:		Lead Free RoHS
Impedance Control:	Yes
Via Fill:		No
Flying Probe Test:	Fully Test
Manufacturing Datecode:	Yes (see notes section)
PCB Test Report:	Yes

===========================================================	
(B) PCB Technical details	
===========================================================
layers: 		4
controlled Impedance	Yes
Stackup:		JLC7628 Stackup	
minimum trace width: 	>=10 mil	
minimum trace spacing: 	>=10 mil	
minimum drill size: 	0.25 mm	
width: 			140 mm	
height: 		40 mm

Drill size 3mm and above are NPTH

===========================================================
(C) NOTES: UNLESS OTHERWISE SPECIFIED
===========================================================
1. FABRICATE PER IPC-6012A CLASS 2. UNLESS OTHERWISE SPECIFIED IN ABOVE SECTION (A).
2. FOR BOARD THICKNESS AND IMPEDANCE DETAILS REFER ABOVE SECTION (A).
3. SURFACE FINISH: AS SPECIFIED IN ABOVE SECTION (A).
4. SOLDERMASK ON BOTH SIDES OF THE BOARD SHALL BE LPI, COLOR WILL BE GREEN UNLESS OTHERWISE SPECIFIED IN ABOVE SECTION (A).
5. SILK SCREEN LEGEND TO BE APPLIED PER LAYER STACKUP USING NON-CONDUCTIVE EPOXY INK. COLOR WILL BE WHITE UNLESS OTHERWISE SPECIFIED IN ABOVE SECTION (A).
6. ALL VIAS ARE TENTED ON BOTH SIDES UNLESS SOLDERMASK OPENED IN GERBER.
7. ALL HOLES SHALL BE LOCATED WITHIN 0.1MM DIAMETER OF TRUE POSITION.
8. VENDOR SHOULD FOLLOW ROHS COMPLIANT PROCESS AND Pb FREE FOR MANUFACTURING
9. MANUFACTURER'S IDENTIFICATION, DATECODE LETTER SHALL BE SILKSCREENED ON BOTTOM SIDE OF THE BOARD. THE FORMATTING TO BE VERIFIED BEFORE PRODUCTION.
10. TRACE WIDTH SHOULD BE ACCURATELY ETCHED. MAX TOLERANCE +/- 1 MIL
11. ALL DIMENSIONS ARE IN MM UNLESS OTHERWISE SPECIFIED.
12. FLATNESS REQUIREMENTS:
	A. BOW AND TWIST OF ASSEMBLY SUB-PANEL OR SINGULATED PCB SHALL NOT EXCEED 0.9% OF LONGEST SIDE
	B. TEST IN ACCORDANCE WITH THE CURRENT REVISION OF IPC-TM-650 2.4.22
13. PCB MATERIAL REQUIREMENTS:
	A. FLAMMABILITY RATING MUST MEET OR EXCEED UL94V-0 REQUIREMENTS. PCB MUST BEAR THE UL94V-0 REGISTERED MATERIAL ID NUMBER.
	B. Tg 160 TO 170 C OR EQUIVALENT. UNLESS OTHERWISE SPECIFIED IN ABOVE SECTION (A).
	C. EQUIVALENT MATERIAL SHALL BE RoHS COMPLIANT, HALOGEN FREE AND APPROVED BY US.
14. LAYER TO LAYER REGISTRATION SHALL BE WITHIN +/-2 MIL
15. MANUALLY ADD DATECODE TO THE PCB ON THE SILK SCREEN LAYER BY THE FABRICATOR. FABRICATOR SPECIFIC FORMAT IS ACCEPTABLE UNLESS OTHERWISE SPECIFIED BY US.

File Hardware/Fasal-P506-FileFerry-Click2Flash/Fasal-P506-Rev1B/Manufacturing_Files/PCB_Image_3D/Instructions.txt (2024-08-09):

You can view the 3D STEP file for free at: https://viewer.autodesk.com/

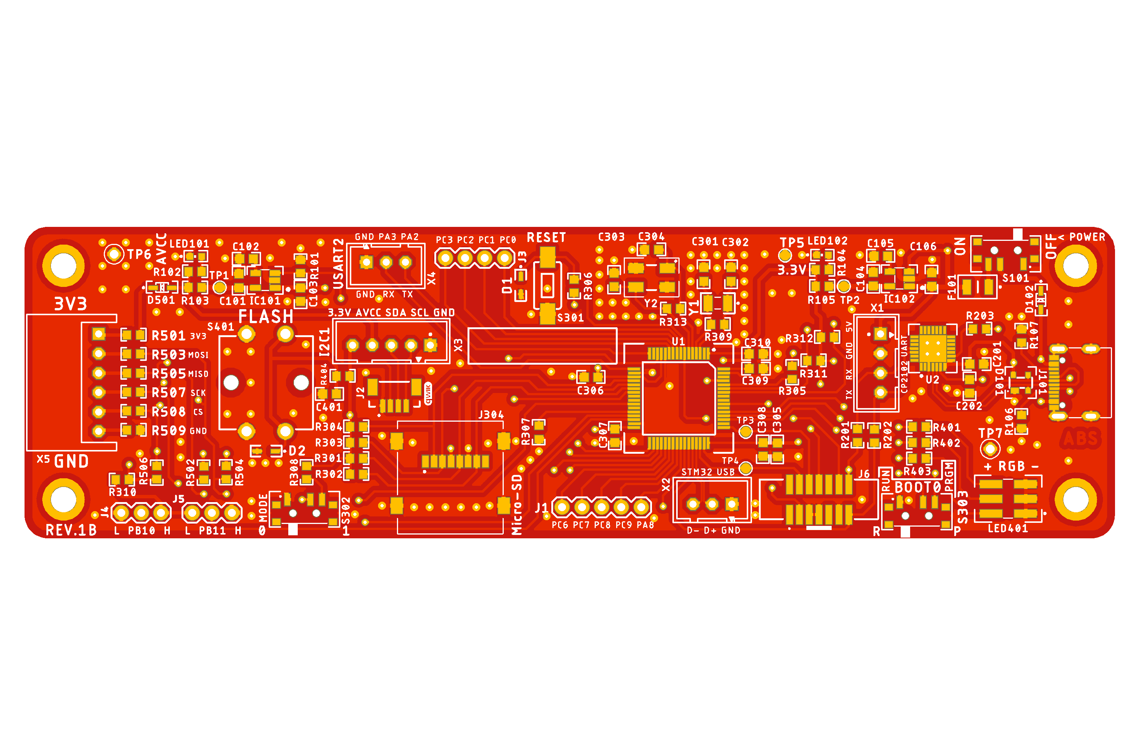
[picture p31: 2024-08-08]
Hardware/Fasal-P506-FileFerry-Click2Flash/Fasal-P506-Rev1B/Manufacturing_Files/PCB_Image_3D/Fasal-P506-Rev1B-SPI_Flash_Writer_Jig - PCB_TOP.png

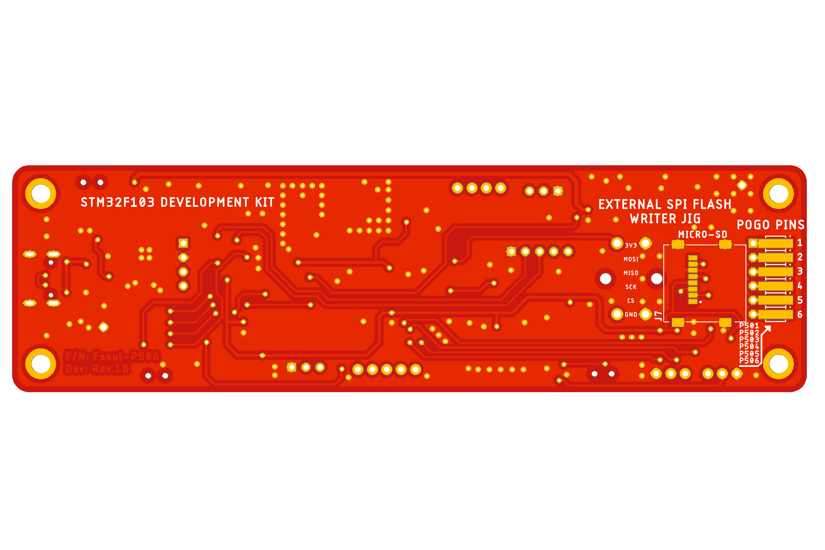
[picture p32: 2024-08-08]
Hardware/Fasal-P506-FileFerry-Click2Flash/Fasal-P506-Rev1B/Manufacturing_Files/PCB_Image_3D/Fasal-P506-Rev1B-SPI_Flash_Writer_Jig - PCB_BOTTOM.png

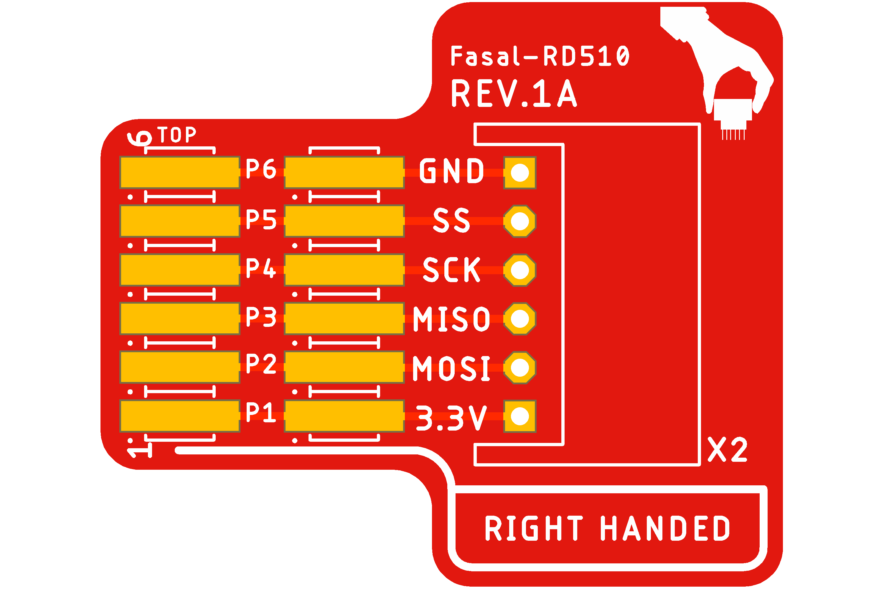
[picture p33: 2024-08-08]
Hardware/Fasal-RD510-external-pogo pcb/Fasal-RD510-Rev1A/Manufacturing_Files/PCB_Fabrication_Instructions/Fasal-RD510-Rev1A - SPI Flash Writer pogo pcb-PCB_TOP.png

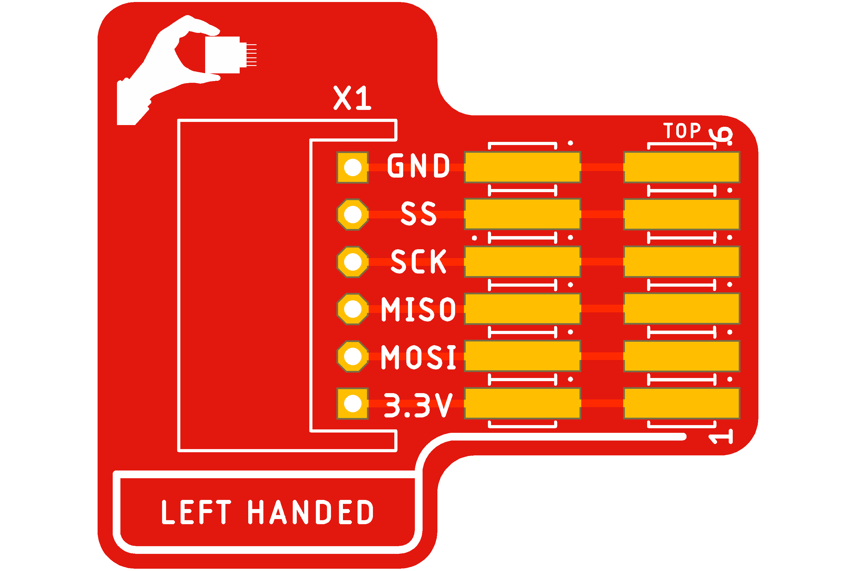
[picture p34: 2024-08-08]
Hardware/Fasal-RD510-external-pogo pcb/Fasal-RD510-Rev1A/Manufacturing_Files/PCB_Fabrication_Instructions/Fasal-RD510-Rev1A - SPI Flash Writer pogo pcb-PCB_BOTTOM.png

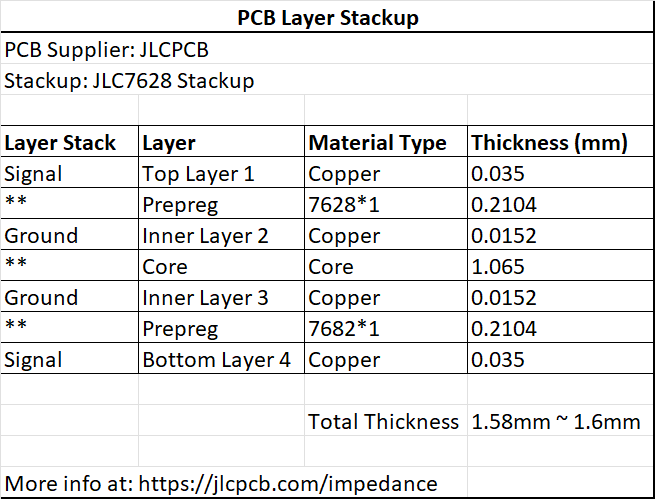
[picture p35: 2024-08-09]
Hardware/Fasal-P506-FileFerry-Click2Flash/Fasal-P506-Rev1B/Manufacturing_Files/PCB_Fabrication_Instructions/PCB_Layer_Stackup.png

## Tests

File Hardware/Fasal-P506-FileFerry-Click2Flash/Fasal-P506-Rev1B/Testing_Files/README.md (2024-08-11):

# FileFerry-Click2Flash - Testing Files #

This directory will contains the board bring-up report as well as the Arduino testing code

# Test Code #
Software: Arduino IDE 2.3.0
STM32 Core: Official STM32 Arduino Core

# Repository Contents #
* The board Bring-up Code contains the arduino code as well as compined binaries
* The Board Bring-up report is a word document having the test conditions of the bring-up

## Why Arduino? ##
* This code is written by a Electronics Engineer.
* The production code is in the official STM32Cube IDE
* Arduino is quick to tinker, for the sake of board bring-up. It is easy to use and this electronics engineer believes that it is more than sufficient to test a new PCBA for bring-up activities.

## Wroking ##
The Arduino code (Sketch) is simple. It does the following:
* Prints a welcome message
* Blinks the RGB LED through various colors (7 color combination)
* Increments a counter
* Interrupt function that prints a "Button pressed" messade everytime the user button is pressed

## Screenshots ##
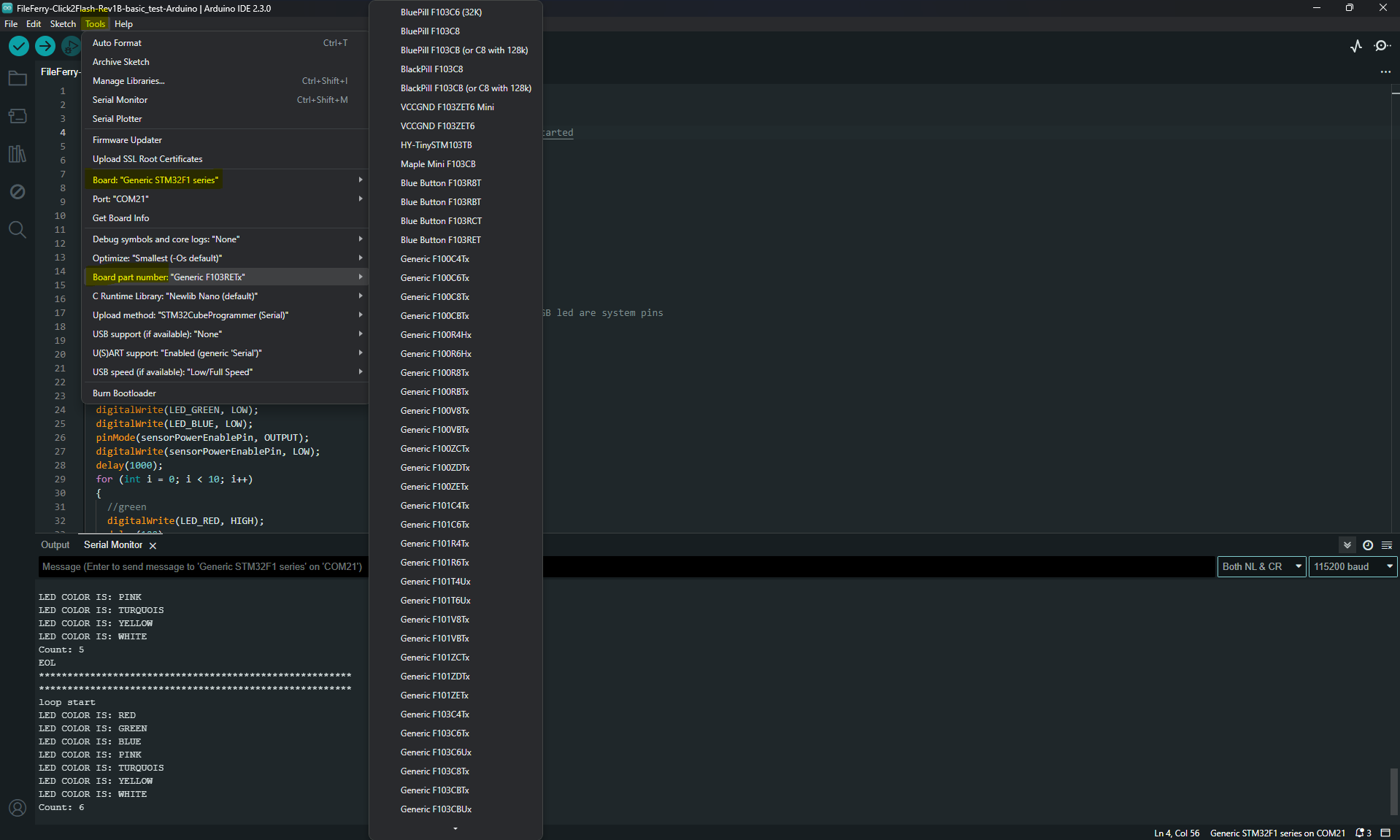
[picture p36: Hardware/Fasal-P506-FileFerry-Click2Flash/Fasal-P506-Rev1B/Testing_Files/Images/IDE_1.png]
IDE 1

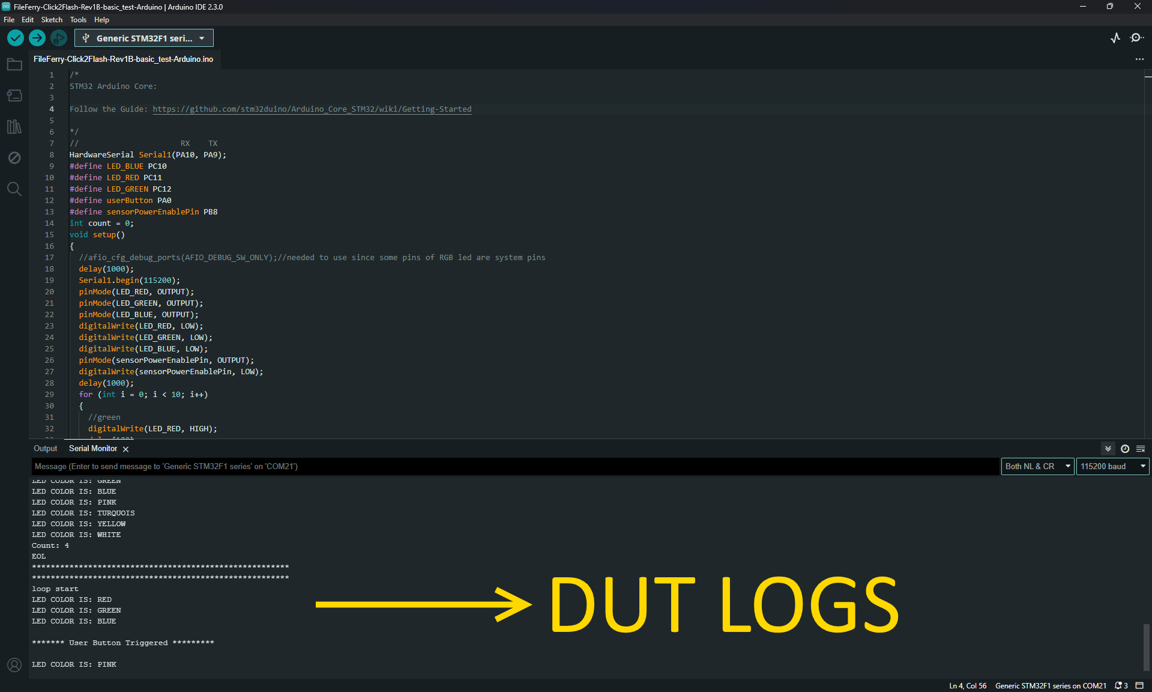
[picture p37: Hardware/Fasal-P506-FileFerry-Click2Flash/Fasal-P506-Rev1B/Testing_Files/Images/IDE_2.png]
IDE 2


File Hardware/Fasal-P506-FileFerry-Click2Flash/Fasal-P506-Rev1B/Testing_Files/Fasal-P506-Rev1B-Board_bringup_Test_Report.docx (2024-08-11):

Author: Abhay Bharadwaj

Test Cases

Test Case | Expected Result | P506.R1B-01 XXX044398 | P506.R1B-02 XXX044281 | P506.R1B-03 XXX044307 | P506.R1B-04 XXX044323 | P506.R1B-05 XXX044414
Basic Tests | | PASS | PASS | PASS | PASS | PASS
3V3 REG (V) IC102 Out | 3.27 to 3.35 V | 3.299v Pass | 3.276v Pass | 3.302v Pass | 3.286v Pass | 3.298v Pass
AVCC REG (V) IC101 Out | 3.27 to 3.35 V | 3.301v Pass | 3.293v Pass | 3.302v Pass | 3.273v Pass | 3.291v Pass
RGB LED | Blink RGB LED | Pass | Pass | Pass | Pass | Pass
USART1 Debug Print | Debug Print | Pass | Pass | Pass | Pass | Pass
User Button | Check Interrupt of user button (Check on Serial Print) | Pass | Pass | Pass | Pass | Pass
Advance Tests | | YTA | YTA | YTA | YTA | YTA
I2C Test | Check I2C sensor
SPI | Read from SD Card
USART2 | File Transfer on USART2

Issues Observed

SL# | Issue Type | Issue Description | Possible Solution
1 | Design
2 | Component

© Wolkus Technology Solutions Private Limited | Bangalore

Project: Fasal-P506 – FileFerry-Click2Flash| Rev.1B Document: Board Bring-up and Testing observations

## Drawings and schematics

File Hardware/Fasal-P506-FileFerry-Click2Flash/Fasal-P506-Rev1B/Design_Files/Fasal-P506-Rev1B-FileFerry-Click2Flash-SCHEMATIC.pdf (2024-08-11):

## USB

## System

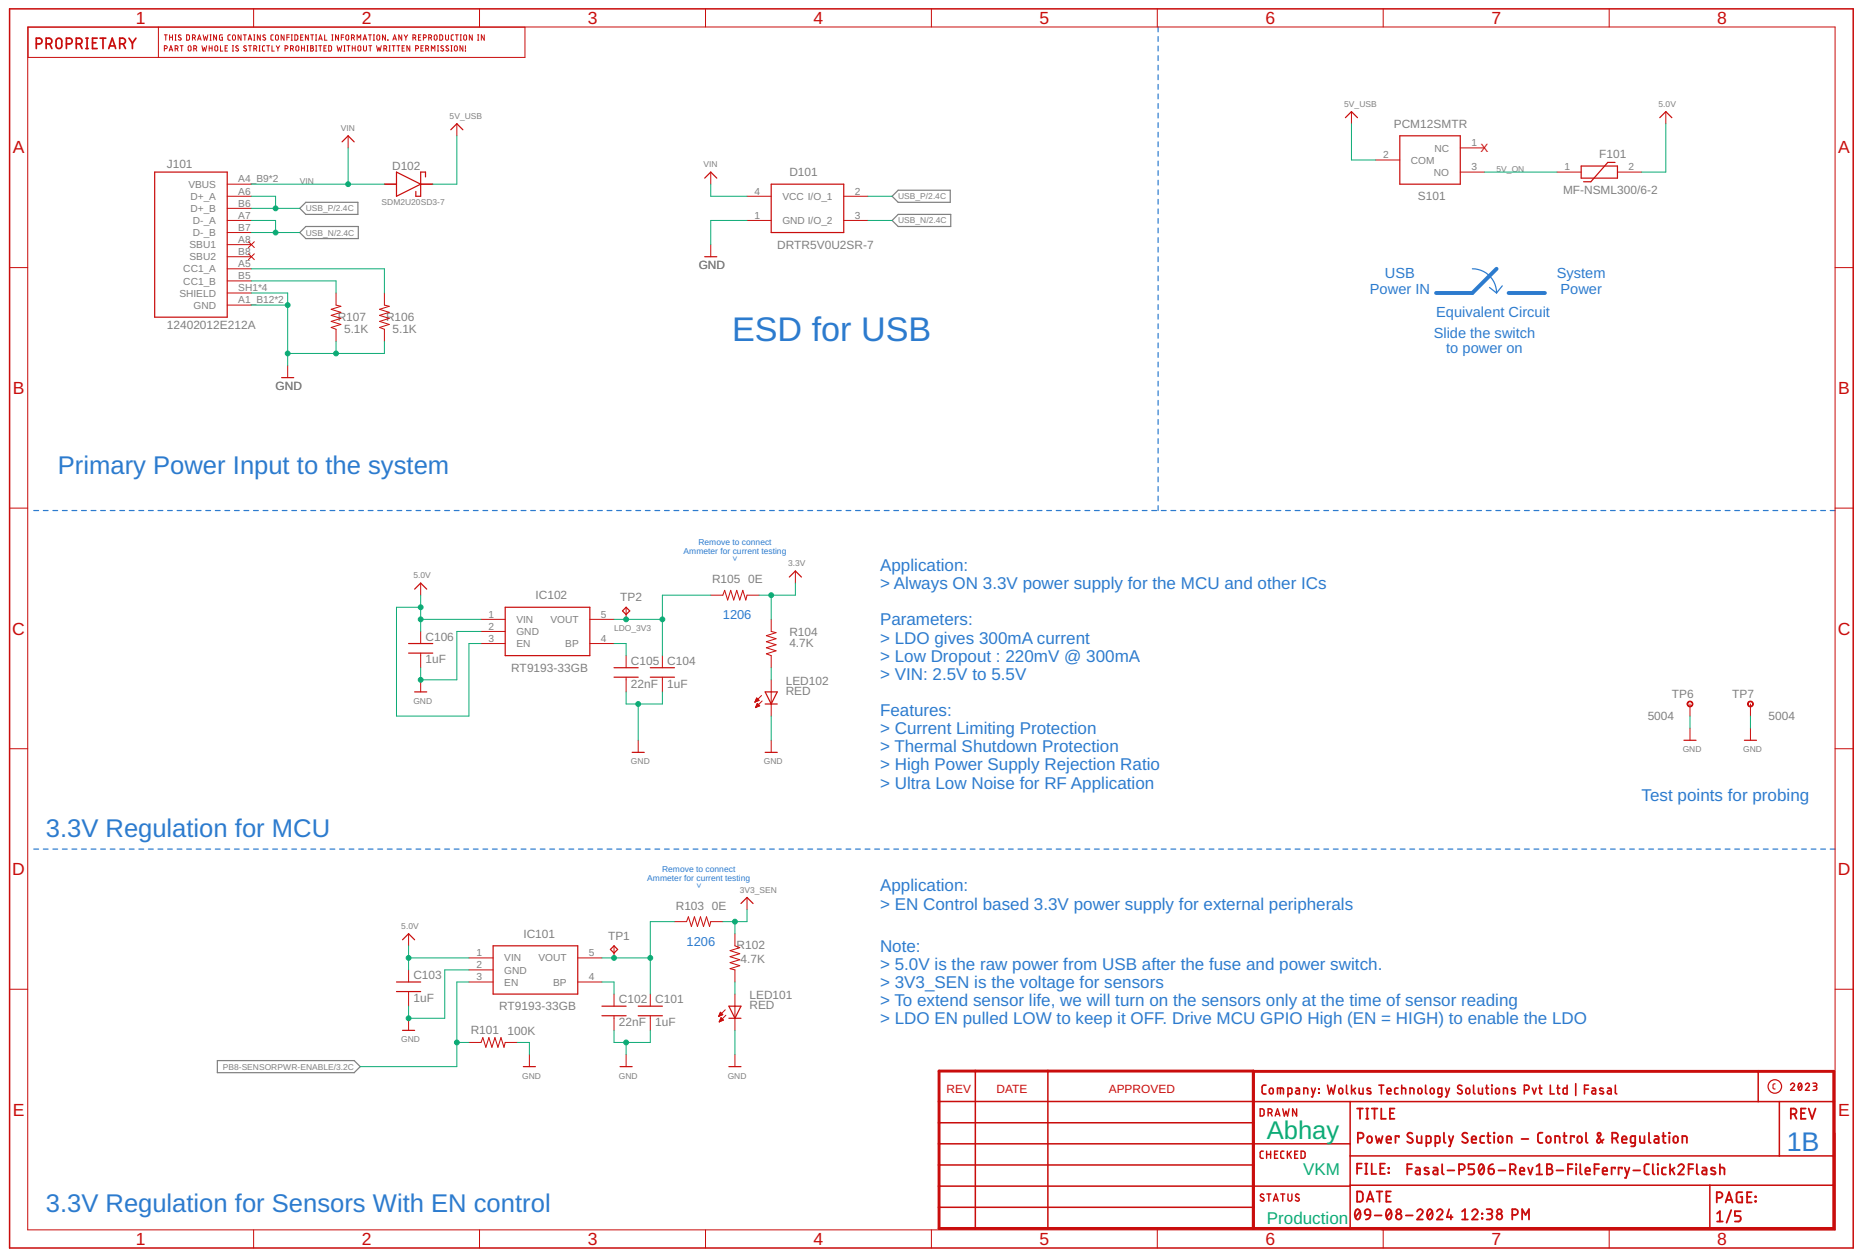
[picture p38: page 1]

Primary Power Input to the system

Application:
> Always ON 3.3V power supply for the MCU and other ICs

Features:
> Current Limiting Protection
> Thermal Shutdown Protection
> High Power Supply Rejection Ratio
> Ultra Low Noise for RF Application

Test points for probing

> EN Control based 3.3V power supply for external peripherals

> 5.0V is the raw power from USB after the fuse and power switch. > 3V3_SEN is the voltage for sensors

> To extend sensor life, we will turn on the sensors only at the time of sensor reading
> LDO EN pulled LOW to keep it OFF. Drive MCU GPIO High (EN = HIGH) to enable the LDO

Abhay | 1B

VKM

3.3V Regulation for Sensors With EN control

Production

A

A

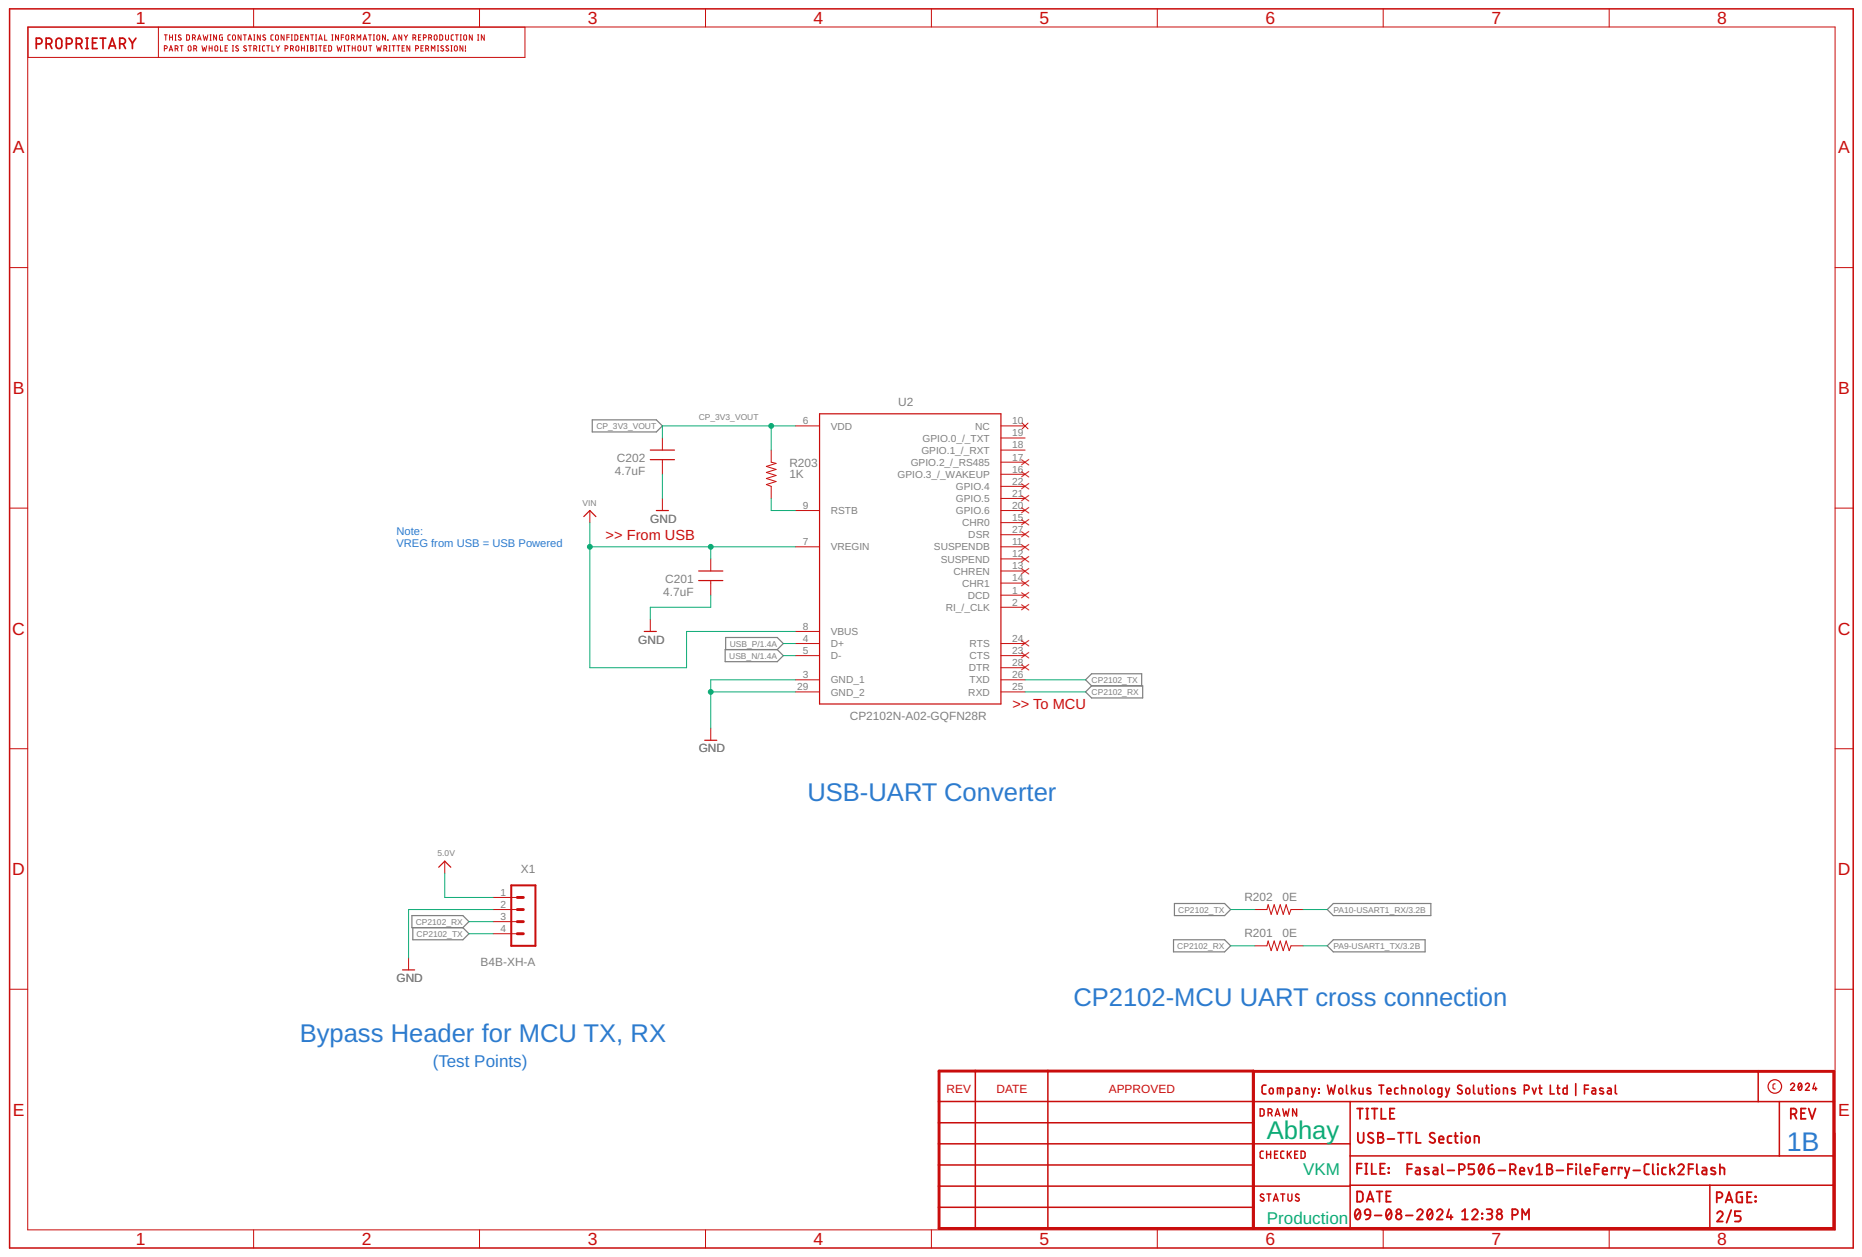
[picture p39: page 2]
(Test Points); CP2102N-A02-GQFN28R; GND; VIN; DCD; 1 RI_/_CLK 2 GND_1; VDD; VREGIN; VBUS; RSTB; SUSPENDB; 11 SUSPEND 12 CHREN 13 CHR1 14; GPIO.5; 21 GPIO.6 20; GPIO.0_/_TXT; 19 GPIO.1_/_RXT 18 GPIO.2_/_RS485 17 GPIO.3_/_WAKEUP 16 CHR0; GND_2; DTR; DSR; TXD; 26 RXD; 25 RTS; 24 CTS 23; GPIO.4; CP_3V3_VOUT CP_3V3_VOUT; USB_P/1.4A USB_N/1.4A; PA10-USART1_RX/3.2B; PA9-USART1_TX/3.2B; >> From USB; X X X X X X X X X X X X X X X X >> To MCU

Note: VREG from USB = USB Powered

USB-UART Converter

CP2102-MCU UART cross connection

Bypass Header for MCU TX, RX

REV | DATE | APPROVED

Abhay | 1B

VKM

## Programming and Debugging Header

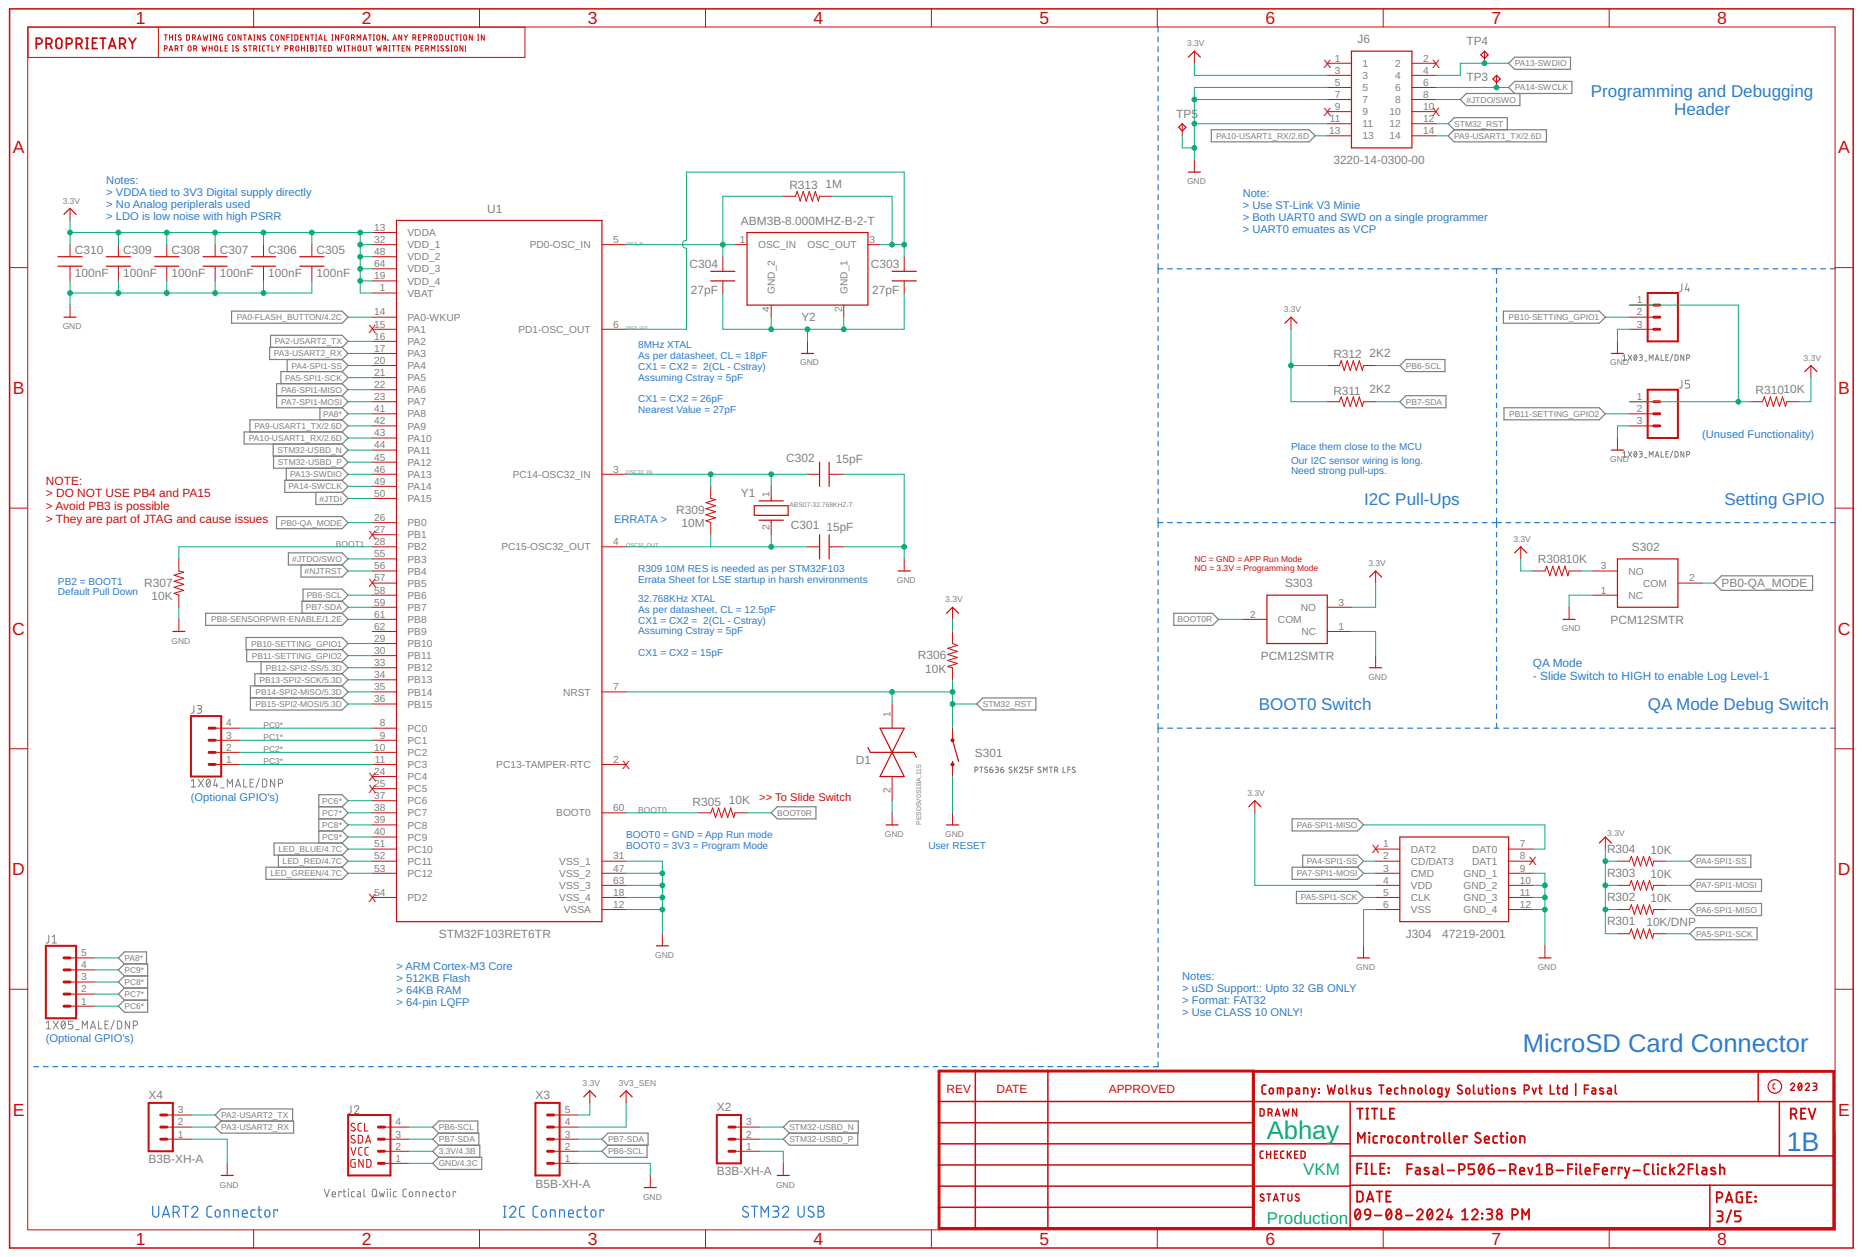
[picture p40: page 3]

Notes: > VDDA tied to 3V3 Digital supply directly > No Analog periplerals used > LDO is low noise with high PSRR

Note: > Use ST-Link V3 Minie > Both UART0 and SWD on a single programmer > UART0 emuates as VCP

OSC8_OUT
8MHz XTAL As per datasheet, CL = 18pF CX1 = CX2 = 2(CL - Cstray) Assuming Cstray = 5pF CX1 = CX2 = 26pF Nearest Value = 27pF

Place them close to the MCU Our I2C sensor wiring is long. Need strong pull-ups.

NC = GND = APP Run Mode NO = 3.3V = Programming Mode

R309 10M RES is needed as per STM32F103 Errata Sheet for LSE startup in harsh environments

32.768KHz XTAL As per datasheet, CL = 12.5pF CX1 = CX2 = 2(CL - Cstray) Assuming Cstray = 5pF CX1 = CX2 = 15pF

QA Mode
- Slide Switch to HIGH to enable Log Level-1

QA Mode Debug Switch

User RESET BOOT0 = GND = App Run mode BOOT0 = 3V3 = Program Mode

> Format: FAT32 > Use CLASS 10 ONLY! > ARM Cortex-M3 Core > 512KB Flash > 64KB RAM

Notes: > uSD Support:: Upto 32 GB ONLY

REV | DATE | APPROVED

Abhay | 1B

VKM

A

A

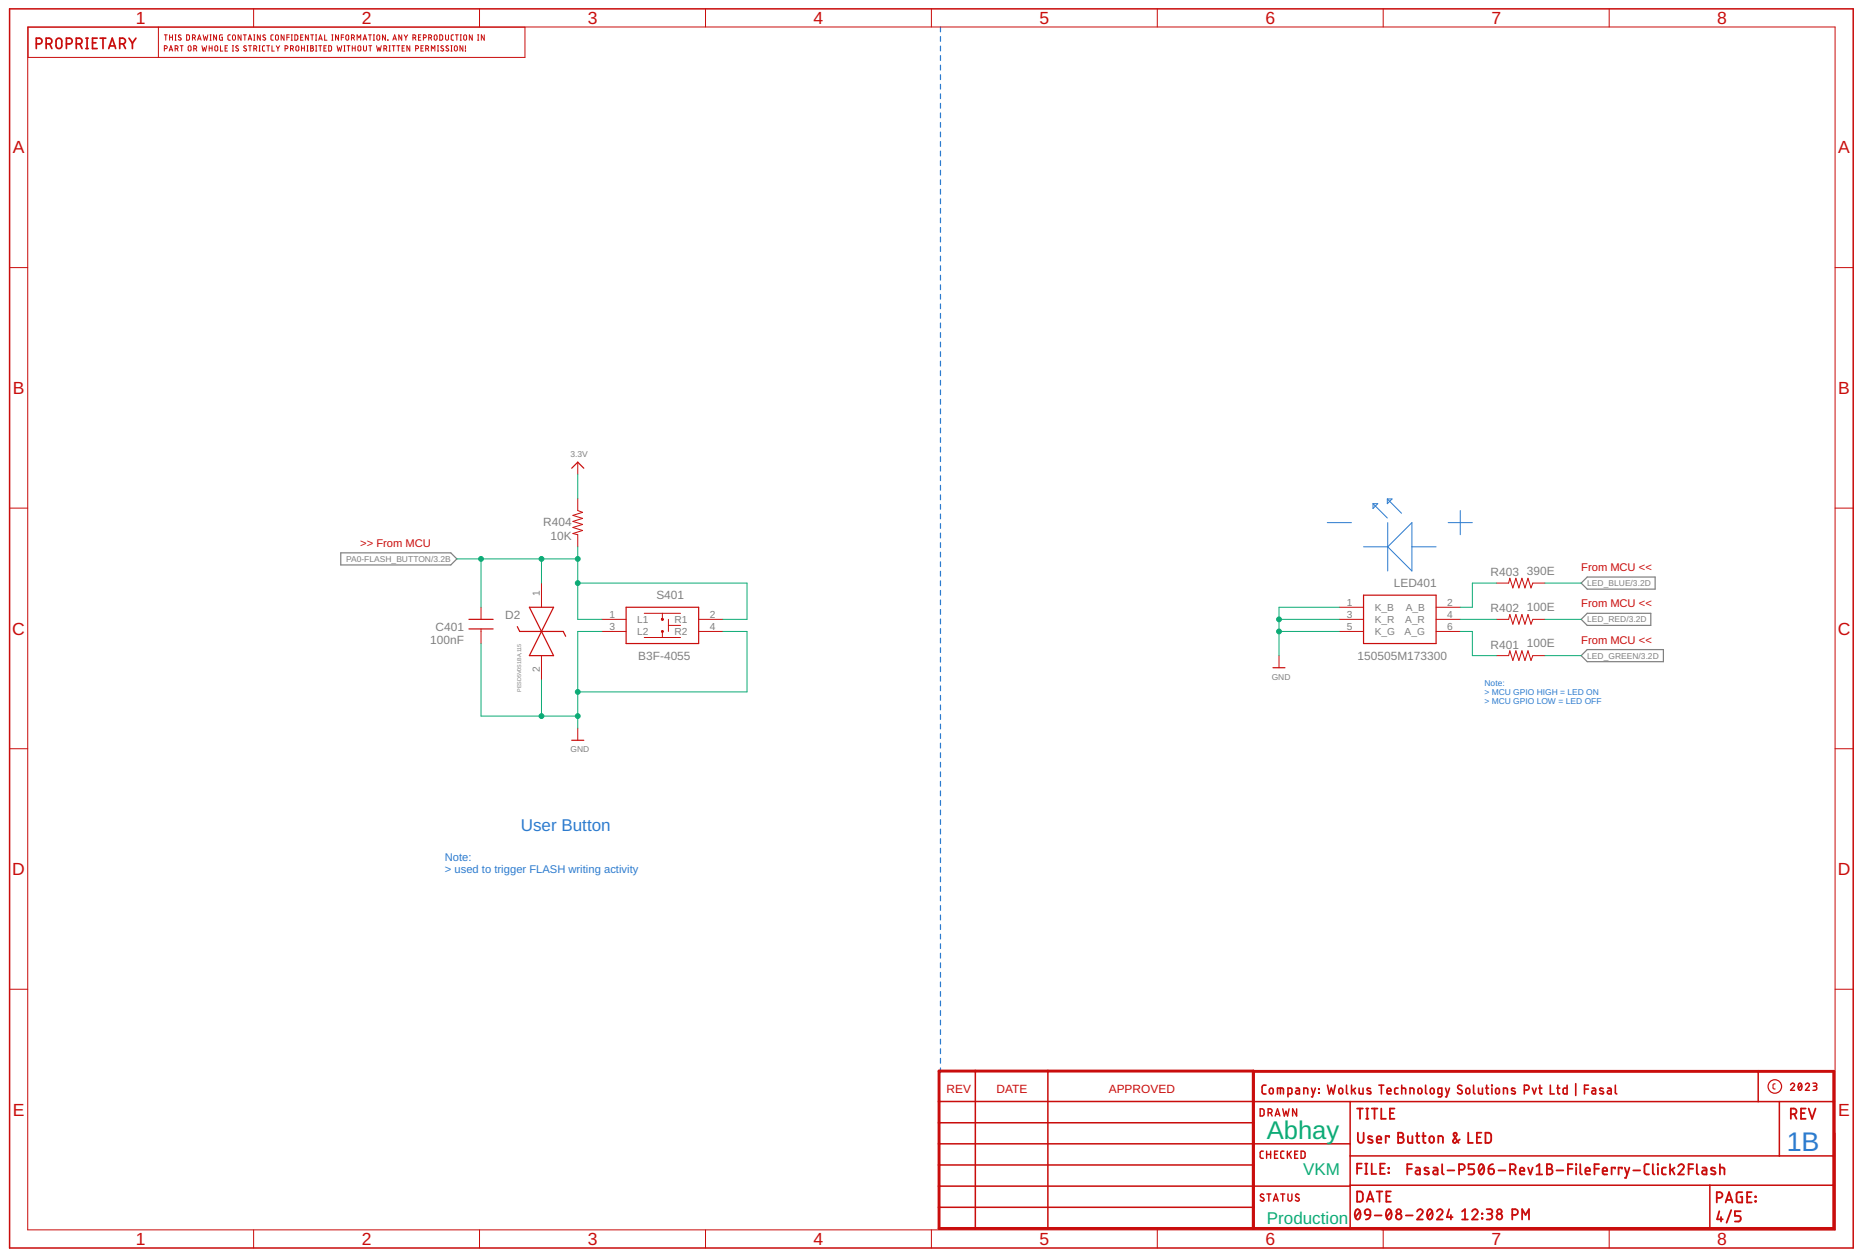
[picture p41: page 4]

From MCU << From MCU << From MCU <<

Note: > MCU GPIO HIGH = LED ON

> MCU GPIO LOW = LED OFF User Button

Note: > used to trigger FLASH writing activity

REV | DATE | APPROVED

Abhay | 1B

VKM

A

A

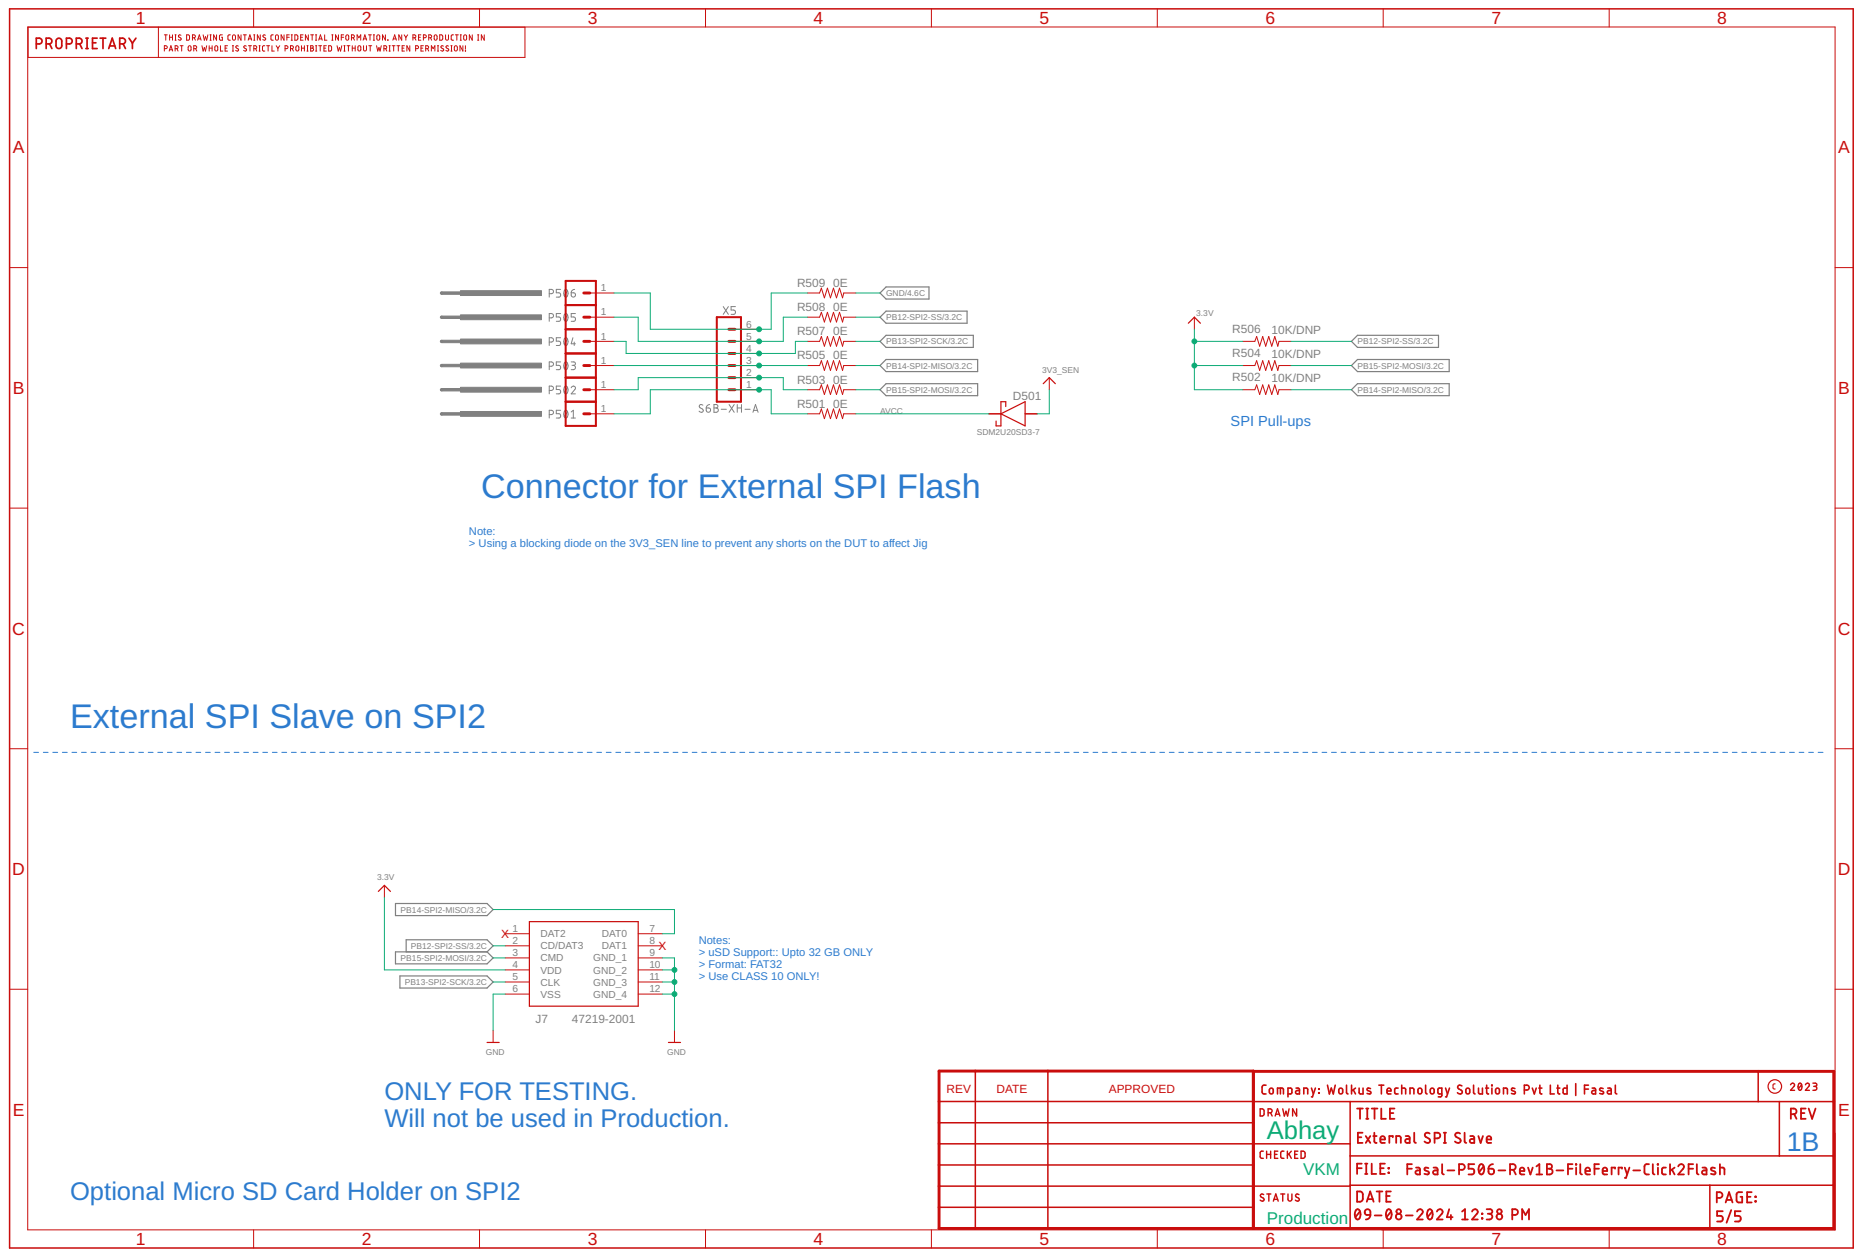
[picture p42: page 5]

Connector for External SPI Flash

Note: > Using a blocking diode on the 3V3_SEN line to prevent any shorts on the DUT to affect Jig

External SPI Slave on SPI2

Notes: > uSD Support:: Upto 32 GB ONLY

> Format: FAT32 > Use CLASS 10 ONLY!

ONLY FOR TESTING. Will not be used in Production. Optional Micro SD Card Holder on SPI2

REV | DATE | APPROVED

Abhay | 1B

VKM

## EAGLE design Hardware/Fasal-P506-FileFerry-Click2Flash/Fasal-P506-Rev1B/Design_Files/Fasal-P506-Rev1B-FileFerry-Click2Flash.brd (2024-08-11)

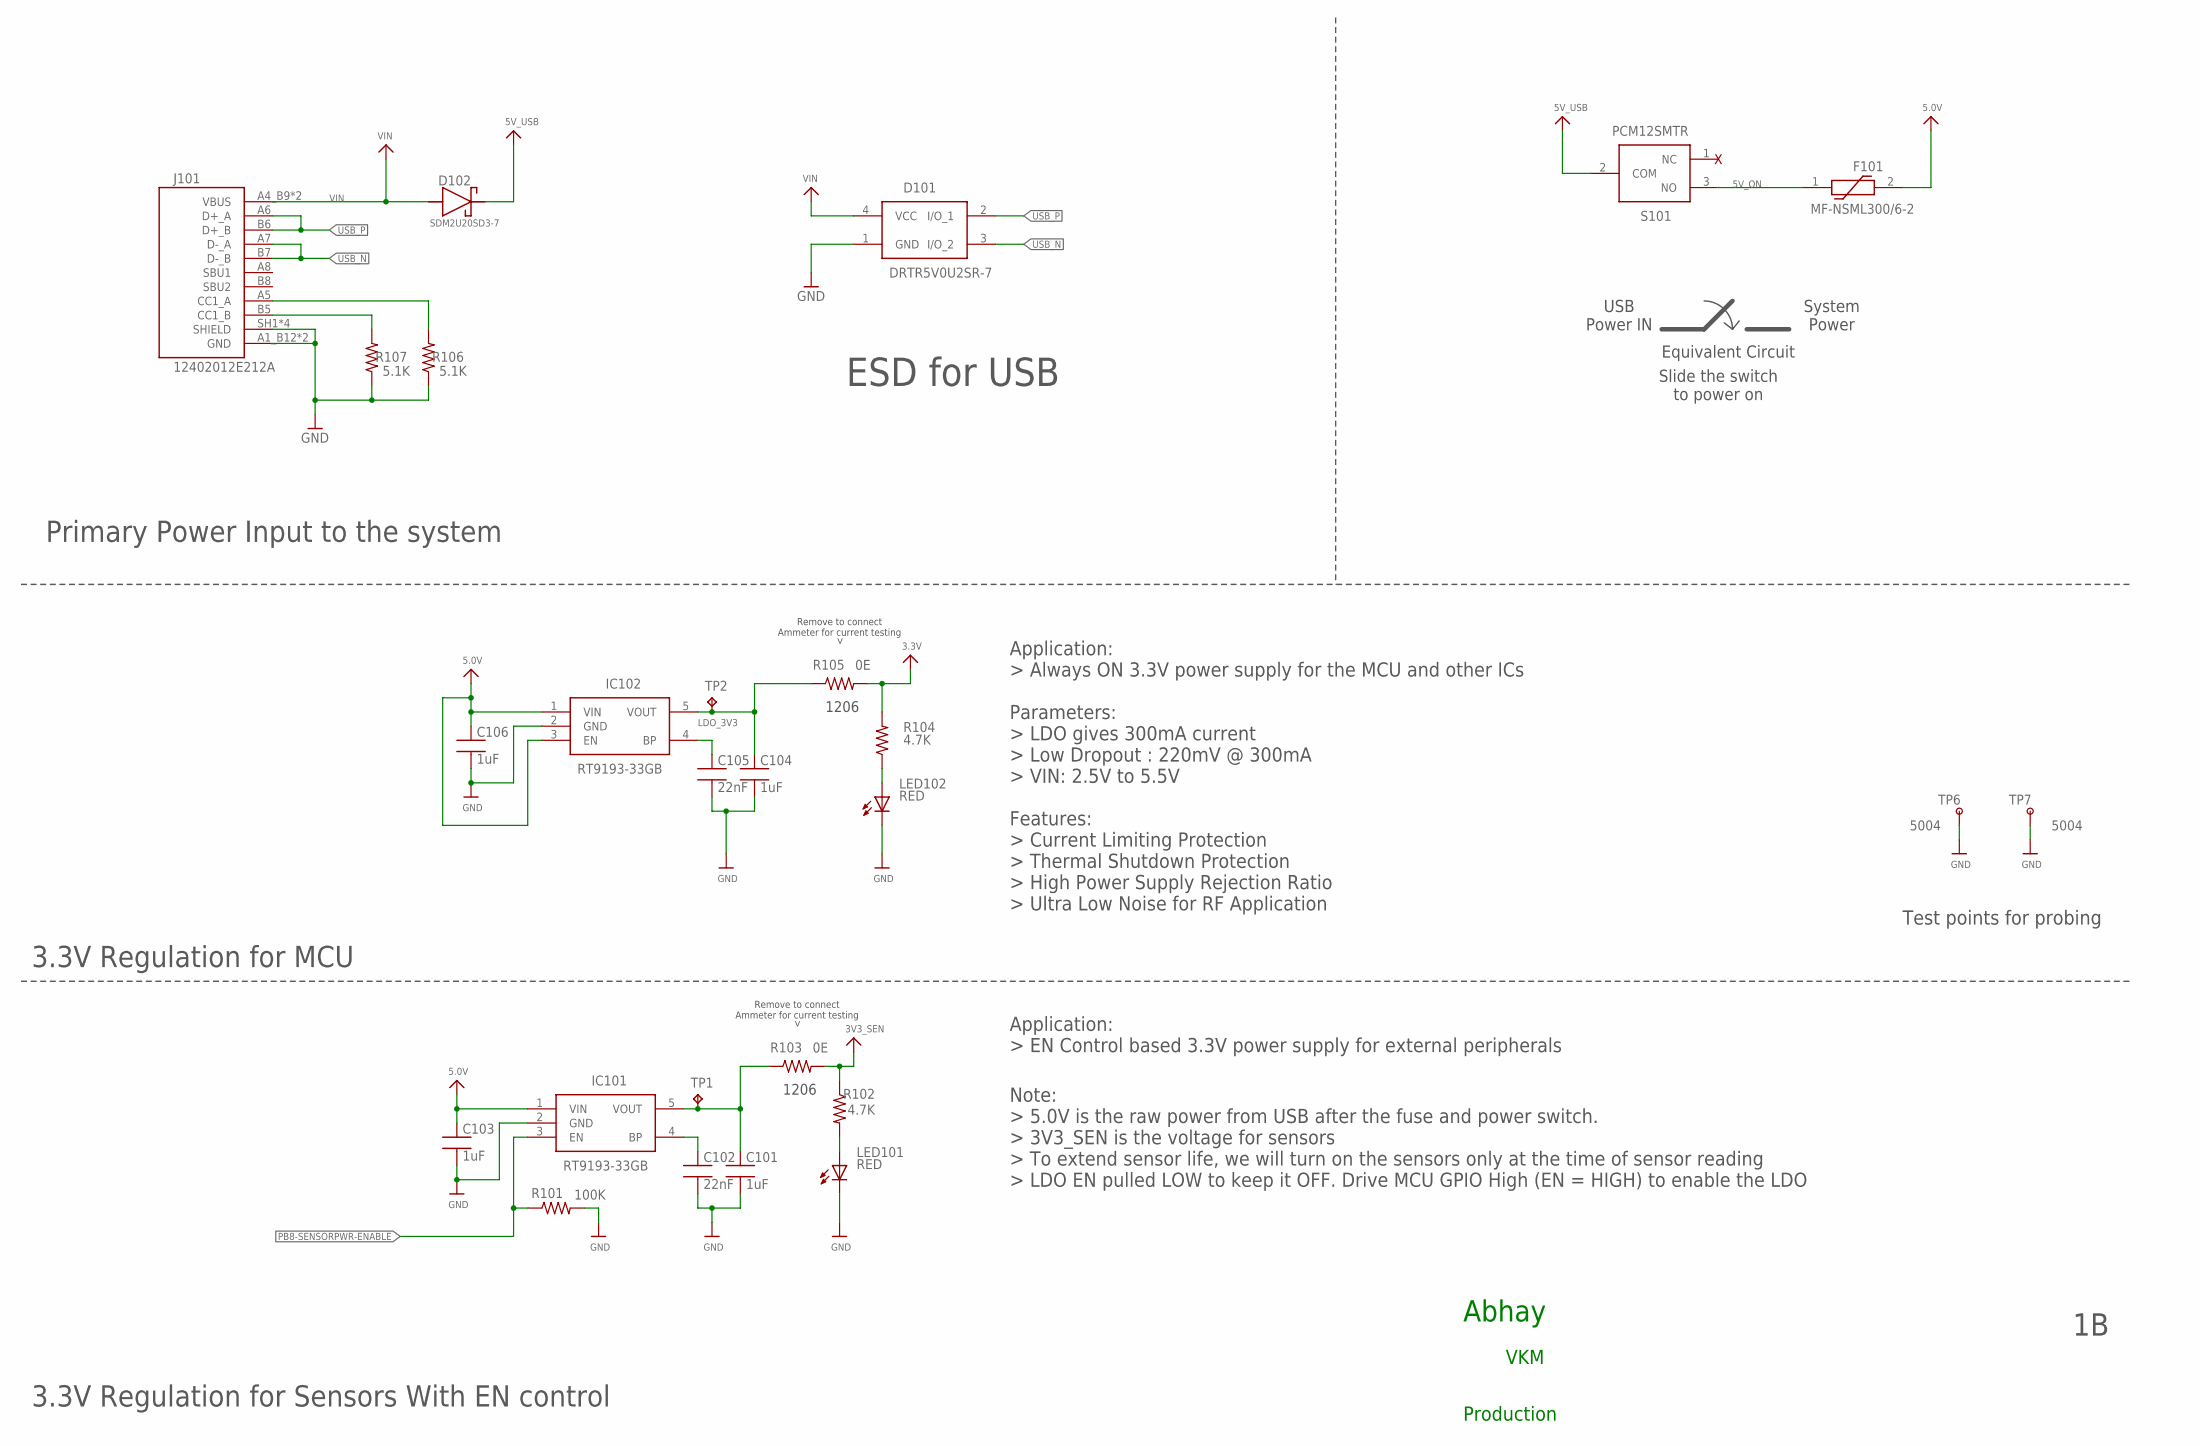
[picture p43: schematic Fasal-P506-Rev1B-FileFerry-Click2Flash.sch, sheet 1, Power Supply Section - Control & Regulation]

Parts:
C101, C103, C104, C106: 1uF; C0603
C102, C105: 22nF; C0603
D101: DRTR5V0U2SR-7; PRTR5V0U2X
D102: SDM2U20SD3-7; SOD2513X120N
F101: MF-NSML300/6-2; 1206L075SLYR
IC101, IC102: RT9193-33GB; SOT94P279X130-5N
J101: 12402012E212A; AMPHENOL_12402012E212A
LED101, LED102: RED; LED_CHIP_0603
R101: 100K; R0603
R102, R104: 4.7K; R0603
R103, R105: 0E; R0603
R106, R107: 5.1K; R0603
S101: PCM12SMTR
TP1, TP2: TPB1,27; B1,27
TP6, TP7: 5004

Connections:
3.3V: R104.2, R105.2; also elsewhere on the board
3V3_SEN: R102.1, R103.2; also elsewhere on the board
5.0V: C103.1, C106.1, F101.2, IC101.1 (VIN), IC102.1 (VIN), IC102.3 (EN); also elsewhere on the board
5V_ON: F101.1, S101.3 (NO)
5V_USB: D102.K, S101.2 (COM)
CC1: J101.A5 (CC1_A), R106.2
CC2: J101.B5 (CC1_B), R107.2
GND: C101.2, C102.2, C103.2, C104.2, C105.2, C106.2, D101.1 (GND), IC101.2 (GND), IC102.2 (GND), J101.A1_B12 (GND), J101.B1_A12 (GND), J101.SH1 (SHIELD), J101.SH2 (SHIELD), J101.SH3 (SHIELD), J101.SH4 (SHIELD), LED101.C, LED102.C, R101.2, R106.1, R107.1, TP6.1, TP7.1; also elsewhere on the board
LDO_3V3: C104.1, IC102.5 (VOUT), R105.1, TP2.TP
unnamed: LED102.A, R104.1
unnamed: C105.1, IC102.4 (BP)
unnamed: C101.1, IC101.5 (VOUT), R103.1, TP1.TP
unnamed: C102.1, IC101.4 (BP)
unnamed: LED101.A, R102.2
PB8-SENSORPWR-ENABLE: IC101.3 (EN), R101.1; also elsewhere on the board
USB_N: D101.3 (I/O_2), J101.A7 (D-_A), J101.B7 (D-_B); also elsewhere on the board
USB_P: D101.2 (I/O_1), J101.A6 (D+_A), J101.B6 (D+_B); also elsewhere on the board
VIN: D101.4 (VCC), D102.A, J101.A4_B9 (VBUS), J101.B4_A9 (VBUS); also elsewhere on the board

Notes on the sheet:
Abhay
3.3V Regulation for MCU
Application: > Always ON 3.3V power supply for the MCU and other ICs Parameters: > LDO gives 300mA current > Low Dropout : 220mV @ 300mA > VIN: 2.5V to 5.5V Features: > Current Limiting Protection > Thermal Shutdown Protection > High Power Supply Rejection Ratio > Ultra Low Noise for RF Application
Remove to connect Ammeter for current testing
Note: > 5.0V is the raw power from USB after the fuse and power switch. > 3V3_SEN is the voltage for sensors > To extend sensor life, we will turn on the sensors only at the time of sensor reading > LDO EN pulled LOW to keep it OFF. Drive MCU GPIO High (EN = HIGH) to enable the LDO
3.3V Regulation for Sensors With EN control
Application: > EN Control based 3.3V power supply for external peripherals
ESD for USB
Primary Power Input to the system
Slide the switch to power on
Equivalent Circuit
USB Power IN
System Power
VKM
Production
Test points for probing
1206

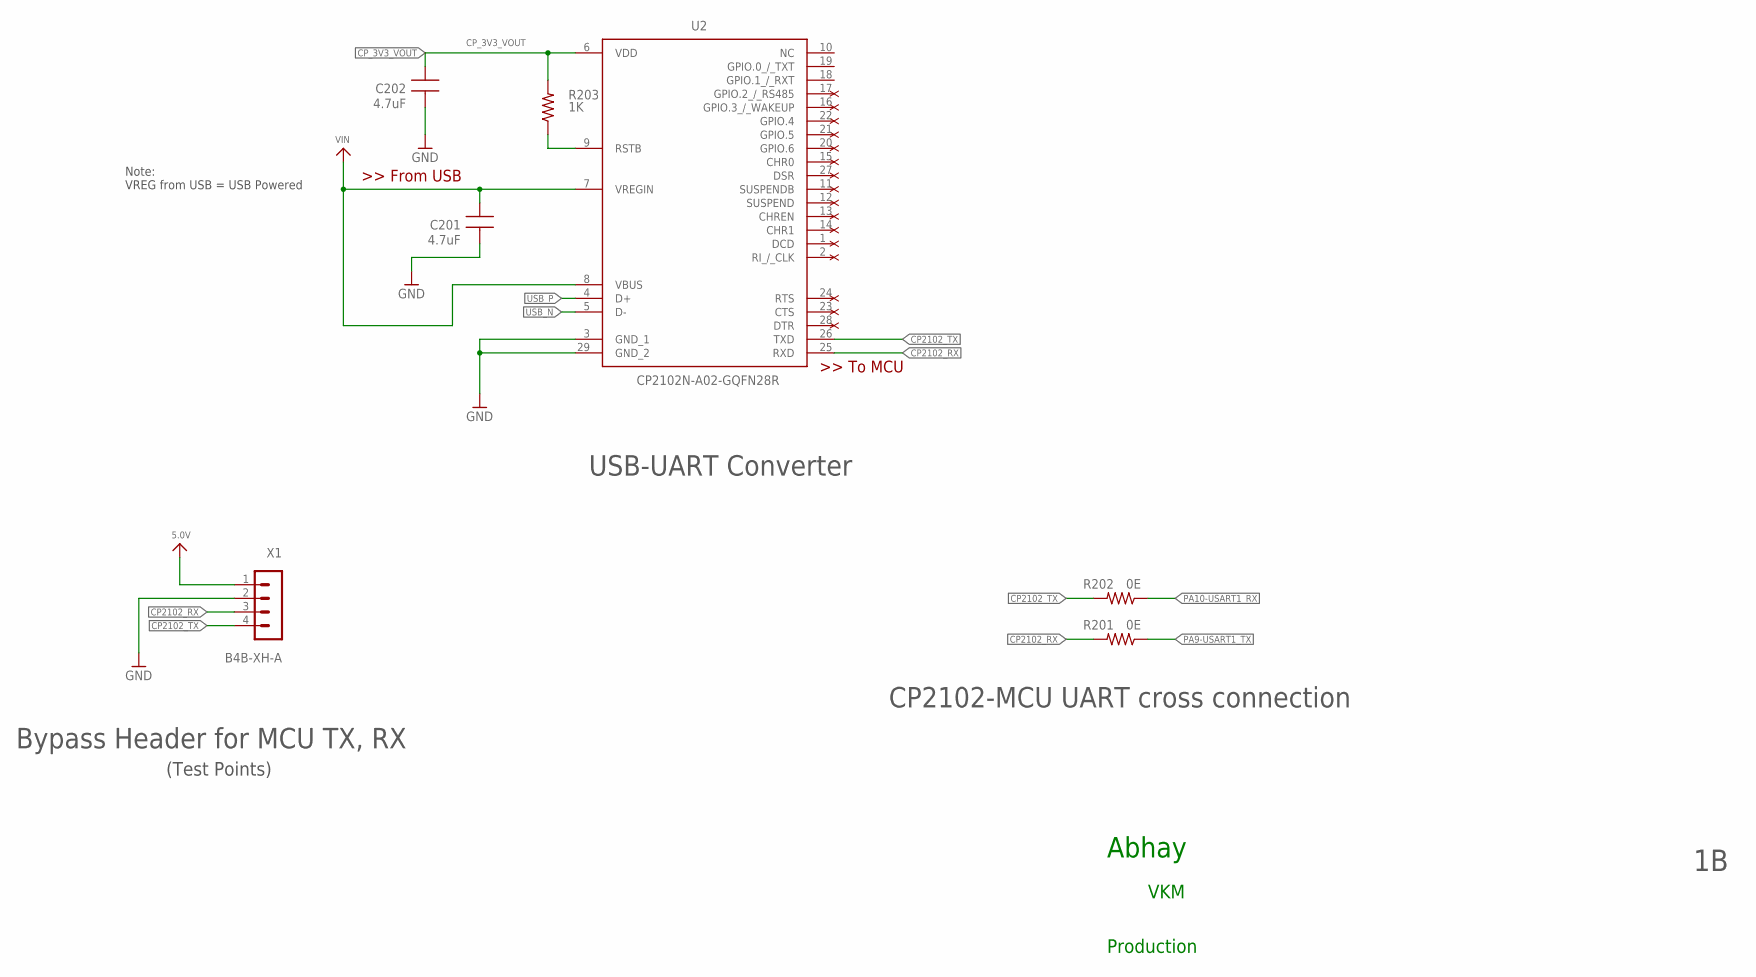
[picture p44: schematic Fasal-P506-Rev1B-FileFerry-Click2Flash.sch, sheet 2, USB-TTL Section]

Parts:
C201, C202: 4.7uF; C0603
R201, R202: 0E; R0603
R203: 1K; R0603
U2: CP2102N-A02-GQFN28R; QFN50P500X500X80-29N
X1: B4B-XH-A

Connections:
5.0V: X1.1; also elsewhere on the board
CP2102_RX: R201.2, U2.25 (RXD), X1.3
CP2102_TX: R202.2, U2.26 (TXD), X1.4
CP_3V3_VOUT: C202.1, R203.2, U2.6 (VDD)
GND: C201.2, C202.2, U2.3 (GND_1), U2.29 (GND_2), X1.2; also elsewhere on the board
unnamed: R203.1, U2.9 (RSTB)
PA9-USART1_TX: R201.1; also elsewhere on the board
PA10-USART1_RX: R202.1; also elsewhere on the board
USB_N: U2.5 (D-); also elsewhere on the board
USB_P: U2.4 (D+); also elsewhere on the board
VIN: C201.1, U2.7 (VREGIN), U2.8 (VBUS); also elsewhere on the board

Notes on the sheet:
Abhay
Note: VREG from USB = USB Powered
Bypass Header for MCU TX, RX
CP2102-MCU UART cross connection
USB-UART Converter
VKM
Production
(Test Points)

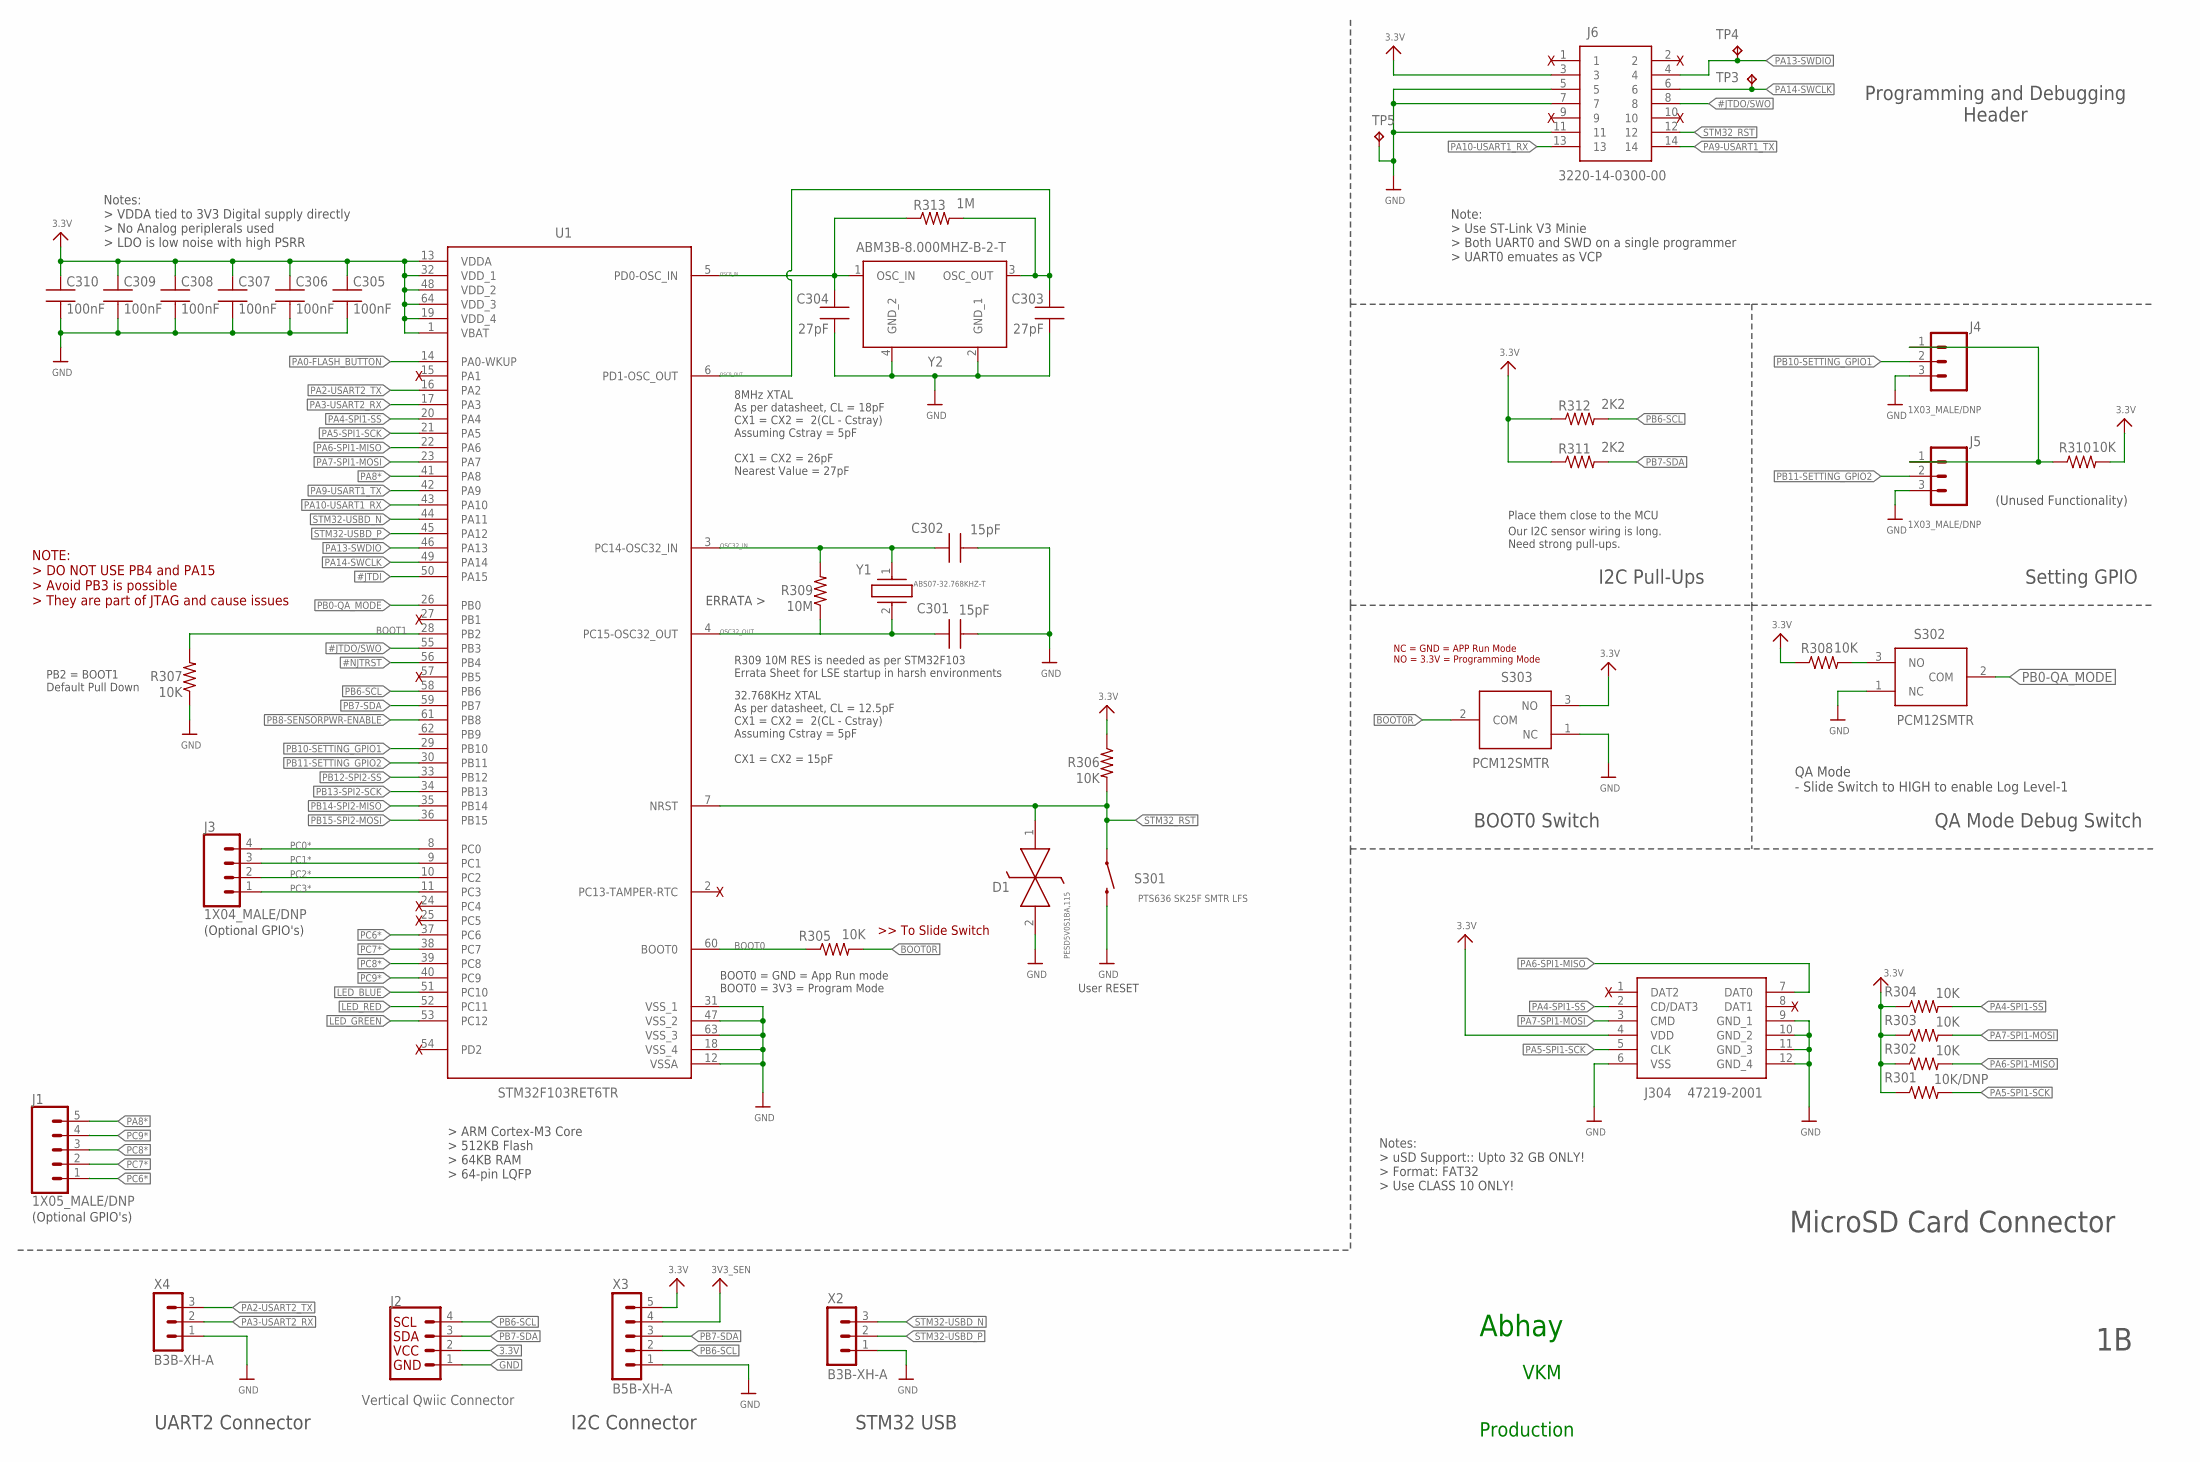
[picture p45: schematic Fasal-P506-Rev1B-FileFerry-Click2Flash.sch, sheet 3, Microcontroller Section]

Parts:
C301, C302: 15pF; C0603
C303, C304: 27pF; C0603
C305, C306, C307, C308, C309, C310: 100nF; C0603
D1: PESD5V0S1BA,115; SOD2512X110N
J1: 1X05_MALE/DNP; 1X05
J2: Vertical Qwiic Connector; JST04_1MM_VERT
J3: 1X04_MALE/DNP; 1X04
J4, J5: 1X03_MALE/DNP; 1X03
J6: 3220-14-0300-00; 322014030000
J304: 47219-2001; 472192001
R301: 10K/DNP; R0603
R302, R303, R304, R305, R306, R307, R308, R310: 10K; R0603
R309: 10M; R0603
R311, R312: 2K2; R0603
R313: 1M; R0603
S301: PTS636 SK25F SMTR LFS; TACTILE_SWITCH_SMD_6.0X3.5MM
S302, S303: PCM12SMTR
TP3, TP4, TP5: TPB1,27; B1,27
U1: STM32F103RET6TR; QFP50P1200X1200X160-64N
X2, X4: B3B-XH-A
X3: B5B-XH-A
Y1: ABS07-32.768KHZ-T; ABS07
Y2: ABM3B-8.000MHZ-B-2-T; ABM3B8000MHZB2T

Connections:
3.3V: C305.1, C306.1, C307.1, C308.1, C309.1, C310.1, J2.2, J6.3, J304.4 (VDD), R301.1, R302.1, R303.1, R304.1, R306.1, R308.1, R310.2, R311.1, R312.1, S303.3 (NO), U1.1 (VBAT), U1.13 (VDDA), U1.19 (VDD_4), U1.32 (VDD_1), U1.48 (VDD_2), U1.64 (VDD_3), X3.5; also elsewhere on the board
3V3_SEN: X3.4; also elsewhere on the board
#JTDI: U1.50 (PA15)
#JTDO/SWO: J6.8, U1.55 (PB3)
#NJTRST: U1.56 (PB4)
BOOT0: R305.1, U1.60 (BOOT0)
BOOT0R: R305.2, S303.2 (COM)
BOOT1: R307.2, U1.28 (PB2)
GND: C301.2, C302.2, C303.1, C304.1, C305.2, C306.2, C307.2, C308.2, C309.2, C310.2, D1.2 (K2), J2.1, J4.3, J5.3, J6.5, J6.7, J6.11, J304.6 (VSS), J304.9 (GND_1), J304.10 (GND_2), J304.11 (GND_3), J304.12 (GND_4), R307.1, S301.2, S302.1 (NC), S303.1 (NC), TP5.TP, U1.12 (VSSA), U1.18 (VSS_4), U1.31 (VSS_1), U1.47 (VSS_2), U1.63 (VSS_3), X2.1, X3.1, X4.1, Y2.2 (GND_1), Y2.4 (GND_2); also elsewhere on the board
LED_BLUE: U1.51 (PC10); also elsewhere on the board
LED_GREEN: U1.53 (PC12); also elsewhere on the board
LED_RED: U1.52 (PC11); also elsewhere on the board
unnamed: R308.2, S302.3 (NO)
unnamed: J4.1, J5.1, R310.1
OSC8_IN: C304.2, R313.1, U1.5 (PD0-OSC_IN), Y2.1 (OSC_IN)
OSC8_OUT: C303.2, R313.2, U1.6 (PD1-OSC_OUT), Y2.3 (OSC_OUT)
OSC32_IN: C302.1, R309.2, U1.3 (PC14-OSC32_IN), Y1.1
OSC32_OUT: C301.1, R309.1, U1.4 (PC15-OSC32_OUT), Y1.2
PA0-FLASH_BUTTON: U1.14 (PA0-WKUP); also elsewhere on the board
PA2-USART2_TX: U1.16 (PA2), X4.3
PA3-USART2_RX: U1.17 (PA3), X4.2
PA4-SPI1-SS: J304.2 (CD/DAT3), R304.2, U1.20 (PA4)
PA5-SPI1-SCK: J304.5 (CLK), R301.2, U1.21 (PA5)
PA6-SPI1-MISO: J304.7 (DAT0), R302.2, U1.22 (PA6)
PA7-SPI1-MOSI: J304.3 (CMD), R303.2, U1.23 (PA7)
PA8*: J1.5, U1.41 (PA8)
PA9-USART1_TX: J6.14, U1.42 (PA9); also elsewhere on the board
PA10-USART1_RX: J6.13, U1.43 (PA10); also elsewhere on the board
PA13-SWDIO: J6.4, TP4.TP, U1.46 (PA13)
PA14-SWCLK: J6.6, TP3.TP, U1.49 (PA14)
PB0-QA_MODE: S302.2 (COM), U1.26 (PB0)
PB6-SCL: J2.4, R312.2, U1.58 (PB6), X3.2
PB7-SDA: J2.3, R311.2, U1.59 (PB7), X3.3
PB8-SENSORPWR-ENABLE: U1.61 (PB8); also elsewhere on the board
PB10-SETTING_GPIO1: J4.2, U1.29 (PB10)
PB11-SETTING_GPIO2: J5.2, U1.30 (PB11)
PB12-SPI2-SS: U1.33 (PB12); also elsewhere on the board
PB13-SPI2-SCK: U1.34 (PB13); also elsewhere on the board
PB14-SPI2-MISO: U1.35 (PB14); also elsewhere on the board
PB15-SPI2-MOSI: U1.36 (PB15); also elsewhere on the board
PC0*: J3.4, U1.8 (PC0)
PC1*: J3.3, U1.9 (PC1)
PC2*: J3.2, U1.10 (PC2)
PC3*: J3.1, U1.11 (PC3)
PC6*: J1.1, U1.37 (PC6)
PC7*: J1.2, U1.38 (PC7)
PC8*: J1.3, U1.39 (PC8)
PC9*: J1.4, U1.40 (PC9)
STM32-USBD_N: U1.44 (PA11), X2.3
STM32-USBD_P: U1.45 (PA12), X2.2
STM32_RST: D1.1 (K1), J6.12, R306.2, S301.1, U1.7 (NRST)

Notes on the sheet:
Abhay
Programming and Debugging Header
QA Mode - Slide Switch to HIGH to enable Log Level-1
QA Mode Debug Switch
8MHz XTAL As per datasheet, CL = 18pF CX1 = CX2 = 2(CL - Cstray) Assuming Cstray = 5pF CX1 = CX2 = 26pF Nearest Value = 27pF
32.768KHz XTAL As per datasheet, CL = 12.5pF CX1 = CX2 = 2(CL - Cstray) Assuming Cstray = 5pF CX1 = CX2 = 15pF
R309 10M RES is needed as per STM32F103 Errata Sheet for LSE startup in harsh environments
User RESET
BOOT0 = GND = App Run mode BOOT0 = 3V3 = Program Mode
PB2 = BOOT1 Default Pull Down
I2C Pull-Ups
Place them close to the MCU
Our I2C sensor wiring is long. Need strong pull-ups.
MicroSD Card Connector
Notes: > uSD Support:: Upto 32 GB ONLY! > Format: FAT32 > Use CLASS 10 ONLY!
UART2 Connector
I2C Connector
Setting GPIO
STM32 USB
NOTE: > DO NOT USE PB4 and PA15 > Avoid PB3 is possible > They are part of JTAG and cause issues
NC = GND = APP Run Mode NO = 3.3V = Programming Mode
BOOT0 Switch
VKM
Production
ERRATA >
(Optional GPIO's)
Note: > Use ST-Link V3 Minie > Both UART0 and SWD on a single programmer > UART0 emuates as VCP
(Unused Functionality)
Notes: > VDDA tied to 3V3 Digital supply directly > No Analog periplerals used > LDO is low noise with high PSRR

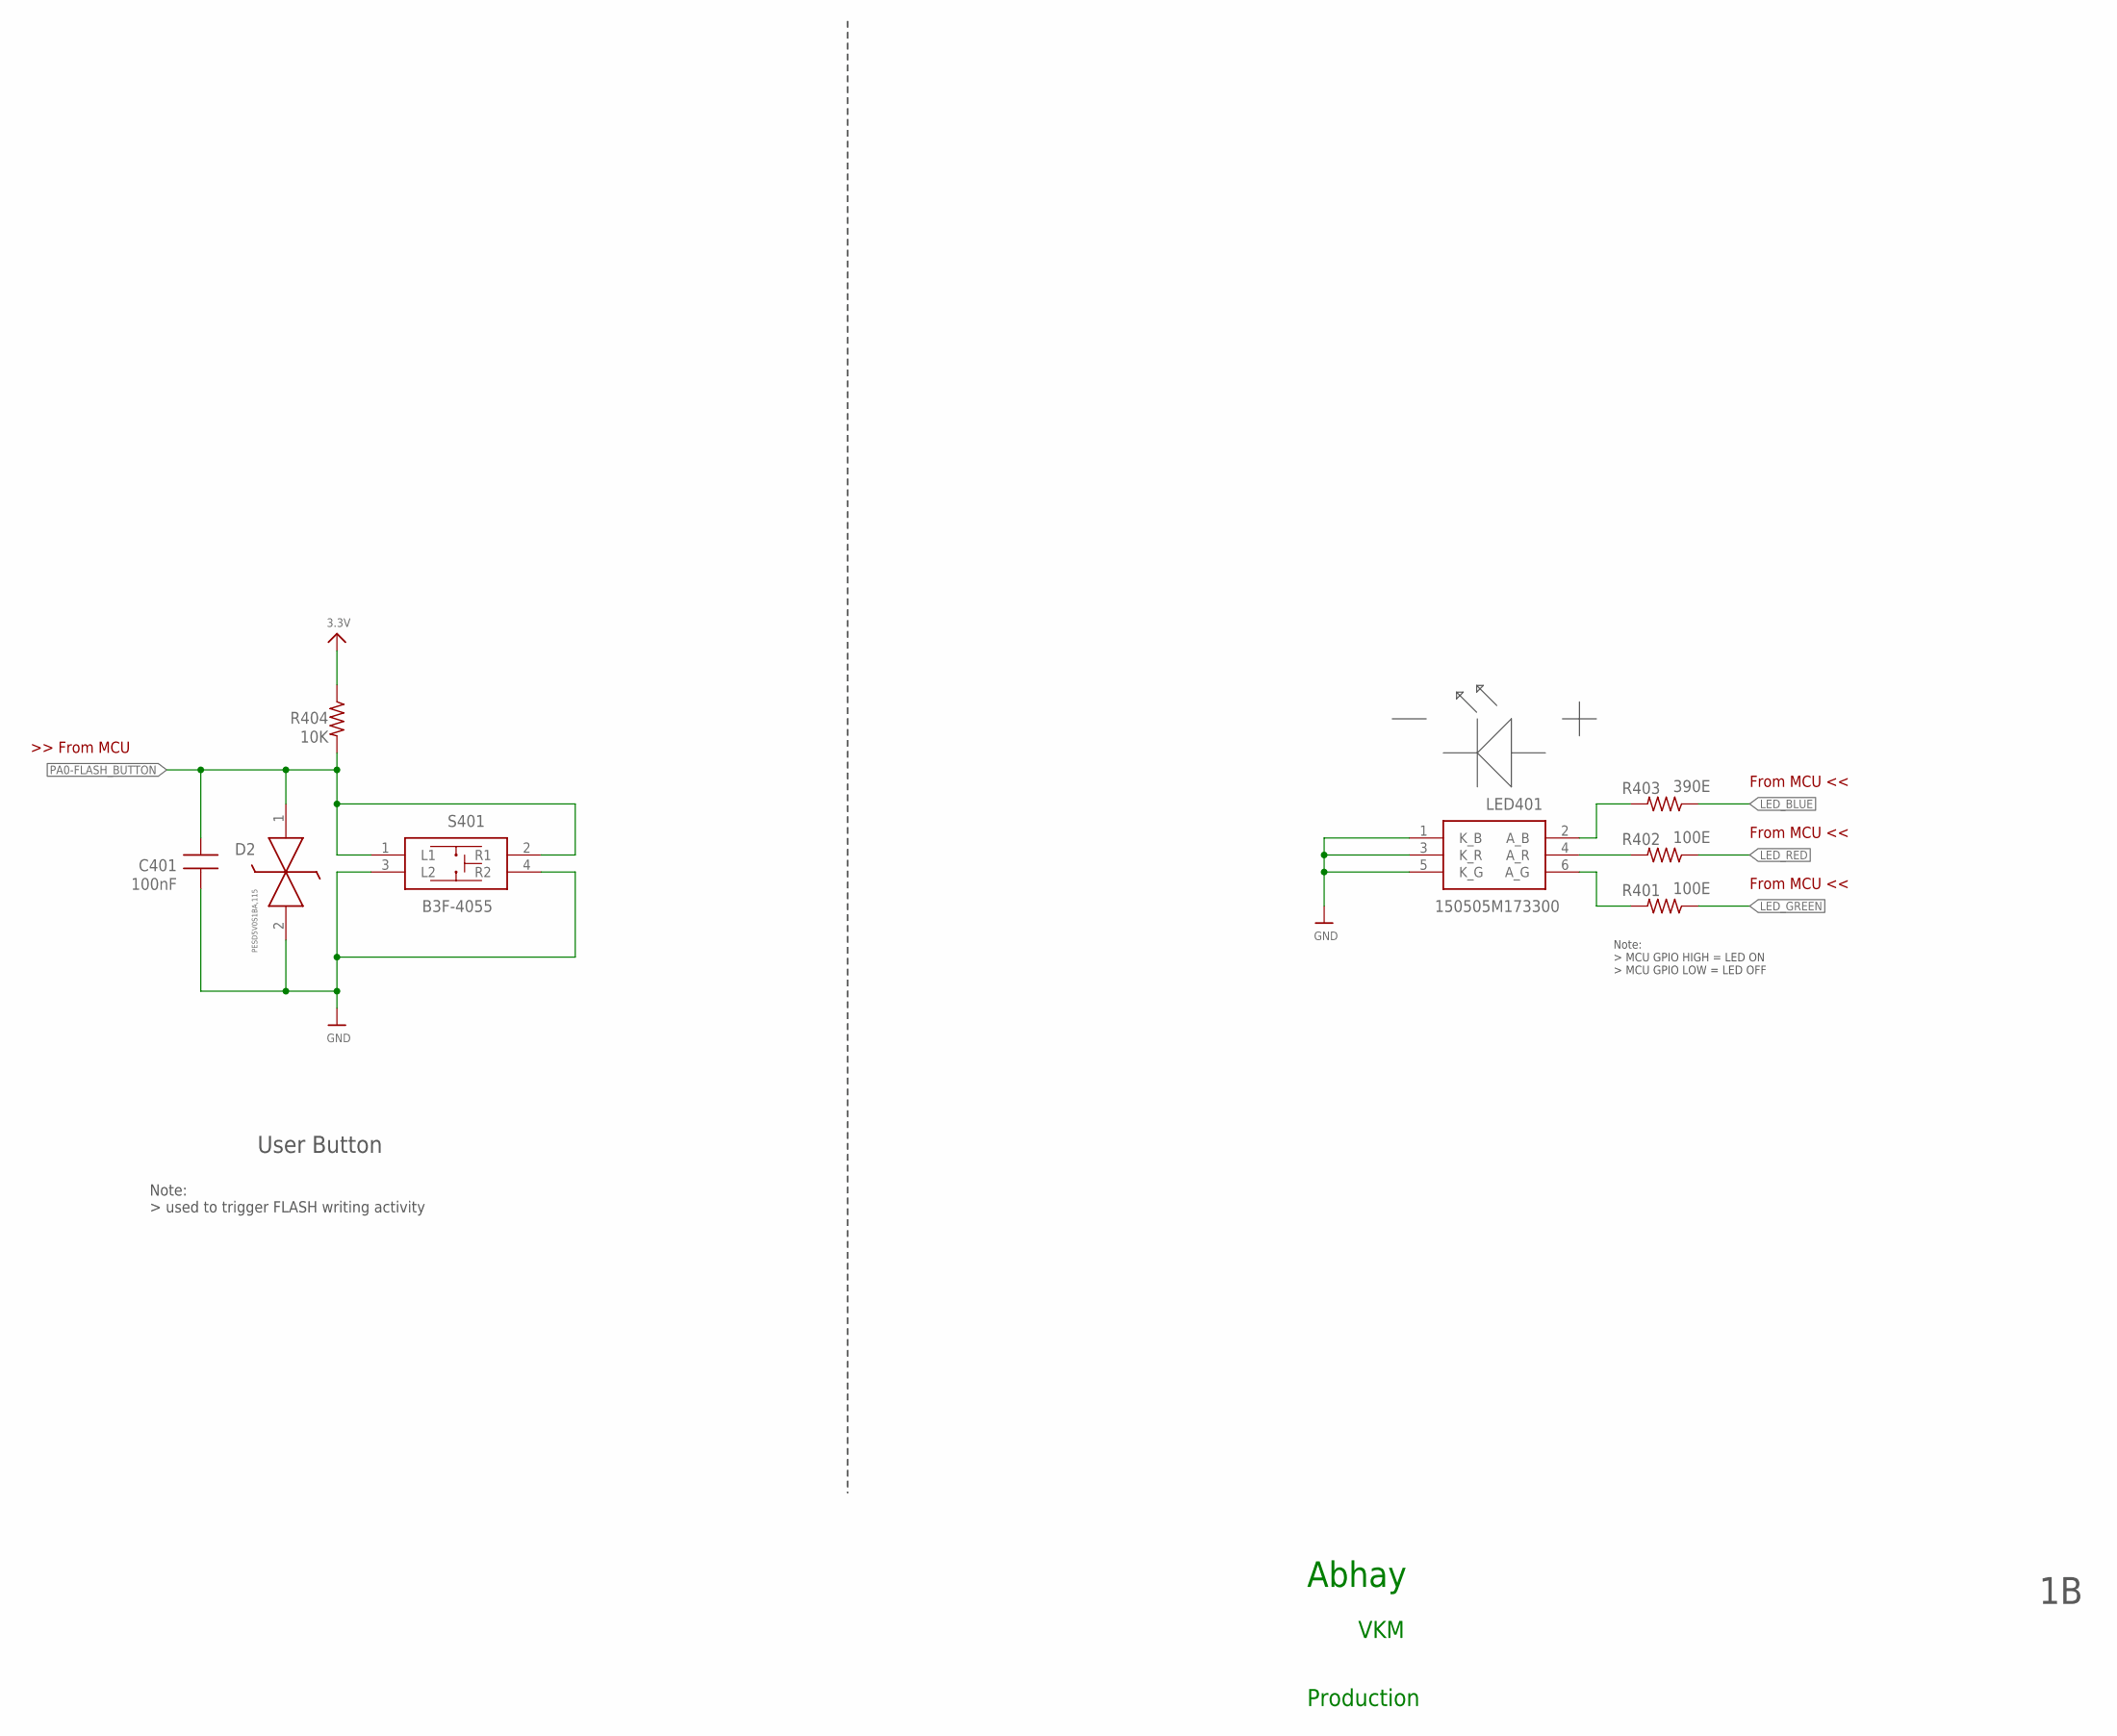
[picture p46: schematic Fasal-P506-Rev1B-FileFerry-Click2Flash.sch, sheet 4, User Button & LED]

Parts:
C401: 100nF; C0603
D2: PESD5V0S1BA,115; SOD2512X110N
LED401: 150505M173300
R401, R402: 100E; R0603
R403: 390E; R0603
R404: 10K; R0603
S401: B3F-4055

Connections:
3.3V: R404.1; also elsewhere on the board
GND: C401.2, D2.2 (K2), LED401.1 (K_B), LED401.3 (K_R), LED401.5 (K_G), S401.3 (L2), S401.4 (R2); also elsewhere on the board
LED_BLUE: R403.1; also elsewhere on the board
LED_GREEN: R401.1; also elsewhere on the board
LED_RED: R402.1; also elsewhere on the board
unnamed: LED401.4 (A_R), R402.2
unnamed: LED401.2 (A_B), R403.2
unnamed: LED401.6 (A_G), R401.2
PA0-FLASH_BUTTON: C401.1, D2.1 (K1), R404.2, S401.1 (L1), S401.2 (R1); also elsewhere on the board

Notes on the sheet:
Abhay
Note: > MCU GPIO HIGH = LED ON > MCU GPIO LOW = LED OFF
User Button
Note: > used to trigger FLASH writing activity
VKM
Production
From MCU <<

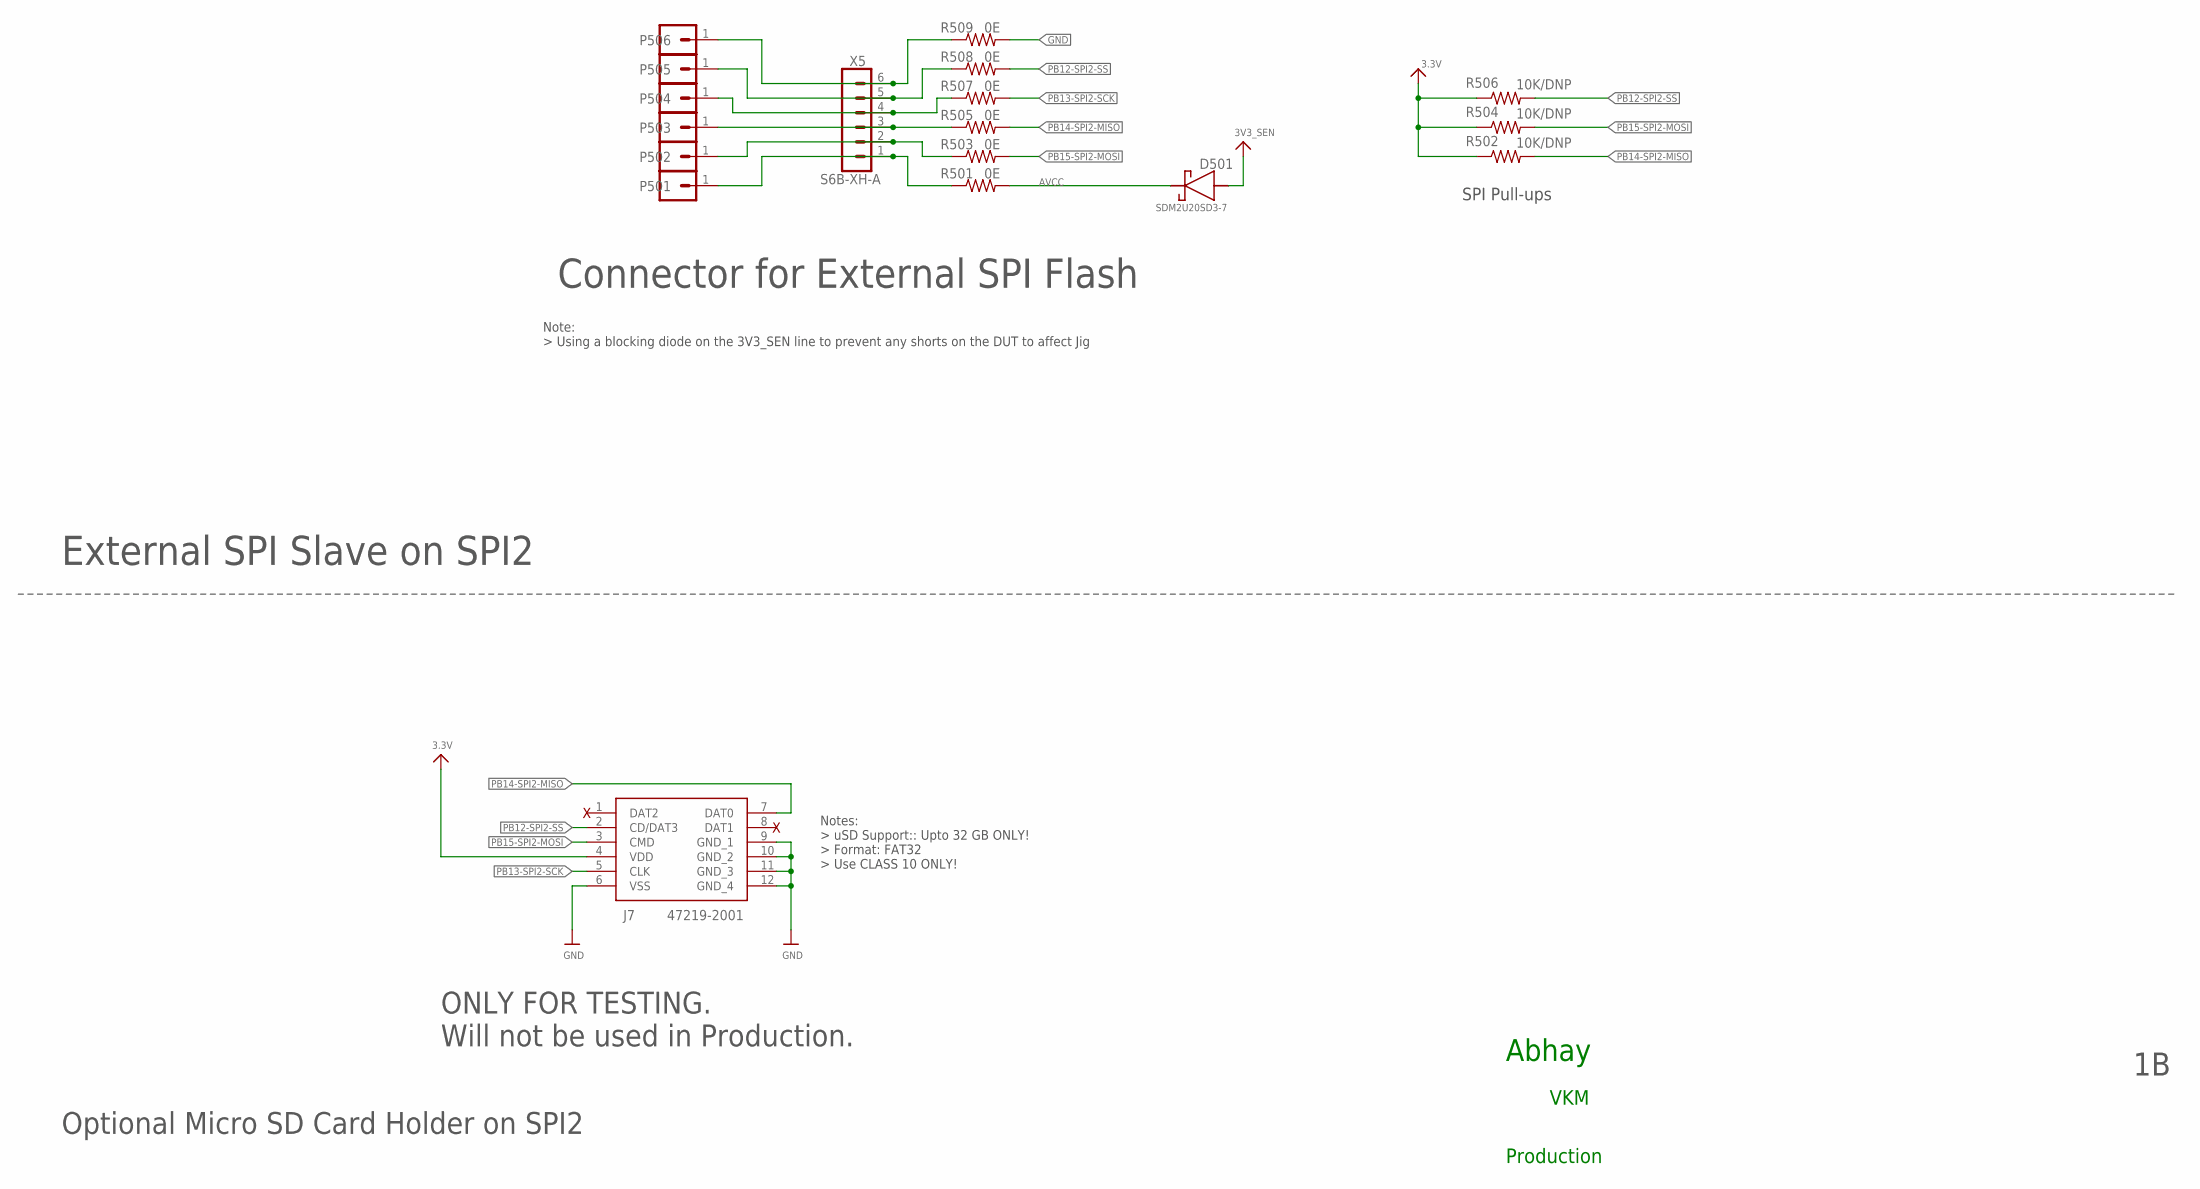
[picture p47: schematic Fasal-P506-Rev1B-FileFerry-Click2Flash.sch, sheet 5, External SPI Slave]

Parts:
D501: SDM2U20SD3-7; SOD2513X120N
J7: 47219-2001; 472192001
P501, P502, P503, P504, P505, P506: RA 1 pin; 1X01_SMD_PAD
R501, R503, R505, R507, R508, R509: 0E; R0603
R502, R504, R506: 10K/DNP; R0603
X5: S6B-XH-A

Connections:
3.3V: J7.4 (VDD), R502.1, R504.1, R506.1; also elsewhere on the board
3V3_SEN: D501.A; also elsewhere on the board
AVCC: D501.K, R501.2
GND: J7.6 (VSS), J7.9 (GND_1), J7.10 (GND_2), J7.11 (GND_3), J7.12 (GND_4), R509.2; also elsewhere on the board
PB12-SPI2-SS: J7.2 (CD/DAT3), R506.2, R508.2; also elsewhere on the board
PB13-SPI2-SCK: J7.5 (CLK), R507.2; also elsewhere on the board
PB14-SPI2-MISO: J7.7 (DAT0), R502.2, R505.2; also elsewhere on the board
PB15-SPI2-MOSI: J7.3 (CMD), R503.2, R504.2; also elsewhere on the board
TP-AVCC: P501.1, R501.1, X5.1
TP-GND: P506.1, R509.1, X5.6
TP-MISO: P503.1, R505.1, X5.3
TP-MOSI: P502.1, R503.1, X5.2
TP-SCK: P504.1, R507.1, X5.4
TP-SS: P505.1, R508.1, X5.5

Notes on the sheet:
Abhay
SPI Pull-ups
Connector for External SPI Flash
External SPI Slave on SPI2
Notes: > uSD Support:: Upto 32 GB ONLY! > Format: FAT32 > Use CLASS 10 ONLY!
ONLY FOR TESTING. Will not be used in Production.
Optional Micro SD Card Holder on SPI2
VKM
Production
Note: > Using a blocking diode on the 3V3_SEN line to prevent any shorts on the DUT to affect Jig

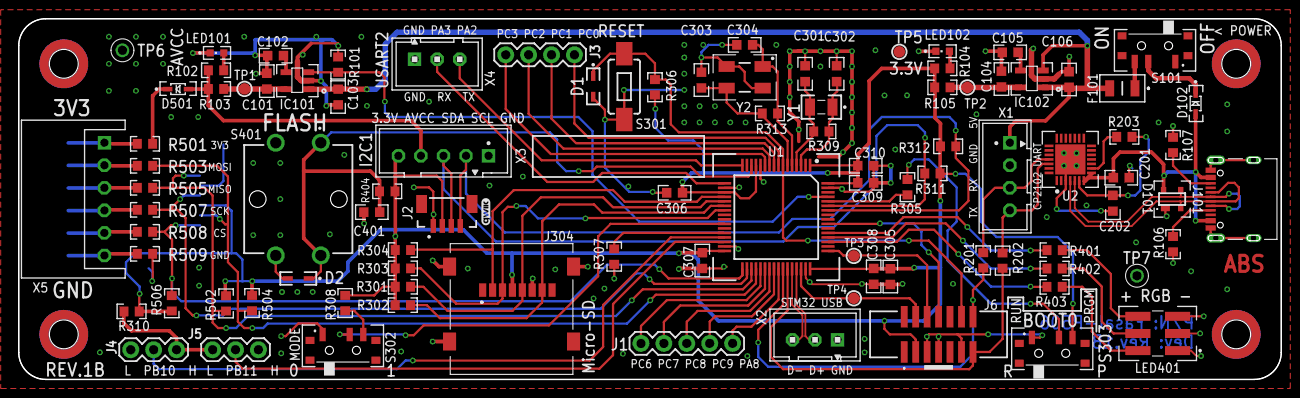
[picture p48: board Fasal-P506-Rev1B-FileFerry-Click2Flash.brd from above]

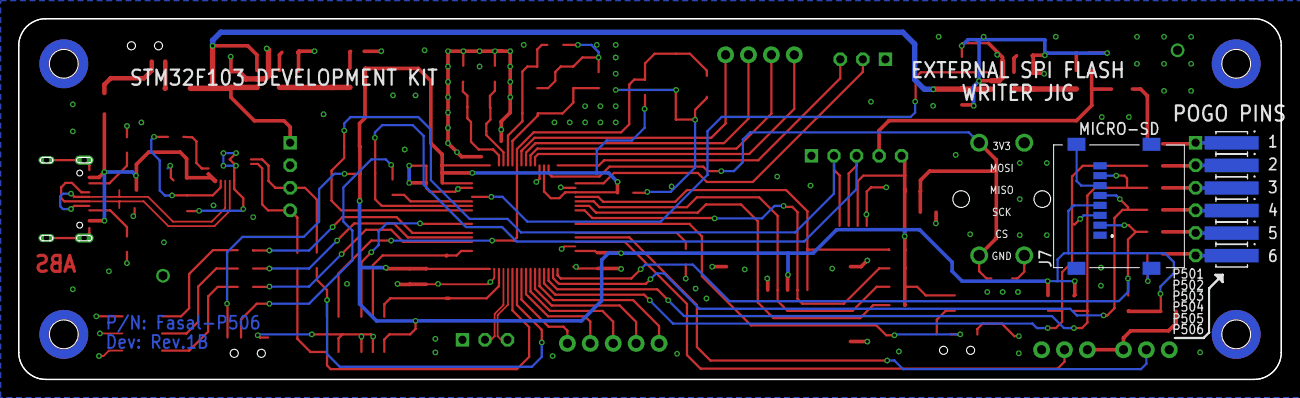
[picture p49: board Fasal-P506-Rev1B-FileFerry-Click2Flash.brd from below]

Board: 4 copper layers, 140.0 x 40.0 mm, 103 parts (7 on the bottom side), 77 nets.

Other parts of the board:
U$50: QWIIC_3MM

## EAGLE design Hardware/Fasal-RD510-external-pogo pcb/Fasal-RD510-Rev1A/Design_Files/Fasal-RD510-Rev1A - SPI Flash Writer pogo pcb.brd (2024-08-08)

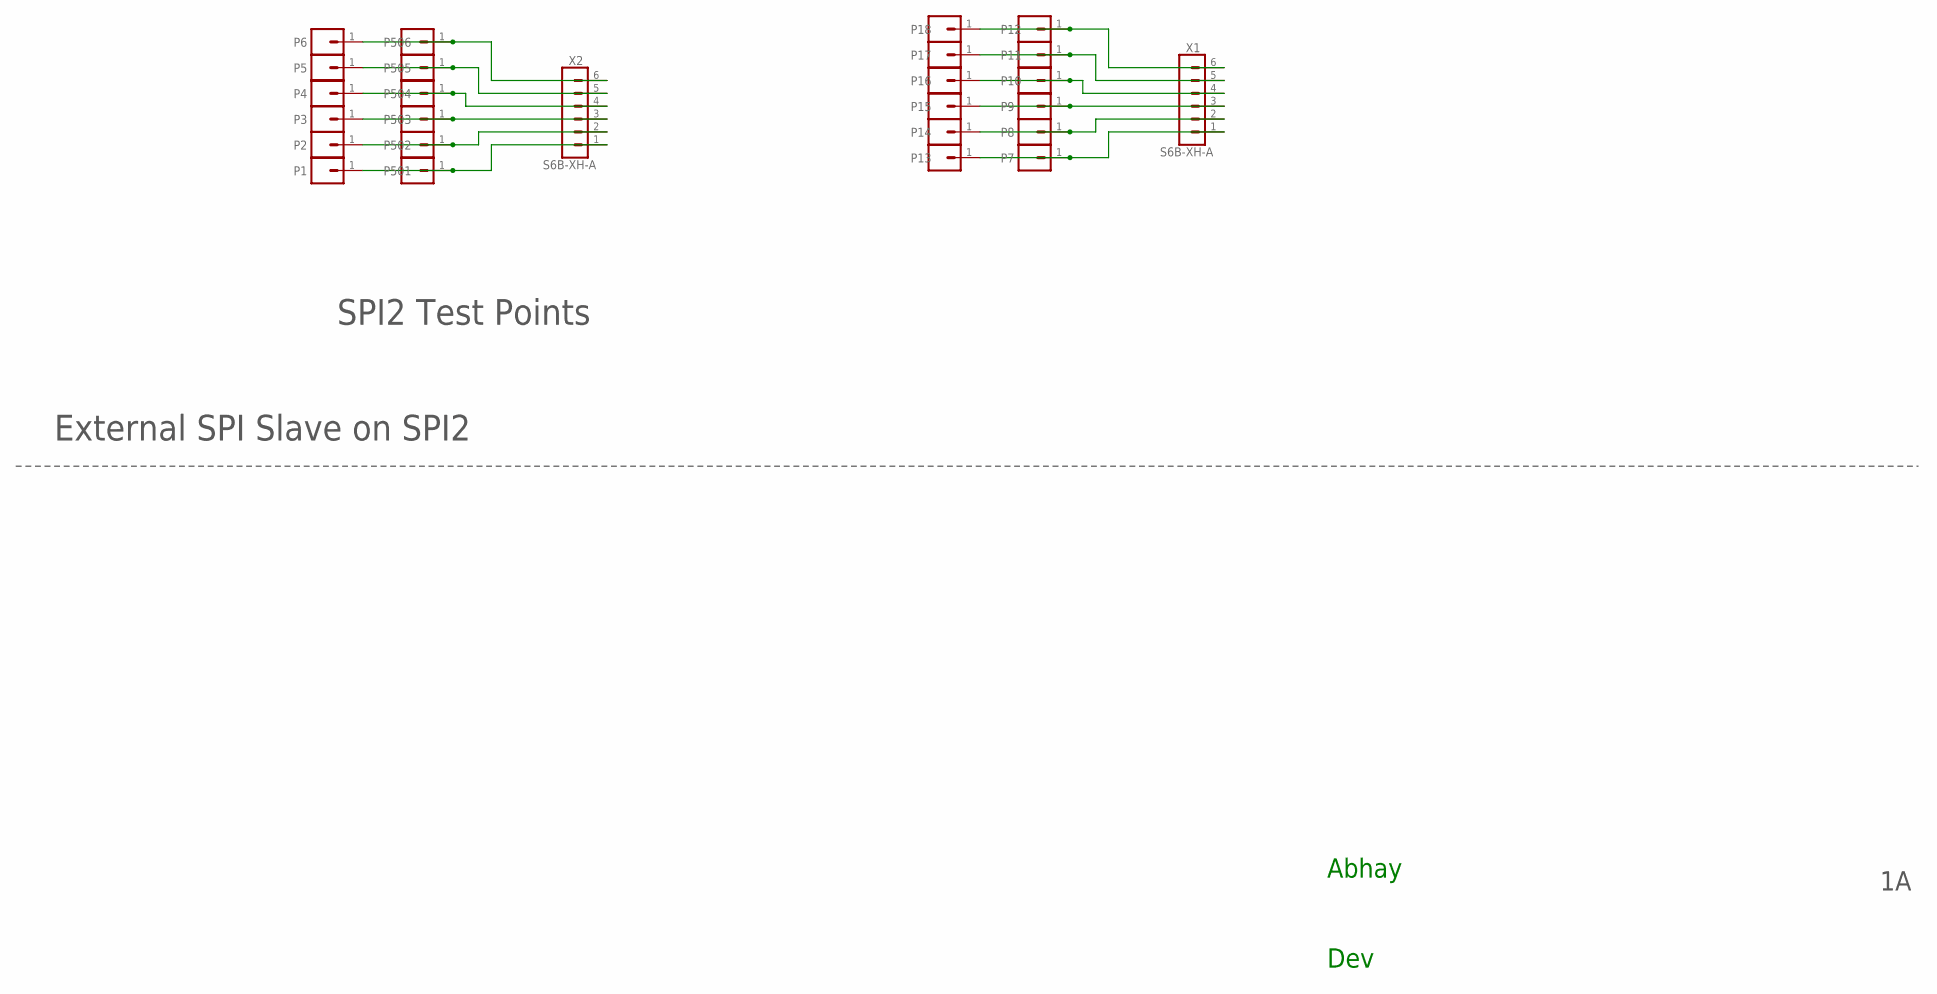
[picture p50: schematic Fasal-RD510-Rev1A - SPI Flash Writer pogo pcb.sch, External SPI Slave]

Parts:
P1, P2, P3, P4, P5, P6, P7, P8, P9, P10, P11, P12, P13, P14, P15, P16, P17, P18, P501, P502, P503, P504, P505, P506: RA 1 pin; 1X01_SMD_PAD
X1, X2: S6B-XH-A

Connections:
TP-AVCC: P1.1, P7.1, P13.1, P501.1, X1.1, X2.1
TP-GND: P6.1, P12.1, P18.1, P506.1, X1.6, X2.6
TP-MISO: P3.1, P9.1, P15.1, P503.1, X1.3, X2.3
TP-MOSI: P2.1, P8.1, P14.1, P502.1, X1.2, X2.2
TP-SCK: P4.1, P10.1, P16.1, P504.1, X1.4, X2.4
TP-SS: P5.1, P11.1, P17.1, P505.1, X1.5, X2.5

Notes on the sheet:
Abhay
Dev
SPI2 Test Points
External SPI Slave on SPI2

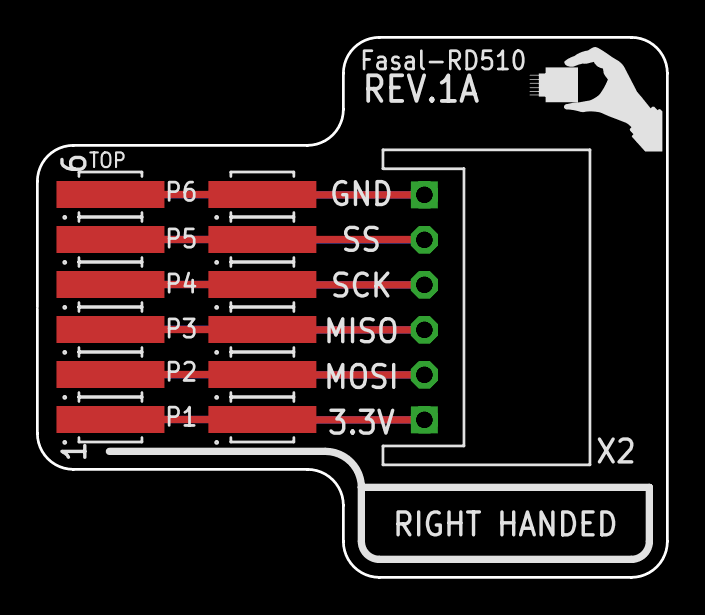
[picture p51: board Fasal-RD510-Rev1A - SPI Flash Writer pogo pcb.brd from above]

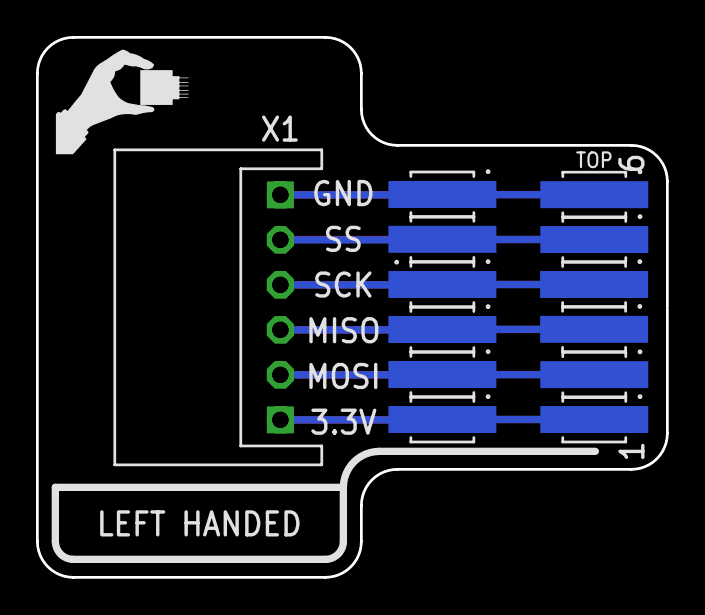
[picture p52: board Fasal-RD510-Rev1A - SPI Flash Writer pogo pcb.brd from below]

Board: 2 copper layers, 35.0 x 30.0 mm, 26 parts (13 on the bottom side), 6 nets.

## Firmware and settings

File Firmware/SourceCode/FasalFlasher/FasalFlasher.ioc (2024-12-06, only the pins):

Mcu.UserName=STM32F103RETx
PA0-WKUP.GPIO_Label=FLASH_BUTTON
PA0-WKUP.Signal=GPXTI0
PA10.Signal=USART1_RX
PA13.Signal=SYS_JTMS-SWDIO
PA14.Signal=SYS_JTCK-SWCLK
PA2.Signal=USART2_TX
PA3.Signal=USART2_RX
PA4.GPIO_Label=SPI1_NSS
PA4.Signal=GPIO_Output
PA5.Signal=SPI1_SCK
PA6.Signal=SPI1_MISO
PA7.Signal=SPI1_MOSI
PA9.Signal=USART1_TX
PB0.GPIO_Label=TRANSFER_MODE
PB0.Signal=GPIO_Input
PB10.GPIO_Label=SETTING_GPIO1
PB10.Signal=GPIO_Input
PB11.GPIO_Label=SETTING_GPIO2
PB11.Signal=GPIO_Input
PB12.GPIO_Label=SPI2_NSS
PB12.Signal=GPIO_Output
PB13.Signal=SPI2_SCK
PB14.Signal=SPI2_MISO
PB15.Signal=SPI2_MOSI
PB2.GPIO_Label=BOOT1
PB2.Signal=GPIO_Input
PB3.GPIO_Label=LED_G1
PB3.Signal=GPIO_Output
PB4.GPIO_Label=LED_B1
PB4.Signal=GPIO_Output
PB5.GPIO_Label=LED_R1
PB5.Signal=GPIO_Output
PB6.Signal=I2C1_SCL
PB7.Signal=I2C1_SDA
PB8.GPIO_Label=SENSOR_POWER_ENABLE
PB8.Signal=GPIO_Output
PC10.GPIO_Label=LED_B
PC10.Signal=GPIO_Output
PC11.GPIO_Label=LED_R
PC11.Signal=GPIO_Output
PC12.GPIO_Label=LED_G
PC12.Signal=GPIO_Output
PC13-TAMPER-RTC.Signal=RTC_TAMPER
PC14-OSC32_IN.Signal=RCC_OSC32_IN
PC15-OSC32_OUT.Signal=RCC_OSC32_OUT
PD0-OSC_IN.Signal=RCC_OSC_IN
PD1-OSC_OUT.Signal=RCC_OSC_OUT

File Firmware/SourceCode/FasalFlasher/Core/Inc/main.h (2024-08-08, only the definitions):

#define FLASH_BUTTON_Pin GPIO_PIN_0
#define FLASH_BUTTON_GPIO_Port GPIOA
#define SPI1_NSS_Pin GPIO_PIN_4
#define SPI1_NSS_GPIO_Port GPIOA
#define TRANSFER_MODE_Pin GPIO_PIN_0
#define TRANSFER_MODE_GPIO_Port GPIOB
#define BOOT1_Pin GPIO_PIN_2
#define BOOT1_GPIO_Port GPIOB
#define SETTING_GPIO1_Pin GPIO_PIN_10
#define SETTING_GPIO1_GPIO_Port GPIOB
#define SETTING_GPIO2_Pin GPIO_PIN_11
#define SETTING_GPIO2_GPIO_Port GPIOB
#define SPI2_NSS_Pin GPIO_PIN_12
#define SPI2_NSS_GPIO_Port GPIOB
#define LED_B_Pin GPIO_PIN_10
#define LED_B_GPIO_Port GPIOC
#define LED_R_Pin GPIO_PIN_11
#define LED_R_GPIO_Port GPIOC
#define LED_G_Pin GPIO_PIN_12
#define LED_G_GPIO_Port GPIOC
#define LED_G1_Pin GPIO_PIN_3
#define LED_G1_GPIO_Port GPIOB
#define LED_B1_Pin GPIO_PIN_4
#define LED_B1_GPIO_Port GPIOB
#define LED_R1_Pin GPIO_PIN_5
#define LED_R1_GPIO_Port GPIOB
#define SENSOR_POWER_ENABLE_Pin GPIO_PIN_8
#define SENSOR_POWER_ENABLE_GPIO_Port GPIOB

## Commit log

2024-08-08 Hardware design files added
    [Fasal-P506-Rev1A-BOM.xlsx, Fasal-P506-Rev1B-BOM.xlsx, Fasal-P506-Rev1B-SPI_Flash_Writer_Jig.brd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]
2024-08-08 added hardware design files
    Hardware design files added
    [Fasal-P506-Rev1A-BOM.xlsx, Fasal-P506-Rev1B-BOM.xlsx, Fasal-P506-Rev1B-SPI_Flash_Writer_Jig.brd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]
2024-08-08 Update Fasal-P506-Rev1B - PCB Fabrication Instructions.txt
2024-08-09 directory restructure
    [Fasal-P506-Rev1A-BOM.xlsx, Fasal-P506-Rev1B-BOM.xlsx, Fasal-P506-Rev1B-SPI_Flash_Writer_Jig.brd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]
2024-08-09 directory restructure and BOM update
    [Fasal-P506-Rev1B-BOM.xlsx, Fasal-P506-Rev1B-SPI_Flash_Writer_Jig.brd, Fasal-P506-Rev1B-SPI_Flash_Writer_Jig.sch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]
2024-08-09 design update
    [DRILEGEND.CFG, Fasal-P506-Rev1B-FileFerry-Click2Flash.brd, Fasal-P506-Rev1B-FileFerry-Click2Flash.sch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]
2024-08-11 Added board bring-up code
2024-08-11 schematic pdf update
2024-08-11 Gerber update
    [Fasal-P506-Rev1B-FileFerry-Click2Flash.brd, Fasal-P506-Rev1B-FileFerry-Click2Flash.sch]
2024-12-06 * build: 1. Code updated to V1.1 2. Migrated from Cube HAL version V1.8.5 to V1.8.6 3. Added clang formatter and Auto doc generation scripts to codeBase
    feat:
    1. SoftTimer module enhanced to automatically compute overflow time based on clock configuration
    fix:
    1. Improved log messages during setup failure conditions
    style:
    1. Ran clang formatter over User files
    docs:
    1. Regenerated design files
    [AppFlash_API.c]

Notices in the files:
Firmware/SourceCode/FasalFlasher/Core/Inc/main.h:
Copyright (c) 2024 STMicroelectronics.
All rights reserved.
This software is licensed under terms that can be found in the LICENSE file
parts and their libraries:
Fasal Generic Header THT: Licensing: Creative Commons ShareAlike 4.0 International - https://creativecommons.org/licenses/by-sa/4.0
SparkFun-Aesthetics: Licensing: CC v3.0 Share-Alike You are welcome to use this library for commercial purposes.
